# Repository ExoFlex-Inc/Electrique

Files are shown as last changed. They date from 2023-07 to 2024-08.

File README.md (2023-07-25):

# ExoFlex Électrique

ExoFlex Électrique est la référence à toutes les questions en lien avec les composantes et les schémas électriques.

## Description des capteurs

### Capteur de pression

Les capteurs de pression seront essentiellement utilisé avec les sangles qui seront conçues par l'équipe mécanique. Ce capteur va permettre de vérifier la pression entre la sangle et la jambe du patient afin de procurer un confort à l'utilisateur.

### IMU

L'IMU utilisé aura un accéléromètre et un gyroscope d'intégré à celui-ci. Ce capteur va nous permettre de spécifier des repères pour déterminer les positions cibles à atteindre lors des étirements. Le capteur qui sera utilisé pour le banc de test sera le MPU6050 fabriqué par DFROBOT.



- La tension opérationnelle sera de 3 à 5V (Vin)
- Mise à la terre (GND)
- Communication i2c (sda et scl)
- interrupt(INT)

### Capteur de fin de course

Ces capteurs seront utilisés pour arrêter les mouvements du robot si jamais il vient à dépasser la limite physique imposé. Ici on utilise des limit switch avec le numéro de modèle: SPDT 1NO 1NC fabriqué par InduSKY.



### Potentiomètre

Les potentiomètres rotatifs vont nous servir à déterminer l'angle des joints, afin de faire un suivit du mouvement du robot. Ici on utilise les potentiomètres fabriqué par OSEPP ELECTRONICS.



## Descriptions des actuateurs

à remplir

## Overview schéma électrique et conception PCB

à remplir

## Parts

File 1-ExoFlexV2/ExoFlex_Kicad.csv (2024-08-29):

Comment | Designator | Footprint | LCSC
10uF 10V X7R | C1,C29,C30,C31,C32,C33,C34,C35,C36,C37,C38,C39,C40,C41,C47,C48,C49,C85 | Capacitor_SMD:C_0805_2012Metric
47nF 50V X7R | C10 | Capacitor_SMD:C_1206_3216Metric
1uF 10% 20V | C11,C213,C214 | FootPrintLib:CAPMP3216X180N
47uF 10V X5R | C13,C14 | Capacitor_SMD:C_0805_2012Metric
330uF 10% 10V | C15,C16 | FootPrintLib:CAPMP7.6X4.3_3.1N_KEM
10nF 50V | C17,C18,C19,C20,C21,C22,C23,C24,C25,C26,C27,C28,C42,C43,C44,C45,C46,C50,C51,C52,C53,C54,C61,C62,C69,C70,C77,C78 | Capacitor_SMD:C_0805_2012Metric
220uF 20% 50V | C2 | FootPrint:CAP_EEHZS1H221P
100uF 20% 35V | C3,C5,C12 | FootPrintLib:CAP_K1V101P_PAN
33uF 50V X7R | C4 | FootPrintLib:CAPC6153X500N
0,1uF | C55,C56,C57,C58,C59,C60,C71,C72,C73,C74,C75,C76,C87,C88,C89,C90,C91,C92,C103,C104,C105,C106,C107,C119,C120,C121,C122,C123,C133,C134,C135,C136,C137,C147,C148,C149,C150,C151,C161,C162,C163,C164,C165,C166,C167,C168,C169,C170,C171,C172,C173,C174,C175,C176,C177,C178,C179,C180,C181,C182,C183,C184,C185,C186,C187,C188,C189,C190,C191,C192,C193,C194,C195,C196,C197,C198,C199,C200,C201,C202,C203,C204,C205,C206,C207,C208,C209,C210,C211,C212,C215,C216 | Capacitor_SMD:C_0402_1005Metric
2.2uF 50V X5R | C6 | Capacitor_SMD:C_0805_2012Metric
1uF | C63,C64,C65,C66,C67,C68,C79,C80,C81,C82,C83,C84,C95,C96,C97,C98,C99,C100,C111,C112,C113,C114,C115,C126,C127,C128,C129,C130,C140,C141,C142,C143,C144,C154,C155,C156,C157,C158 | Capacitor_SMD:C_0402_1005Metric
4,7uF 35V X7R | C7,C8 | Capacitor_SMD:C_0805_2012Metric
0.47UF 16V X7R | C9 | Capacitor_SMD:C_0805_2012Metric
SHOTT 30V 12A | D1,D2 | FootPrint:DIO_SS12P2L-M3_86A
LED | D115,D116,D117,D118 | FootPrintLib:WL-SMCW_0603
TVS | D3,D4,D5,D6,D7,D8,D9,D10,D11,D12,D13,D14,D15,D16,D17,D18,D19,D20,D21,D22,D23,D24,D25,D26,D27,D28,D29,D30,D31,D32,D33,D34,D35,D36,D37,D38,D39,D40,D41,D42,D43,D44,D45,D46,D47,D48,D49,D50,D51,D52,D53,D54,D55,D56,D57,D58,D59,D60,D61,D62,D63,D64,D65,D66,D67,D68,D69,D70,D71,D72,D73,D74,D75,D76,D77,D78,D79,D80,D81,D82,D83,D84,D85,D86,D87,D88,D89,D90,D91,D92,D93,D94,D95,D96,D97,D98,D99,D100,D101,D102,D103,D104,D105,D106,D107,D108,D109,D110,D111,D112,D113,D114,D119,D120,D121,D122,D123,D124,D125,D126,D127,D128,D129,D130,D131,D132,D133,D134,D135,D136,D137,D138,D139,D140,D141,D142,D143,D144,D145,D146,D147,D148,D149,D150,D151,D152,D153,D154,D155,D156,D157,D158,D159,D160,D161,D162,D163,D164,D165,D166,D167,D168,D169,D170,D171,D172,D173,D174,D178,D179,D180,D181,D182,D183,D184,D185 | FootPrint:DPY2_TEX
Fuse | F1 | FootPrint:696108003002
Fiducial | FID1,FID2,FID3 | Fiducial:Fiducial_0.5mm_Mask1.5mm
MH | H2,H3,H4,H5,H6,H7,H8,H9,H10,H11,H12,H13,H14 | MountingHole:MountingHole_4.3mm_M4
14 AWG | J1,J3,J81 | FootPrintLib:PHOENIX_1755736
30POS | J10 | FootPrintLib:SAMTEC_SSW-115-01-G-D
10POS | J11 | FootPrintLib:SAMTEC_SSW-110-01-G-D
34POS | J12 | FootPrintLib:SAMTEC_SSW-117-01-G-D
3POS | J13,J14,J15,J19,J20,J21,J22,J23,J24,J53,J54 | FootPrint:CON_39301039
39281083 | J16,J17,J18 | FootPrint:MOLEX_0039281083
Jumper | J2,J5,J6,J55,J56,J58,J59,J66,J67,J68,J69,J70,J72,J73,J74,J82,J84,J85,J86,J87,J88,J89,J90,J91,J92,J93,J94,J95,J96,J97,J98,J99,J100,J101,J102,J103,J104,J105,J106,J107,J108,J109,J110,J111,J115,J116,J117,J118,J119,J120,J121,J122,J123,J124,J125,J126,J127,J131,J132 | Connector_PinHeader_2.54mm:PinHeader_1x03_P2.54mm_Vertical
2POS | J4,J25,J26,J27,J28,J29,J30,J31,J32,J33,J34,J35,J36,J37,J38,J46,J47,J48,J52 | FootPrintLib:CON_39281023
4POS | J39,J40,J41,J42,J49,J50,J51 | FootPrint:CON_39301049
5POS | J43,J44,J45 | FootPrint:CON_39302050
6POS | J57 | Connector_PinSocket_2.54mm:PinSocket_1x06_P2.54mm_Vertical
Tulip Conn | J60,J61,J62,J63,J64,J65,J75,J76,J77,J78,J79,J80 | Connector_PinSocket_2.54mm:PinSocket_1x02_P2.54mm_Vertical
Jumper 5,2A | J7,J71 | Connector_PinHeader_2.54mm:PinHeader_1x03_P2.54mm_Vertical
USB-C | J8 | FootPrintLib:MOLEX_1054500101
16POS | J9 | FootPrintLib:SAMTEC_SSW-108-01-G-D
Relay | K1 | FootPrint:UD2_NU_KEM-L
1uH 20% 2,3A | L1,L2 | Inductor_SMD:L_1210_3225Metric
10uH 10% 150mA | L3 | FootPrintLib:INDC2012X145N
MOSFET 20V 200mA | Q1 | FootPrint:DIO_RB558WMF_ROM
10K 1% 1/10W | R1,R4,R49,R50,R51,R82,R83,R84,R85,R86,R87,R92,R93,R94,R98,R99,R100,R101,R102,R103,R110,R115,R116,R121,R122,R123,R124,R146,R147,R148,R188,R189,R190,R191,R192,R193,R206,R207,R208,R215,R216,R217,R218,R219,R220,R221,R233,R234,R235,R236,R237,R238,R239,R240,R241,R242,R243,R245,R246,R247,R248,R249,R259,R260,R261,R262,R265,R266,R273,R274,R275,R276,R284 | Resistor_SMD:R_0603_1608Metric
1K 1% 1/10W | R11,R12,R13,R14,R15,R16,R17,R18,R19,R20,R21,R22,R23,R24,R29,R30,R31,R283 | Resistor_SMD:R_0603_1608Metric
165 1% 1/8W | R114,R120 | Resistor_SMD:R_0805_2012Metric
464 1% 1/8W | R119,R168 | Resistor_SMD:R_0805_2012Metric
2,2k 1% 1/2W | R184 | Resistor_SMD:R_0805_2012Metric
210 1% 1/8W | R197,R198,R199,R200,R201,R202 | Resistor_SMD:R_0805_2012Metric
5.1K 1% 1/10W | R2,R76,R104,R105,R106,R107,R108,R109,R111,R112,R117,R118,R125,R126,R127,R128,R149,R150,R151,R169,R176,R177,R285 | Resistor_SMD:R_0603_1608Metric
200k 1% 1/8W | R223,R226,R229 | Resistor_SMD:R_0805_2012Metric
100K 1% 1/10W | R25,R26,R27,R28,R32,R33,R34,R53,R54,R56,R71,R72,R75,R88,R90,R91,R113,R131,R132,R133,R134,R135,R136,R140,R141,R142,R143,R144,R145,R152,R153,R154,R158,R159,R160,R161,R162,R163,R166,R167,R170,R171,R172,R173,R174,R175,R182,R183,R194,R195,R196,R244,R252,R253,R254,R263,R264,R277,R278,R282 | Resistor_SMD:R_0603_1608Metric
200k 5% 1/8W | R35,R36,R37 | Resistor_SMD:R_0805_2012Metric
910k 0,1% 1/8W | R38,R39,R45,R59,R60,R66 | Resistor_SMD:R_0805_2012Metric
0Ω | R3,R8,R9,R10,R40,R41,R42,R43,R44,R48,R61,R62,R63,R64,R65,R67,R79,R80,R81,R129,R130,R137,R138,R139,R155,R156,R157,R164,R165,R181,R186,R187,R203,R204,R205,R212,R213,R214,R224,R227,R230,R232,R257,R258,R271,R272,R279,R280 | Resistor_SMD:R_0805_2012Metric
270 0,1% 1/4W | R46 | Resistor_SMD:R_0805_2012Metric
270 1% 1/4W | R47,R185 | Resistor_SMD:R_0805_2012Metric
5.49k 1% 1/8W | R5 | Resistor_SMD:R_0805_2012Metric
3.3k 1% 1/8W | R52,R68,R69,R70,R77,R78,R95,R96,R97,R178,R179,R180,R209,R210,R211,R222,R231,R250,R251,R255,R256,R267,R268,R269,R270 | Resistor_SMD:R_0805_2012Metric
530 0.5% 1/8W | R55 | Resistor_SMD:R_0805_2012Metric
270 1% 1/8W | R57 | Resistor_SMD:R_0805_2012Metric
820 1% 1/8W | R58 | Resistor_SMD:R_0805_2012Metric
100 1% 1/8W | R6 | Resistor_SMD:R_0805_2012Metric
8.66k 1% 1/8W | R7 | Resistor_SMD:R_0805_2012Metric
240 1% 1/8W | R73 | Resistor_SMD:R_0805_2012Metric
360 1% 1/8W | R74,R281 | Resistor_SMD:R_0805_2012Metric
100k 1% 1/8W | R89,R225,R228 | Resistor_SMD:R_0805_2012Metric
Trim 10k | RV1,RV2,RV3,RV4,RV5,RV6,RV7,RV27 | FootPrint:TRIM_3362P-1-103LF
TestPoint | TP1,TP2,TP3,TP4,TP5,TP6,TP7,TP8,TP9,TP10,TP11,TP12,TP13,TP14,TP15,TP16,TP17,TP18,TP19,TP20,TP21,TP22,TP23,TP24,TP25,TP26,TP27,TP28,TP29,TP30,TP31,TP32,TP37,TP38,TP39,TP40,TP41,TP42,TP46,TP59,TP60,TP61,TP62,TP63,TP64,TP68,TP81,TP84,TP85,TP92,TP93,TP94,TP95,TP96,TP97,TP98,TP99,TP103,TP107,TP108,TP109,TP110,TP111,TP112,TP113,TP117,TP118,TP119,TP120,TP121,TP124,TP125,TP126,TP127,TP128 | FootPrint:KEYSTONE_5005
TVS 24V | U1,U14 | FootPrint:SOT-23-3_DBZ_TEX
XNOR Gate | U10 | FootPrintLib:SC-74A_SOT753_NEX
MUX 8:1 | U12,U13,U121,U122 | FootPrint:SOT403-1_NXP
LDO -5VA | U123 | FootPrintLib:T03B_TEX
LDO 5VA | U124 | FootPrintLib:T03B_TEX
OR GATE 3IN | U15,U16,U32,U49,U50,U53 | FootPrintLib:SOT95P280X145-6N
OP_AMP2 | U17,U18,U19,U23,U24,U31,U33,U34,U35,U36,U37,U38,U39,U40,U41,U56,U57 | FootPrintLib:SOIC127P599X175-8N
Shott 100V | U2 | FootPrint:D2PAK_STM
COMP | U20,U21,U22,U28,U29,U30,U67,U68,U69,U79,U80,U81,U85,U86 | FootPrint:DGK8
INST OP-AMP | U25,U26,U27 | FootPrint:D0008A_SOIC_TEX
Inverter | U3,U11,U42,U43,U44,U45,U46,U47,U48,U51,U52,U58,U59 | FootPrint:SN74LVC3G14DCUT
SR-Latch | U4 | FootPrintLib:SOP65P640X120-16N
DCDC24V/8V | U5 | FootPrintLib:PTN78060WAD
DCDC24V/5V NUM | U6 | FootPrint:NDY0011A_L
AND Gate | U60,U62,U63,U64,U65,U70,U71,U76,U77,U82,U83 | FootPrint:SOT95P270X145-5N
DCDC 24V/-7,8V ANA | U7 | FootPrintLib:PTN78000
OR Gate 8 | U8,U9,U54,U55 | FootPrint:D14

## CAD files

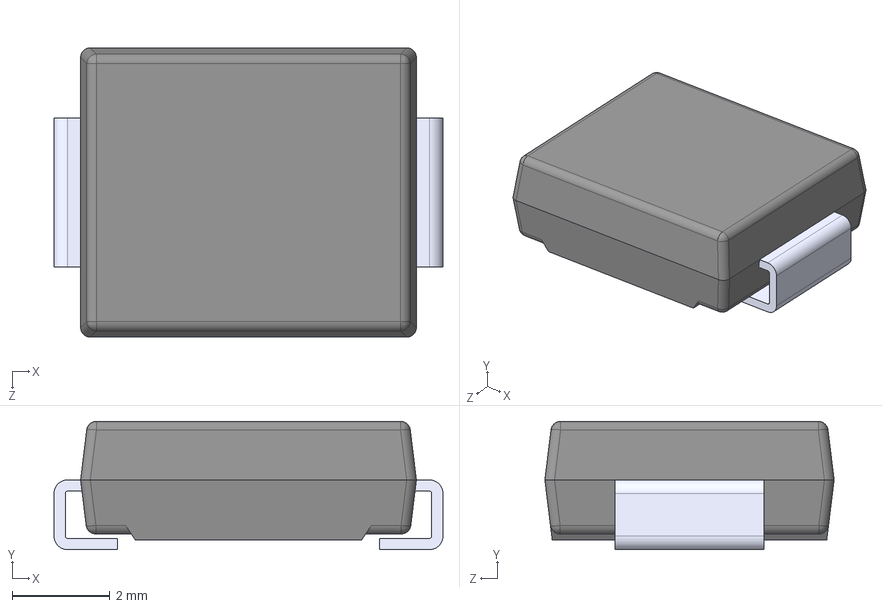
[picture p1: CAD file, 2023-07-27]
1-ExoFlexV2/DIOM6859X262N/DIOM6859X262N.step
7.94 x 2.62 x 5.90 mm

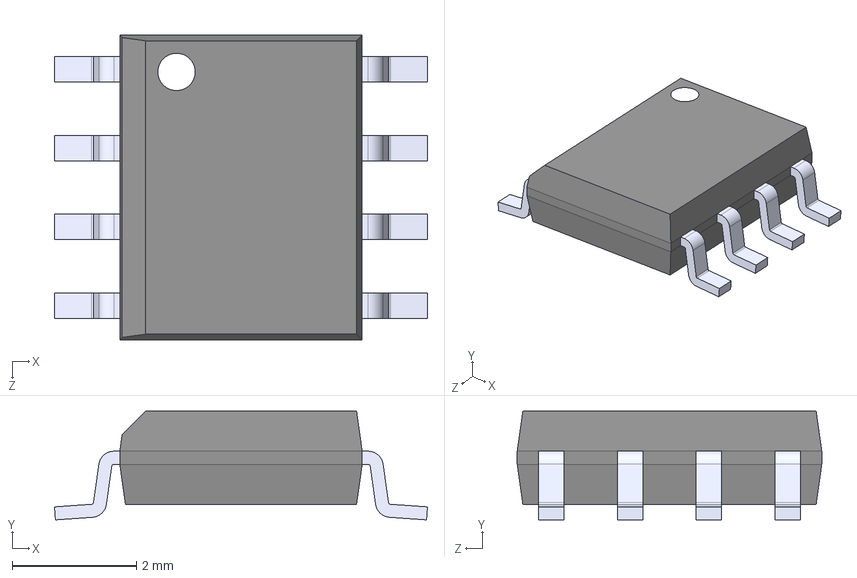
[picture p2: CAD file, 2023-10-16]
ACS712/ACS712.step
6.00 x 1.75 x 4.90 mm

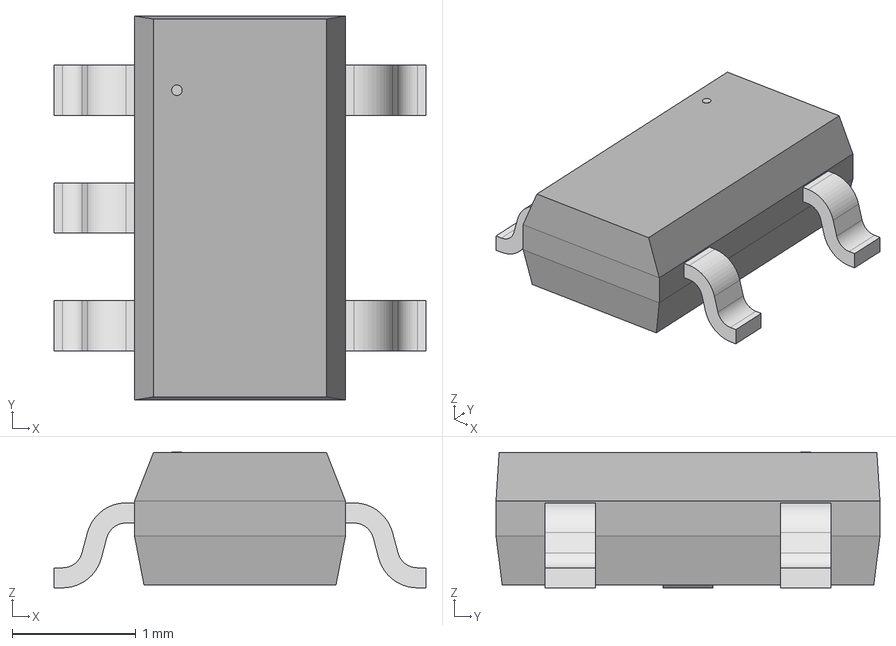
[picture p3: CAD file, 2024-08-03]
1-ExoFlexV2/1-STEP/SC-74A_SOT753_NEX.step
3.00 x 3.10 x 1.09 mm

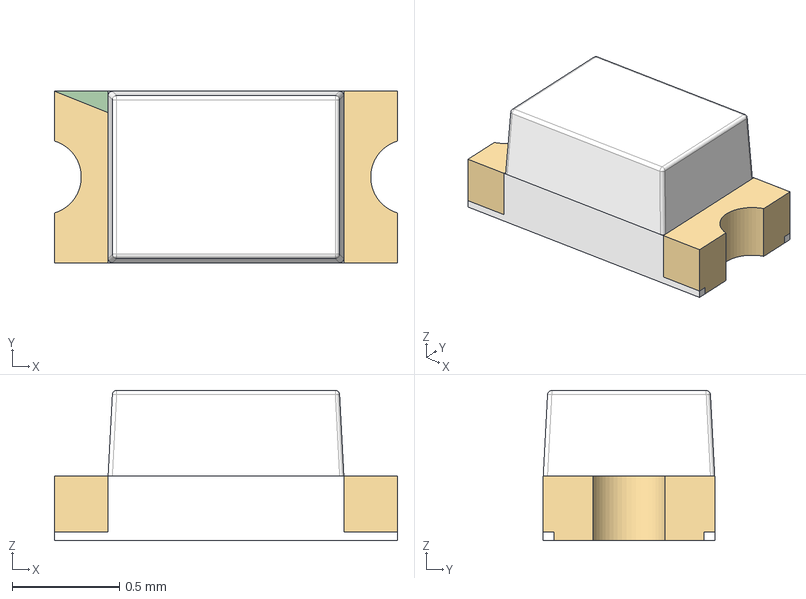
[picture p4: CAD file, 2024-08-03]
1-ExoFlexV2/1-STEP/WL-SMCW_0603.step
1.60 x 0.8 x 0.7 mm

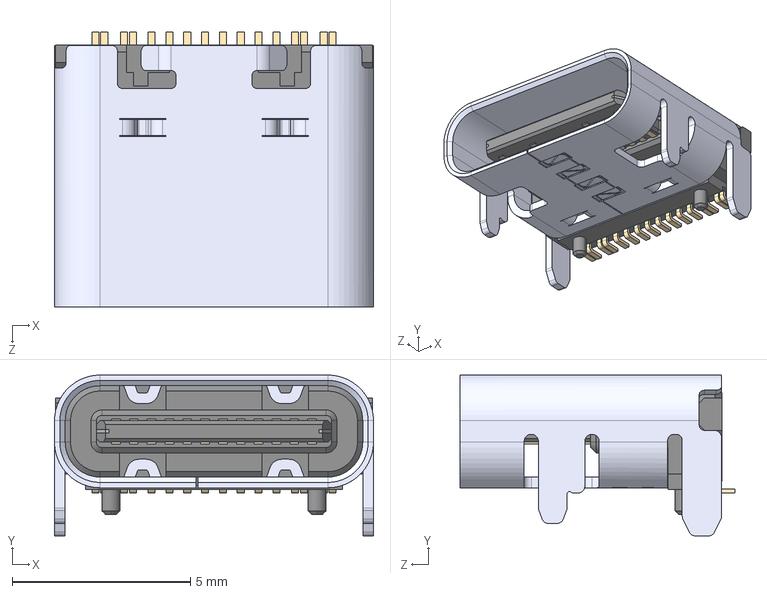
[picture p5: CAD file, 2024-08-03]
1-ExoFlexV2/1-STEP/USB4105GFA120.step
8.94 x 4.51 x 7.71 mm

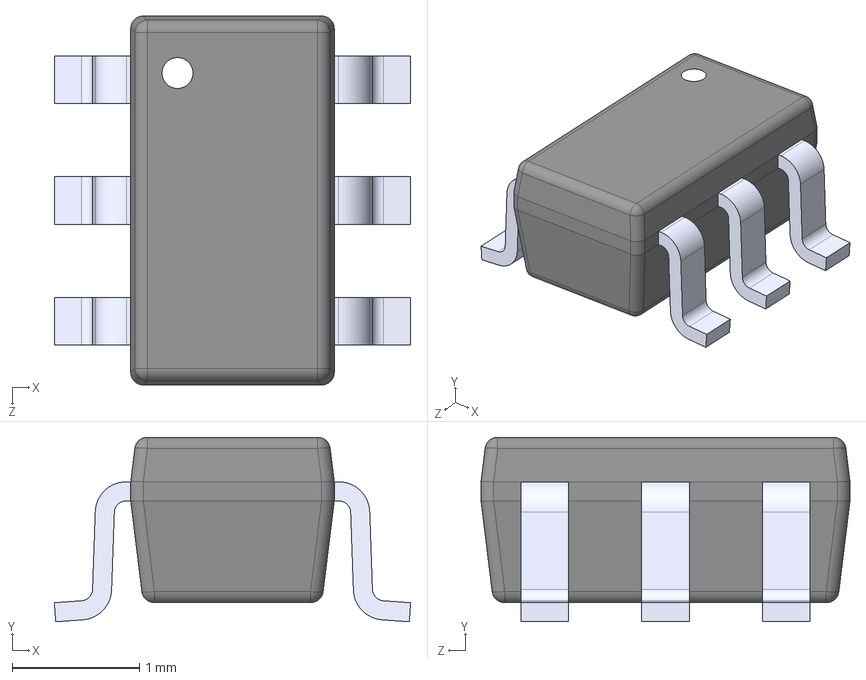
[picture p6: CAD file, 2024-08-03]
1-ExoFlexV2/1-STEP/SN74LVC1G332DBVR.step
2.80 x 1.45 x 2.90 mm

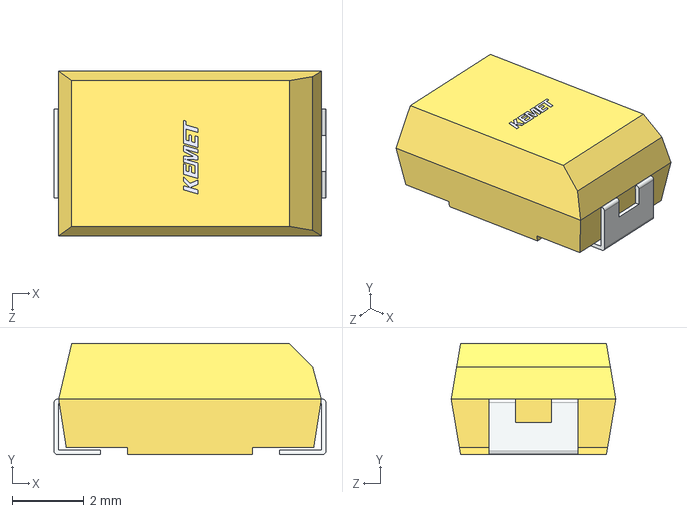
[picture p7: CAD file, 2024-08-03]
1-ExoFlexV2/1-STEP/CTSM_TCM2NK_7343_L7.6W4.6H3.1T0.13S1.3F2.5A3.6B0.65E3.5G3.5P0.9R1X0.2.step
7.60 x 3.11 x 4.60 mm

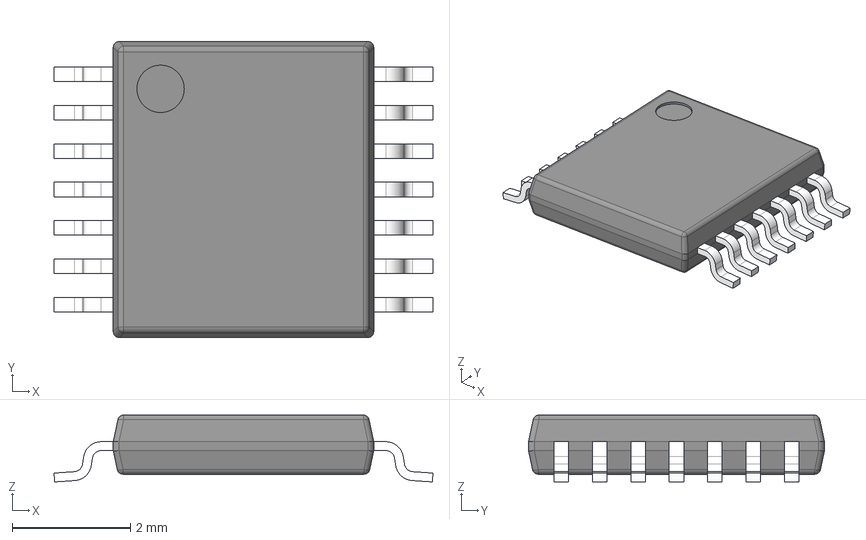
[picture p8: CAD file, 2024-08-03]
1-ExoFlexV2/1-STEP/PW0014A.stp
6.40 x 5.00 x 1.13 mm
BODY-TSSOP
LEAD-TSSOP x 14
PIN1

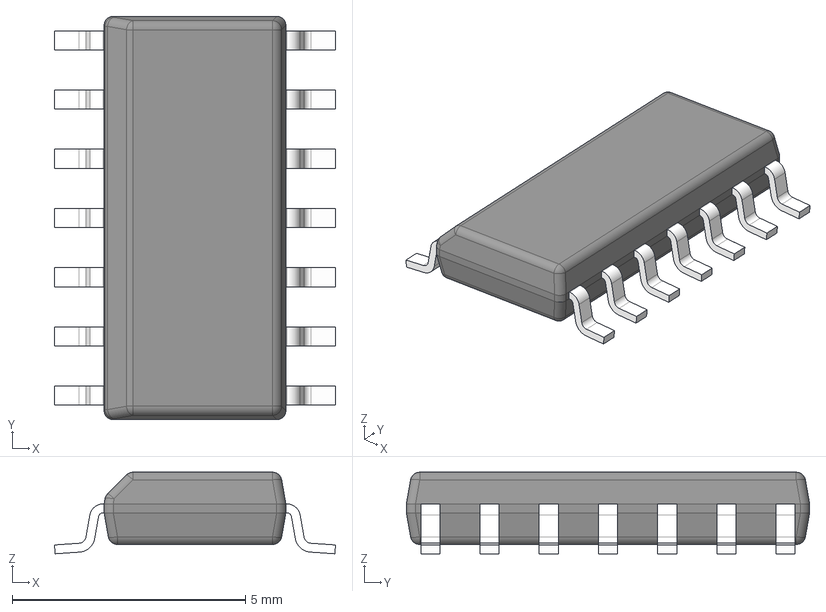
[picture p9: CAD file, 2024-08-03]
1-ExoFlexV2/1-STEP/D0014A.stp
6.03 x 8.65 x 1.75 mm
BODY-SO
LEAD-SO x 14
PIN1-ID

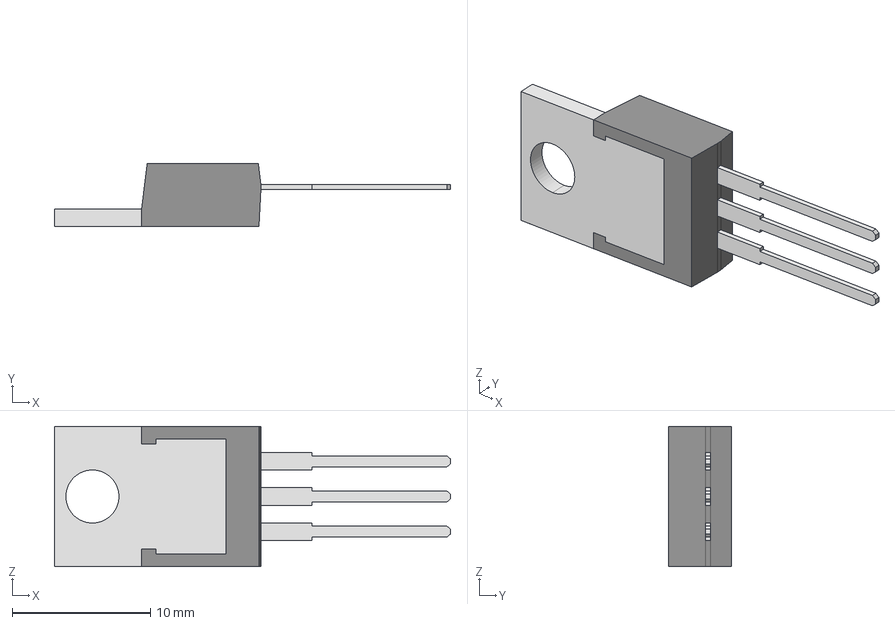
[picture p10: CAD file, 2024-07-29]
1-ExoFlexV2/1-STEP/NDE0003B.stp
28.7 x 4.57 x 10.2 mm
T03B_BODY
T03B_LEAD x 3
T03B_HS

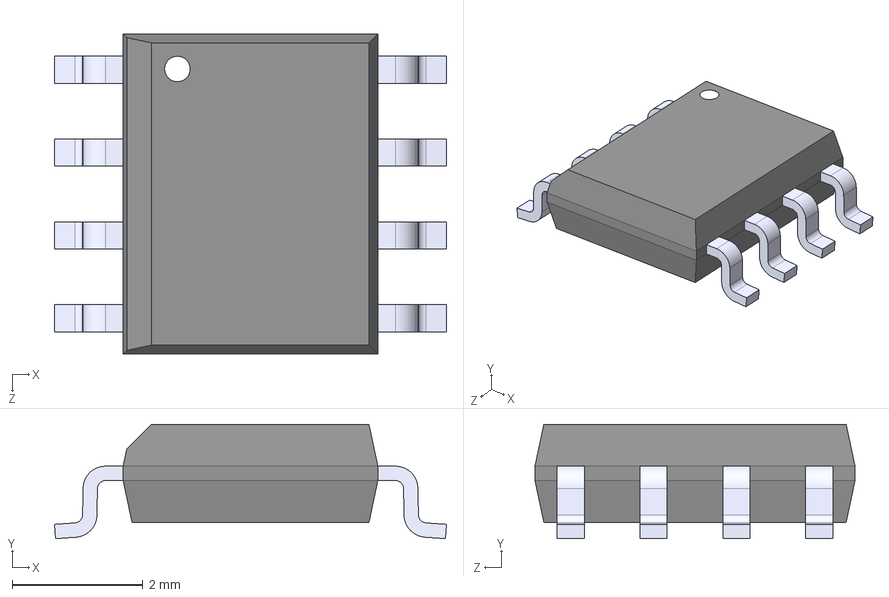
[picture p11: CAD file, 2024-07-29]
1-ExoFlexV2/1-STEP/TL072IDR.step
6.00 x 1.75 x 4.90 mm

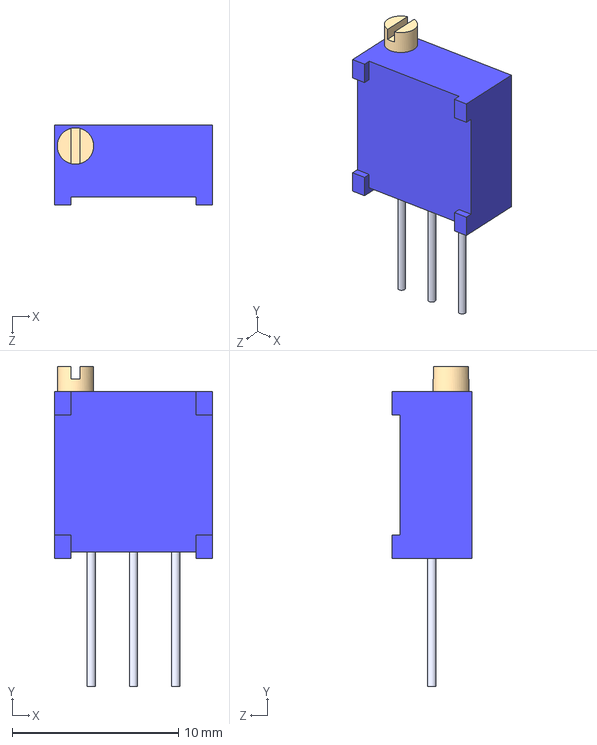
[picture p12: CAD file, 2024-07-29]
1-ExoFlexV2/1-STEP/3296W-1-501LF.step
9.53 x 19.3 x 4.83 mm

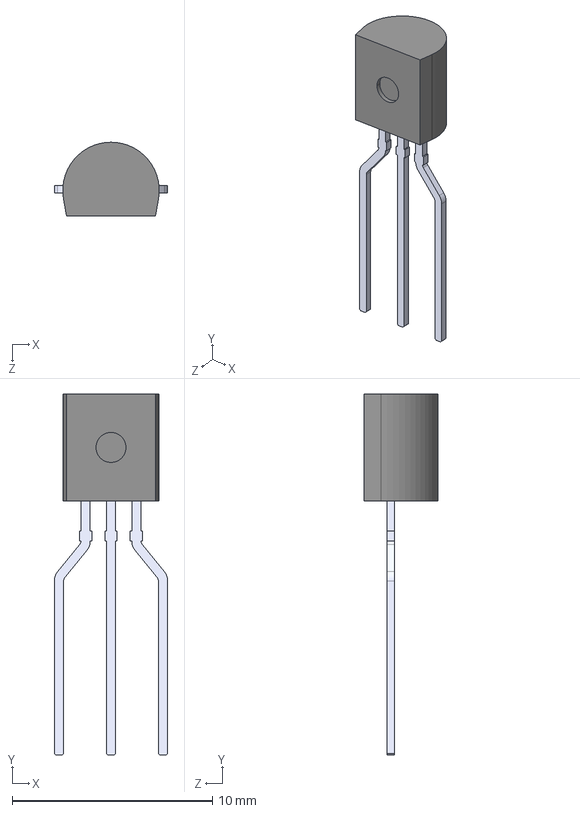
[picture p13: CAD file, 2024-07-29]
1-ExoFlexV2/1-STEP/LM337LZ_LFT3.step
5.67 x 18.0 x 3.68 mm

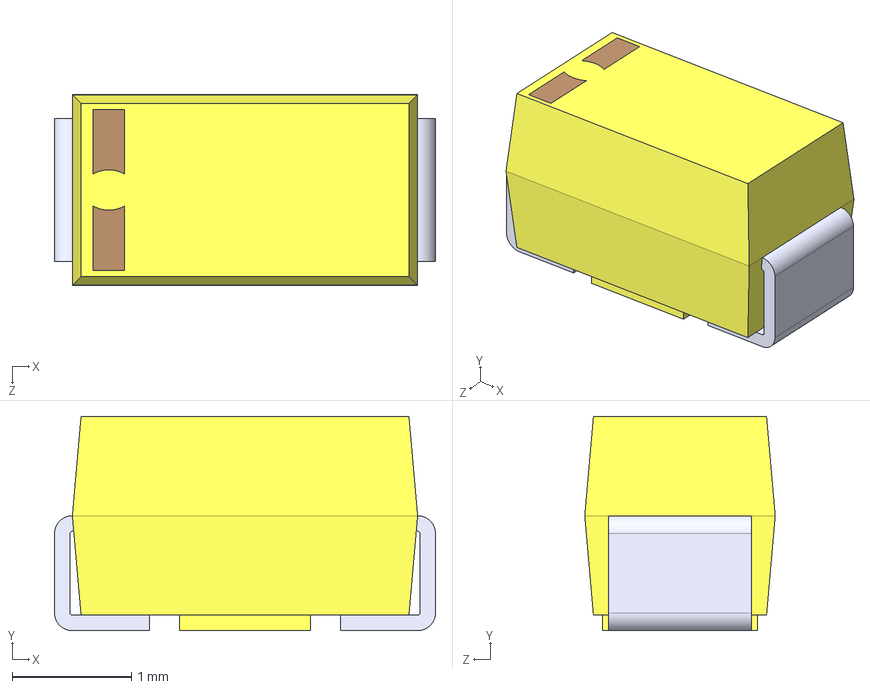
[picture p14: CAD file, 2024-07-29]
1-ExoFlexV2/1-STEP/T491A105K020AT.step
3.20 x 1.80 x 1.60 mm

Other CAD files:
1-ExoFlexV2/1-STEP/SSW-117-01-G-D.step
1-ExoFlexV2/1-STEP/LQH2HPN4R7MDRL.step
1-ExoFlexV2/1-STEP/SSW-108-01-G-D.step
1-ExoFlexV2/1-STEP/SSW-110-01-G-D.step
1-ExoFlexV2/1-STEP/0039281083.step
1-ExoFlexV2/1-STEP/039281023.stp
1-ExoFlexV2/1-STEP/039301039.stp
1-ExoFlexV2/1-STEP/039301049.stp
1-ExoFlexV2/1-STEP/039302050.stp
1-ExoFlexV2/1-STEP/1054500101.step
1-ExoFlexV2/1-STEP/1751099.step
1-ExoFlexV2/1-STEP/1751109.step
1-ExoFlexV2/1-STEP/1751112.step
1-ExoFlexV2/1-STEP/1751125.step
1-ExoFlexV2/1-STEP/1755532.step
1-ExoFlexV2/1-STEP/1755736.step
1-ExoFlexV2/1-STEP/1755749.step
1-ExoFlexV2/1-STEP/1755752.step
1-ExoFlexV2/1-STEP/1755765.step
1-ExoFlexV2/1-STEP/282837-2.step
1-ExoFlexV2/1-STEP/282837-3.step
1-ExoFlexV2/1-STEP/3362P-1-102LF.step
1-ExoFlexV2/1-STEP/5005.step
1-ExoFlexV2/1-STEP/696108003002.stp
1-ExoFlexV2/1-STEP/801-87-002-10-001101.STEP
1-ExoFlexV2/1-STEP/86A.STEP
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

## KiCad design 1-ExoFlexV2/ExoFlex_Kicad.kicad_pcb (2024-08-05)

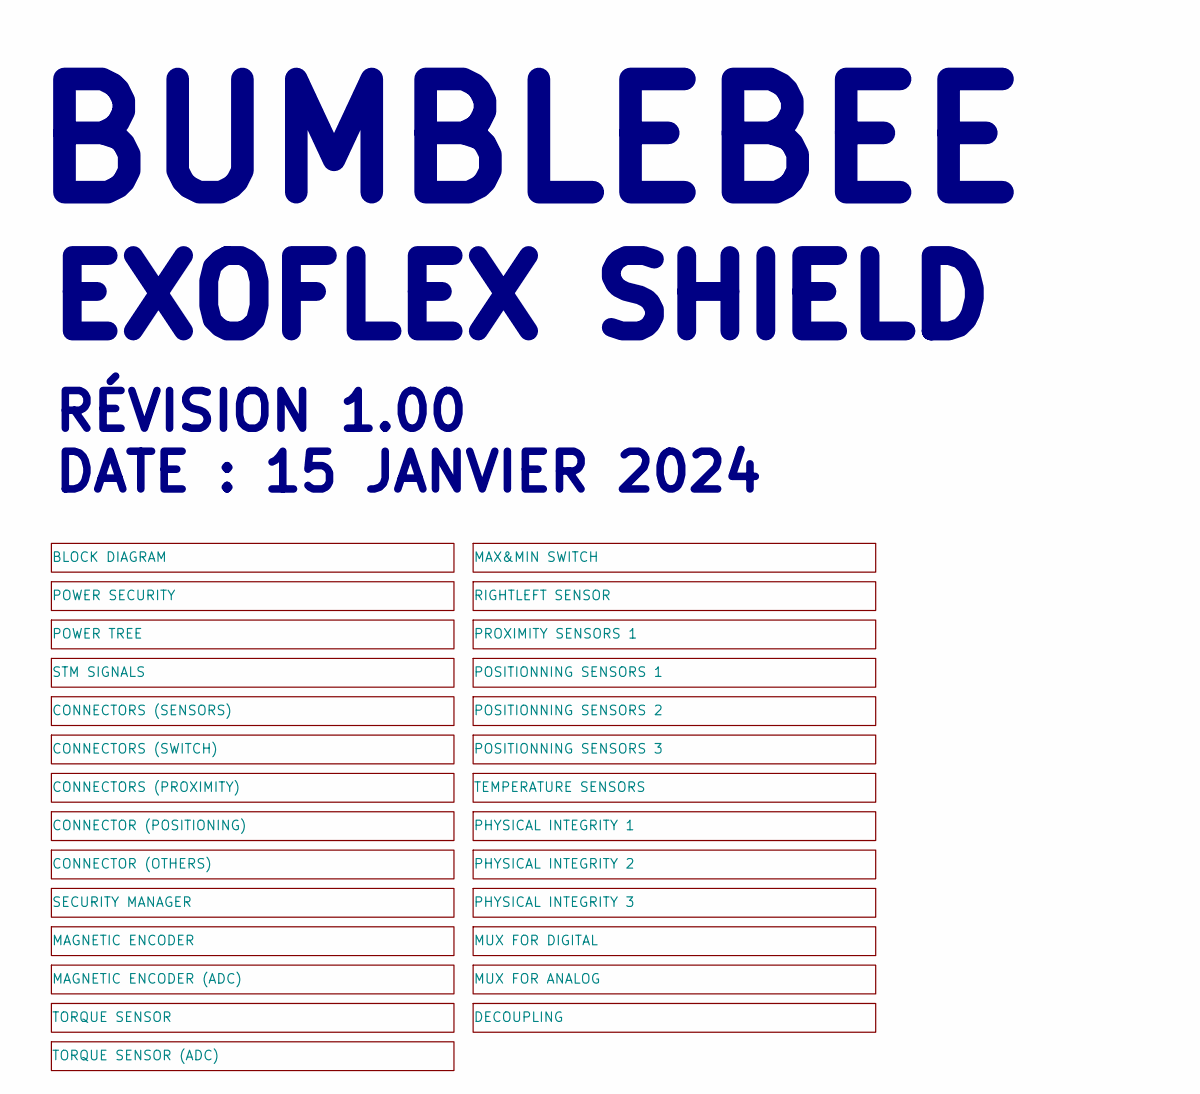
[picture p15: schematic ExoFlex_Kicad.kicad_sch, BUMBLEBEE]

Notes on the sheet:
BUMBLEBEE
EXOFLEX SHIELD
RÉVISION 1.00 DATE : 15 JANVIER 2024

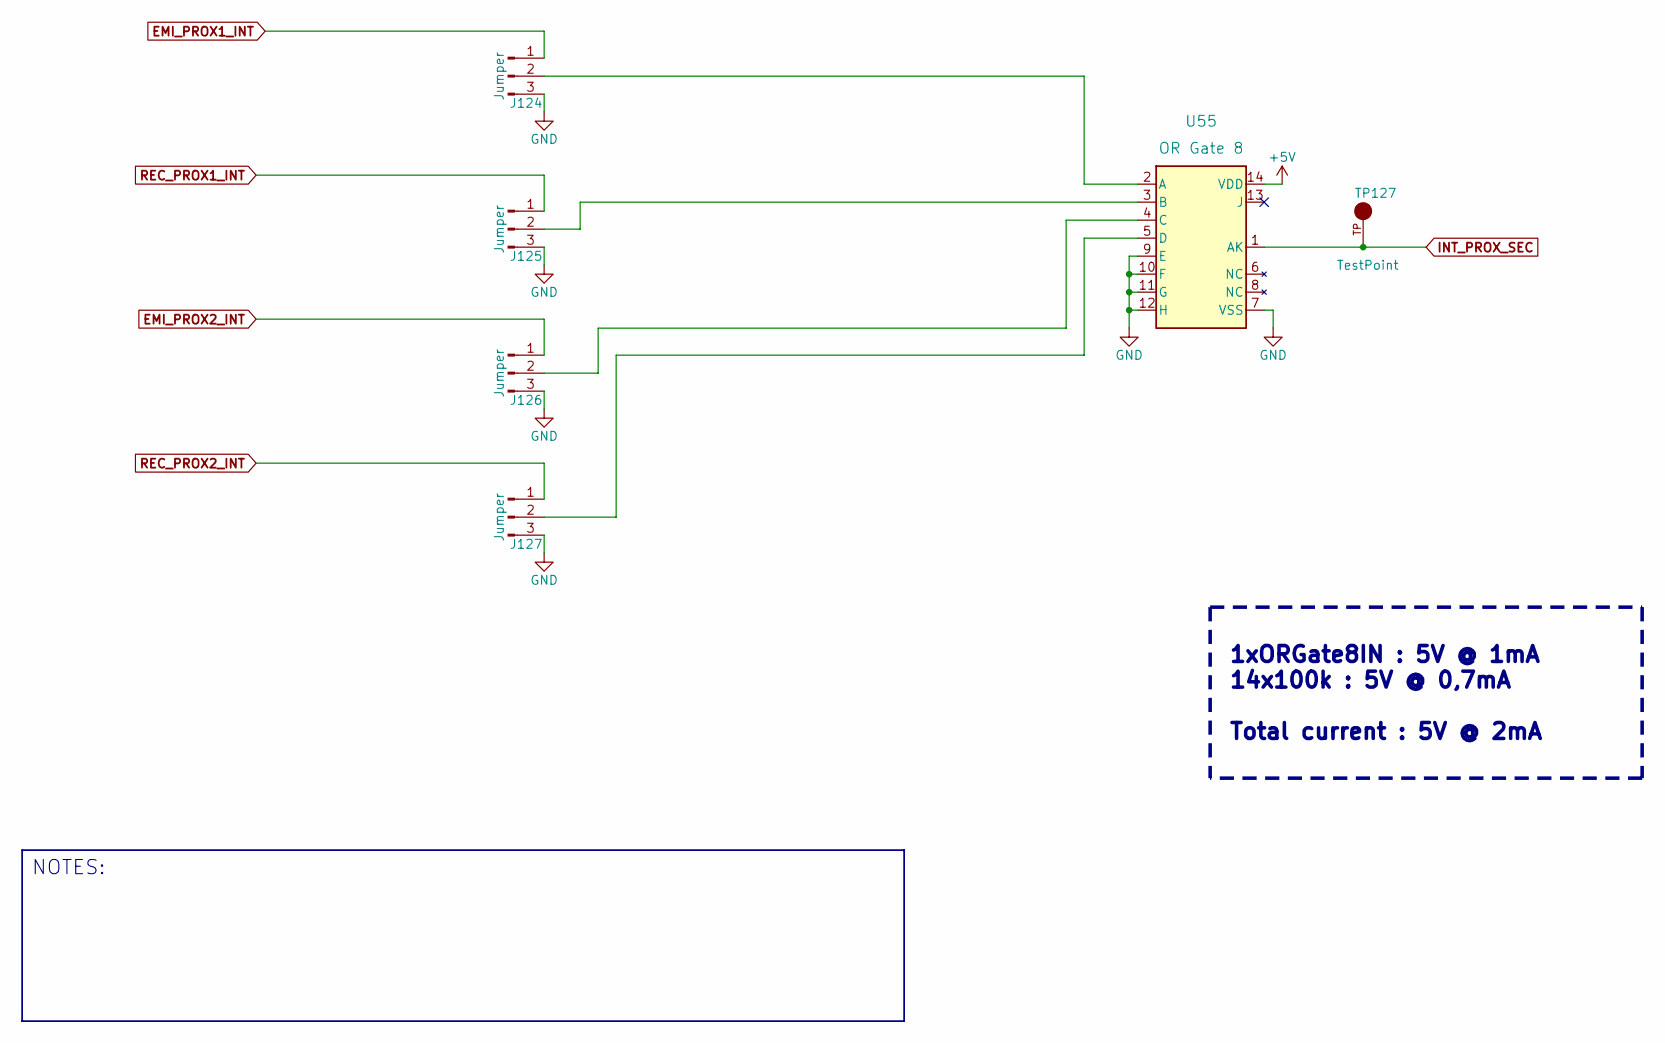
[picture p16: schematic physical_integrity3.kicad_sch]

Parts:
J124, J125, J126, J127: Jumper; PinHeader_1x03_P2.54mm_Vertical; PART NUMBER 61300311121
TP127: TestPoint; KEYSTONE_5005; PART NUMBER 5005
U55: OR Gate 8; D14; PART NUMBER CD4078BM96

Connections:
+5V: U55.14 (VDD); also elsewhere on the board
EMI_PROX1_INT: J124.1; also elsewhere on the board
EMI_PROX2_INT: J126.1; also elsewhere on the board
GND: J124.3, J125.3, J126.3, J127.3, U55.7 (VSS), U55.9 (E), U55.10 (F), U55.11 (G), U55.12 (H); also elsewhere on the board
INT_PROX_SEC: TP127.TP, U55.1 (AK); also elsewhere on the board
unnamed: J124.2, U55.2 (A)
unnamed: J125.2, U55.3 (B)
unnamed: J126.2, U55.4 (C)
unnamed: J127.2, U55.5 (D)
REC_PROX1_INT: J125.1; also elsewhere on the board
REC_PROX2_INT: J127.1; also elsewhere on the board

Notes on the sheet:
1xORGate8IN : 5V @ 1mA 14x100k : 5V @ 0,7mA Total current : 5V @ 2mA
NOTES:

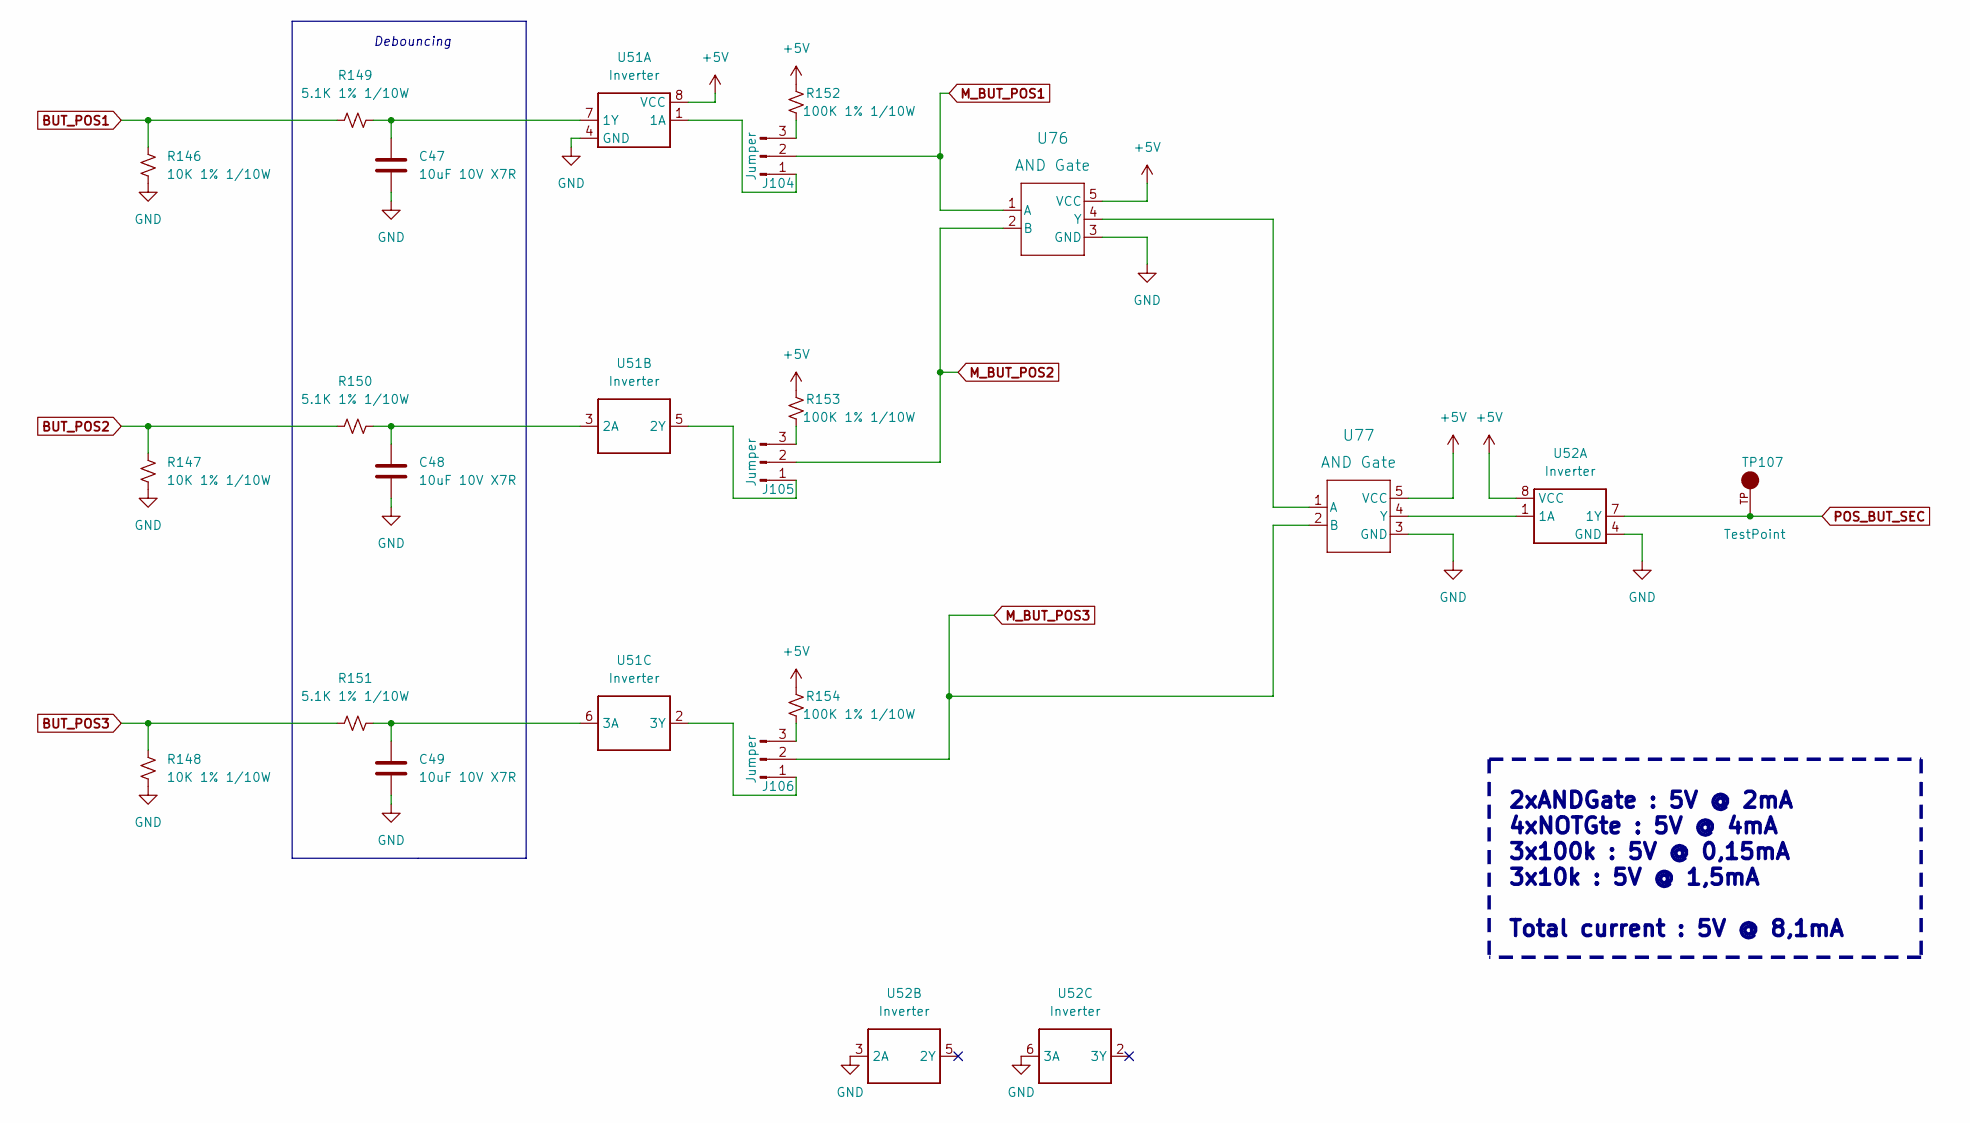
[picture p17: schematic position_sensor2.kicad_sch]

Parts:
C47, C48, C49: 10uF 10V X7R; C_0805_2012Metric; PART NUMBER GRM21BR71A106KA73L
J104, J105, J106: Jumper; PinHeader_1x03_P2.54mm_Vertical; PART NUMBER 61300311121
R146, R147, R148: 10K 1% 1/10W; R_0603_1608Metric; PART NUMBER ERJ-3EKF1002V
R149, R150, R151: 5.1K 1% 1/10W; R_0603_1608Metric; PART NUMBER ERJ-3EKF5101V
R152, R153, R154: 100K 1% 1/10W; R_0603_1608Metric; PART NUMBER ERJ-3EKF1003V
TP107: TestPoint; KEYSTONE_5005; PART NUMBER 5005
U51, U52: Inverter; SN74LVC3G14DCUT; PART NUMBER SN74LVC3G14DCUT
U76, U77: AND Gate; SOT95P270X145-5N; PART NUMBER SN74LVC1G08DBVR

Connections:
+5V: R152.2, R153.2, R154.2, U51.8 (VCC), U52.8 (VCC), U76.5 (VCC), U77.5 (VCC); also elsewhere on the board
BUT_POS1: R146.1, R149.1; also elsewhere on the board
BUT_POS2: R147.1, R150.1; also elsewhere on the board
BUT_POS3: R148.1, R151.1; also elsewhere on the board
GND: C47.2, C48.2, C49.2, R146.2, R147.2, R148.2, U51.4 (GND), U52.3 (2A), U52.4 (GND), U52.6 (3A), U76.3 (GND), U77.3 (GND); also elsewhere on the board
M_BUT_POS1: J104.2, U76.1 (A); also elsewhere on the board
M_BUT_POS2: J105.2, U76.2 (B); also elsewhere on the board
M_BUT_POS3: J106.2, U77.2 (B); also elsewhere on the board
unnamed: C47.1, R149.2, U51.7 (1Y)
unnamed: C48.1, R150.2, U51.3 (2A)
unnamed: C49.1, R151.2, U51.6 (3A)
unnamed: J104.1, U51.1 (1A)
unnamed: J104.3, R152.1
unnamed: J105.1, U51.5 (2Y)
unnamed: J105.3, R153.1
unnamed: J106.1, U51.2 (3Y)
unnamed: J106.3, R154.1
unnamed: U52.1 (1A), U77.4 (Y)
unnamed: U76.4 (Y), U77.1 (A)
POS_BUT_SEC: TP107.TP, U52.7 (1Y); also elsewhere on the board

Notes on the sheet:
2xANDGate : 5V @ 2mA 4xNOTGte : 5V @ 4mA 3x100k : 5V @ 0,15mA 3x10k : 5V @ 1,5mA Total current : 5V @ 8,1mA
Debouncing

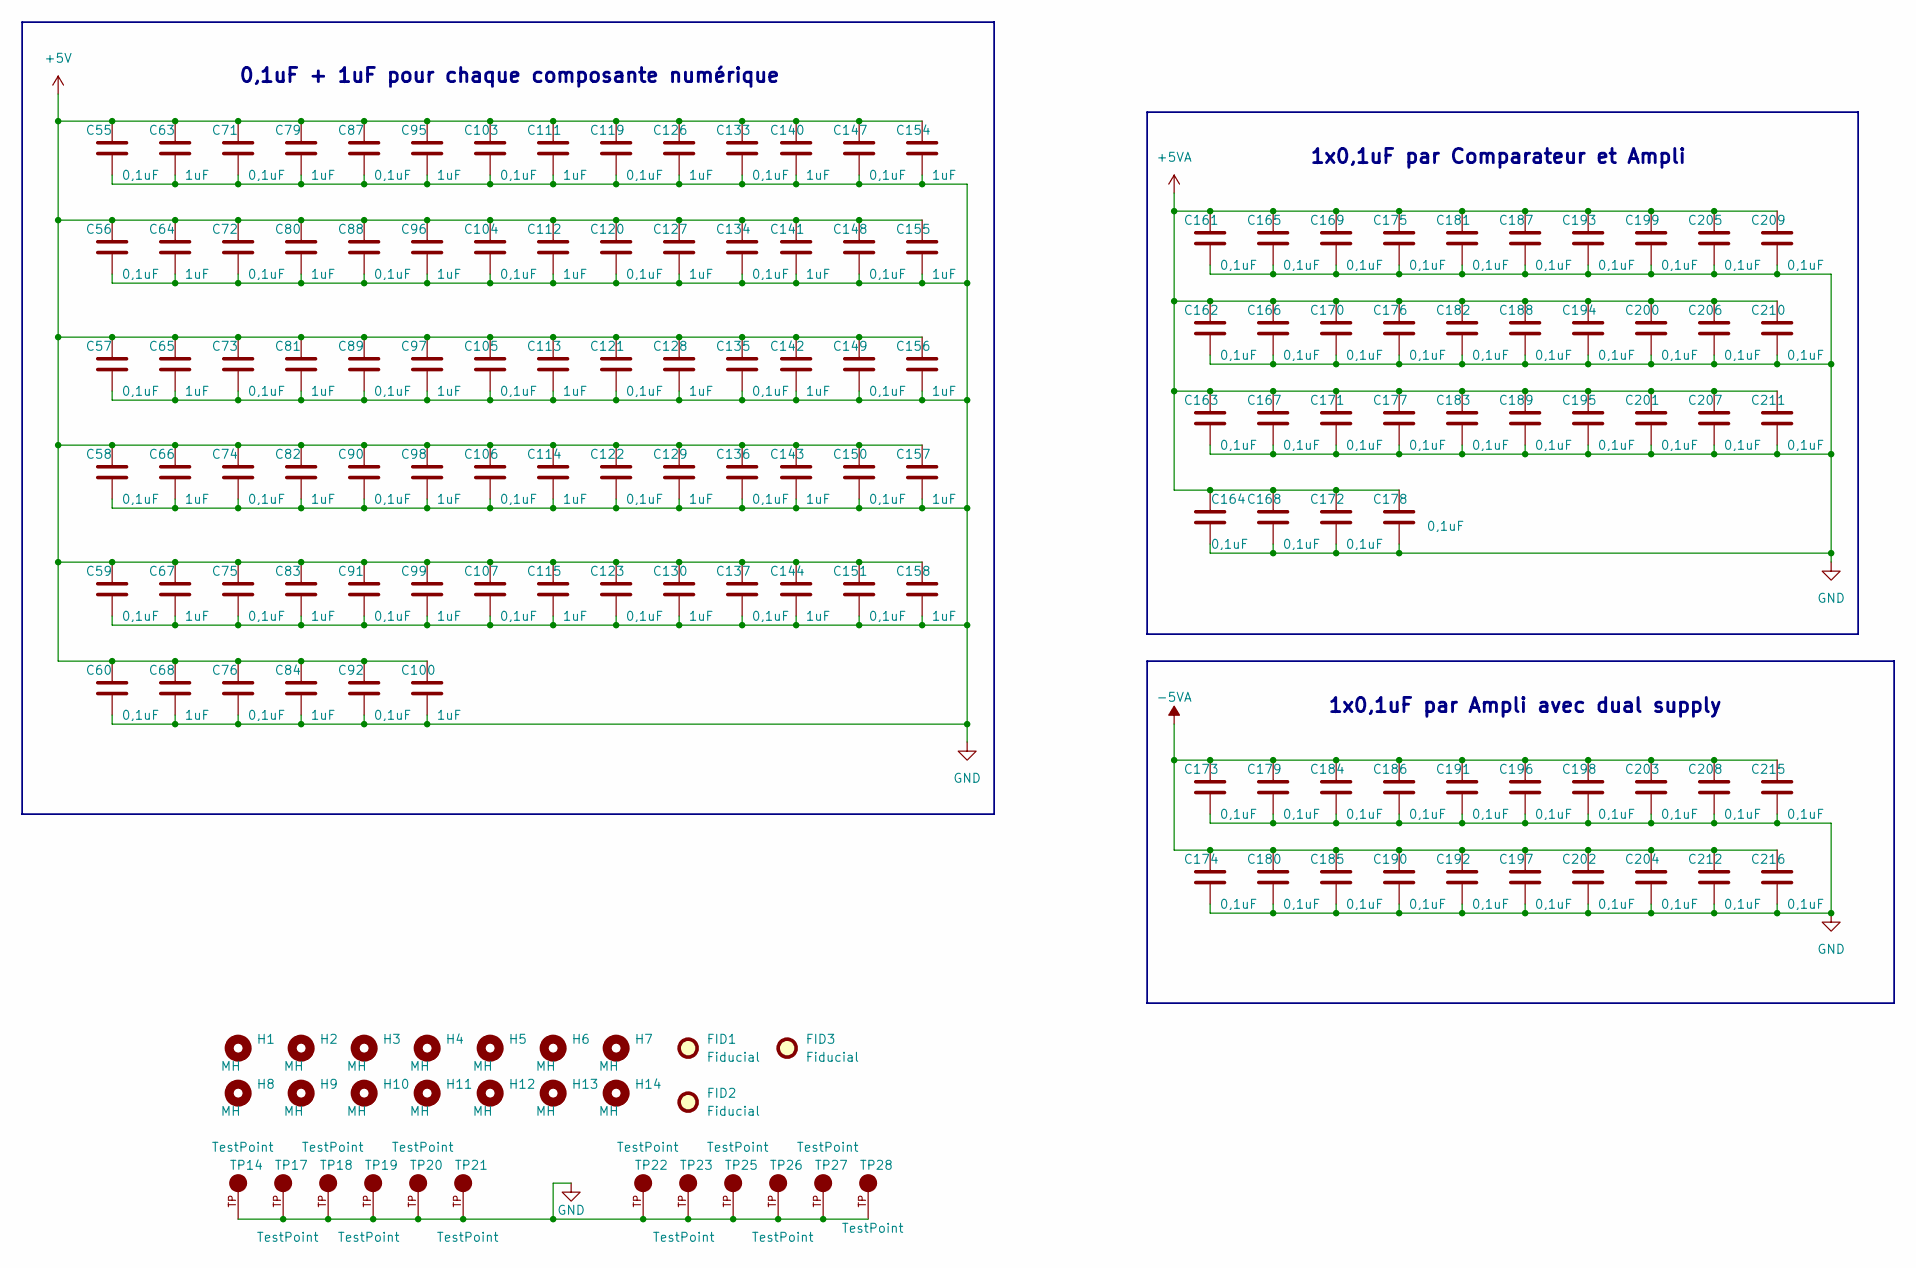
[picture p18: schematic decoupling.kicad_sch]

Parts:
C55, C56, C57, C58, C59, C60, C71, C72, C73, C74, C75, C76, C87, C88, C89, C90, C91, C92, C103, C104, C105, C106, C107, C119, C120, C121, C122, C123, C133, C134, C135, C136, C137, C147, C148, C149, C150, C151, C161, C162, C163, C164, C165, C166, C167, C168, C169, C170, C171, C172, C173, C174, C175, C176, C177, C178, C179, C180, C181, C182, C183, C184, C185, C186, C187, C188, C189, C190, C191, C192, C193, C194, C195, C196, C197, C198, C199, C200, C201, C202, C203, C204, C205, C206, C207, C208, C209, C210, C211, C212, C215, C216: 0,1uF; C_0402_1005Metric; PART NUMBER GRM155R61A104KA01D
C63, C64, C65, C66, C67, C68, C79, C80, C81, C82, C83, C84, C95, C96, C97, C98, C99, C100, C111, C112, C113, C114, C115, C126, C127, C128, C129, C130, C140, C141, C142, C143, C144, C154, C155, C156, C157, C158: 1uF; C_0402_1005Metric; PART NUMBER GRM155C81A105KA12D
FID1, FID2, FID3: Fiducial; Fiducial_0.5mm_Mask1.5mm
H1, H2, H3, H4, H5, H6, H7, H8, H9, H10, H11, H12, H13, H14: MH; MountingHole_2.2mm_M2
TP14, TP17, TP18, TP19, TP20, TP21, TP22, TP23, TP25, TP26, TP27, TP28: TestPoint; KEYSTONE_5005; PART NUMBER 5005

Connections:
+5V: C55.1, C56.1, C57.1, C58.1, C59.1, C60.1, C63.1, C64.1, C65.1, C66.1, C67.1, C68.1, C71.1, C72.1, C73.1, C74.1, C75.1, C76.1, C79.1, C80.1, C81.1, C82.1, C83.1, C84.1, C87.1, C88.1, C89.1, C90.1, C91.1, C92.1, C95.1, C96.1, C97.1, C98.1, C99.1, C100.1, C103.1, C104.1, C105.1, C106.1, C107.1, C111.1, C112.1, C113.1, C114.1, C115.1, C119.1, C120.1, C121.1, C122.1, C123.1, C126.1, C127.1, C128.1, C129.1, C130.1, C133.1, C134.1, C135.1, C136.1, C137.1, C140.1, C141.1, C142.1, C143.1, C144.1, C147.1, C148.1, C149.1, C150.1, C151.1, C154.1, C155.1, C156.1, C157.1, C158.1; also elsewhere on the board
+5VA: C161.1, C162.1, C163.1, C164.1, C165.1, C166.1, C167.1, C168.1, C169.1, C170.1, C171.1, C172.1, C175.1, C176.1, C177.1, C178.1, C181.1, C182.1, C183.1, C187.1, C188.1, C189.1, C193.1, C194.1, C195.1, C199.1, C200.1, C201.1, C205.1, C206.1, C207.1, C209.1, C210.1, C211.1; also elsewhere on the board
-5VA: C173.1, C174.1, C179.1, C180.1, C184.1, C185.1, C186.1, C190.1, C191.1, C192.1, C196.1, C197.1, C198.1, C202.1, C203.1, C204.1, C208.1, C212.1, C215.1, C216.1; also elsewhere on the board
GND: C55.2, C56.2, C57.2, C58.2, C59.2, C60.2, C63.2, C64.2, C65.2, C66.2, C67.2, C68.2, C71.2, C72.2, C73.2, C74.2, C75.2, C76.2, C79.2, C80.2, C81.2, C82.2, C83.2, C84.2, C87.2, C88.2, C89.2, C90.2, C91.2, C92.2, C95.2, C96.2, C97.2, C98.2, C99.2, C100.2, C103.2, C104.2, C105.2, C106.2, C107.2, C111.2, C112.2, C113.2, C114.2, C115.2, C119.2, C120.2, C121.2, C122.2, C123.2, C126.2, C127.2, C128.2, C129.2, C130.2, C133.2, C134.2, C135.2, C136.2, C137.2, C140.2, C141.2, C142.2, C143.2, C144.2, C147.2, C148.2, C149.2, C150.2, C151.2, C154.2, C155.2, C156.2, C157.2, C158.2, C161.2, C162.2, C163.2, C164.2, C165.2, C166.2, C167.2, C168.2, C169.2, C170.2, C171.2, C172.2, C173.2, C174.2, C175.2, C176.2, C177.2, C178.2, C179.2, C180.2, C181.2, C182.2, C183.2, C184.2, C185.2, C186.2, C187.2, C188.2, C189.2, C190.2, C191.2, C192.2, C193.2, C194.2, C195.2, C196.2, C197.2, C198.2, C199.2, C200.2, C201.2, C202.2, C203.2, C204.2, C205.2, C206.2, C207.2, C208.2, C209.2, C210.2, C211.2, C212.2, C215.2, C216.2, TP14.TP, TP17.TP, TP18.TP, TP19.TP, TP20.TP, TP21.TP, TP22.TP, TP23.TP, TP25.TP, TP26.TP, TP27.TP, TP28.TP; also elsewhere on the board

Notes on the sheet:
1x0,1uF par Comparateur et Ampli
0,1uF + 1uF pour chaque composante numérique
1x0,1uF par Ampli avec dual supply

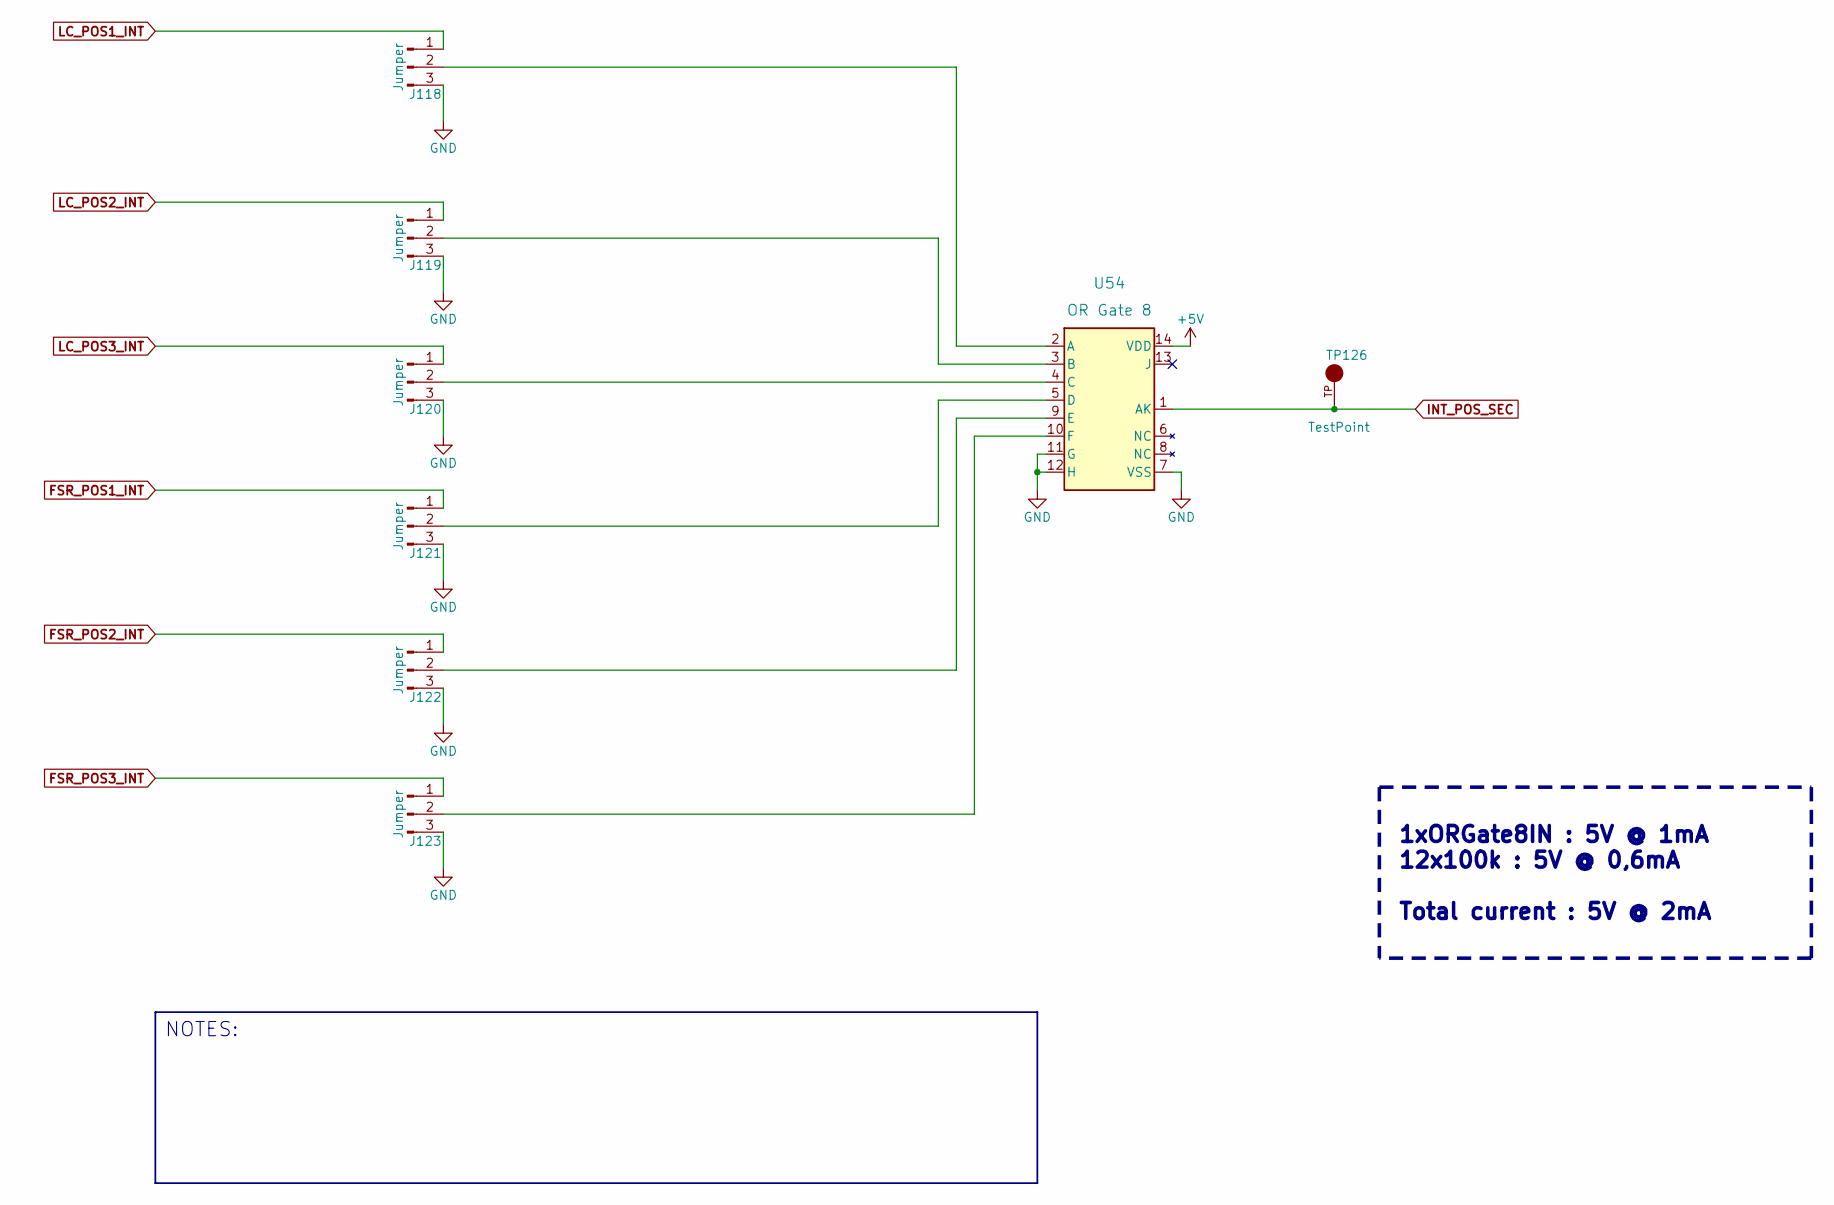
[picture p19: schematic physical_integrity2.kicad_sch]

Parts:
J118, J119, J120, J121, J122, J123: Jumper; PinHeader_1x03_P2.54mm_Vertical; PART NUMBER 61300311121
TP126: TestPoint; KEYSTONE_5005; PART NUMBER 5005
U54: OR Gate 8; D14; PART NUMBER CD4078BM96

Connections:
+5V: U54.14 (VDD); also elsewhere on the board
FSR_POS1_INT: J121.1; also elsewhere on the board
FSR_POS2_INT: J122.1; also elsewhere on the board
FSR_POS3_INT: J123.1; also elsewhere on the board
GND: J118.3, J119.3, J120.3, J121.3, J122.3, J123.3, U54.7 (VSS), U54.11 (G), U54.12 (H); also elsewhere on the board
INT_POS_SEC: TP126.TP, U54.1 (AK); also elsewhere on the board
LC_POS1_INT: J118.1; also elsewhere on the board
LC_POS2_INT: J119.1; also elsewhere on the board
LC_POS3_INT: J120.1; also elsewhere on the board
unnamed: J118.2, U54.2 (A)
unnamed: J119.2, U54.3 (B)
unnamed: J120.2, U54.4 (C)
unnamed: J121.2, U54.5 (D)
unnamed: J122.2, U54.9 (E)
unnamed: J123.2, U54.10 (F)

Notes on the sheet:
1xORGate8IN : 5V @ 1mA 12x100k : 5V @ 0,6mA Total current : 5V @ 2mA
NOTES:

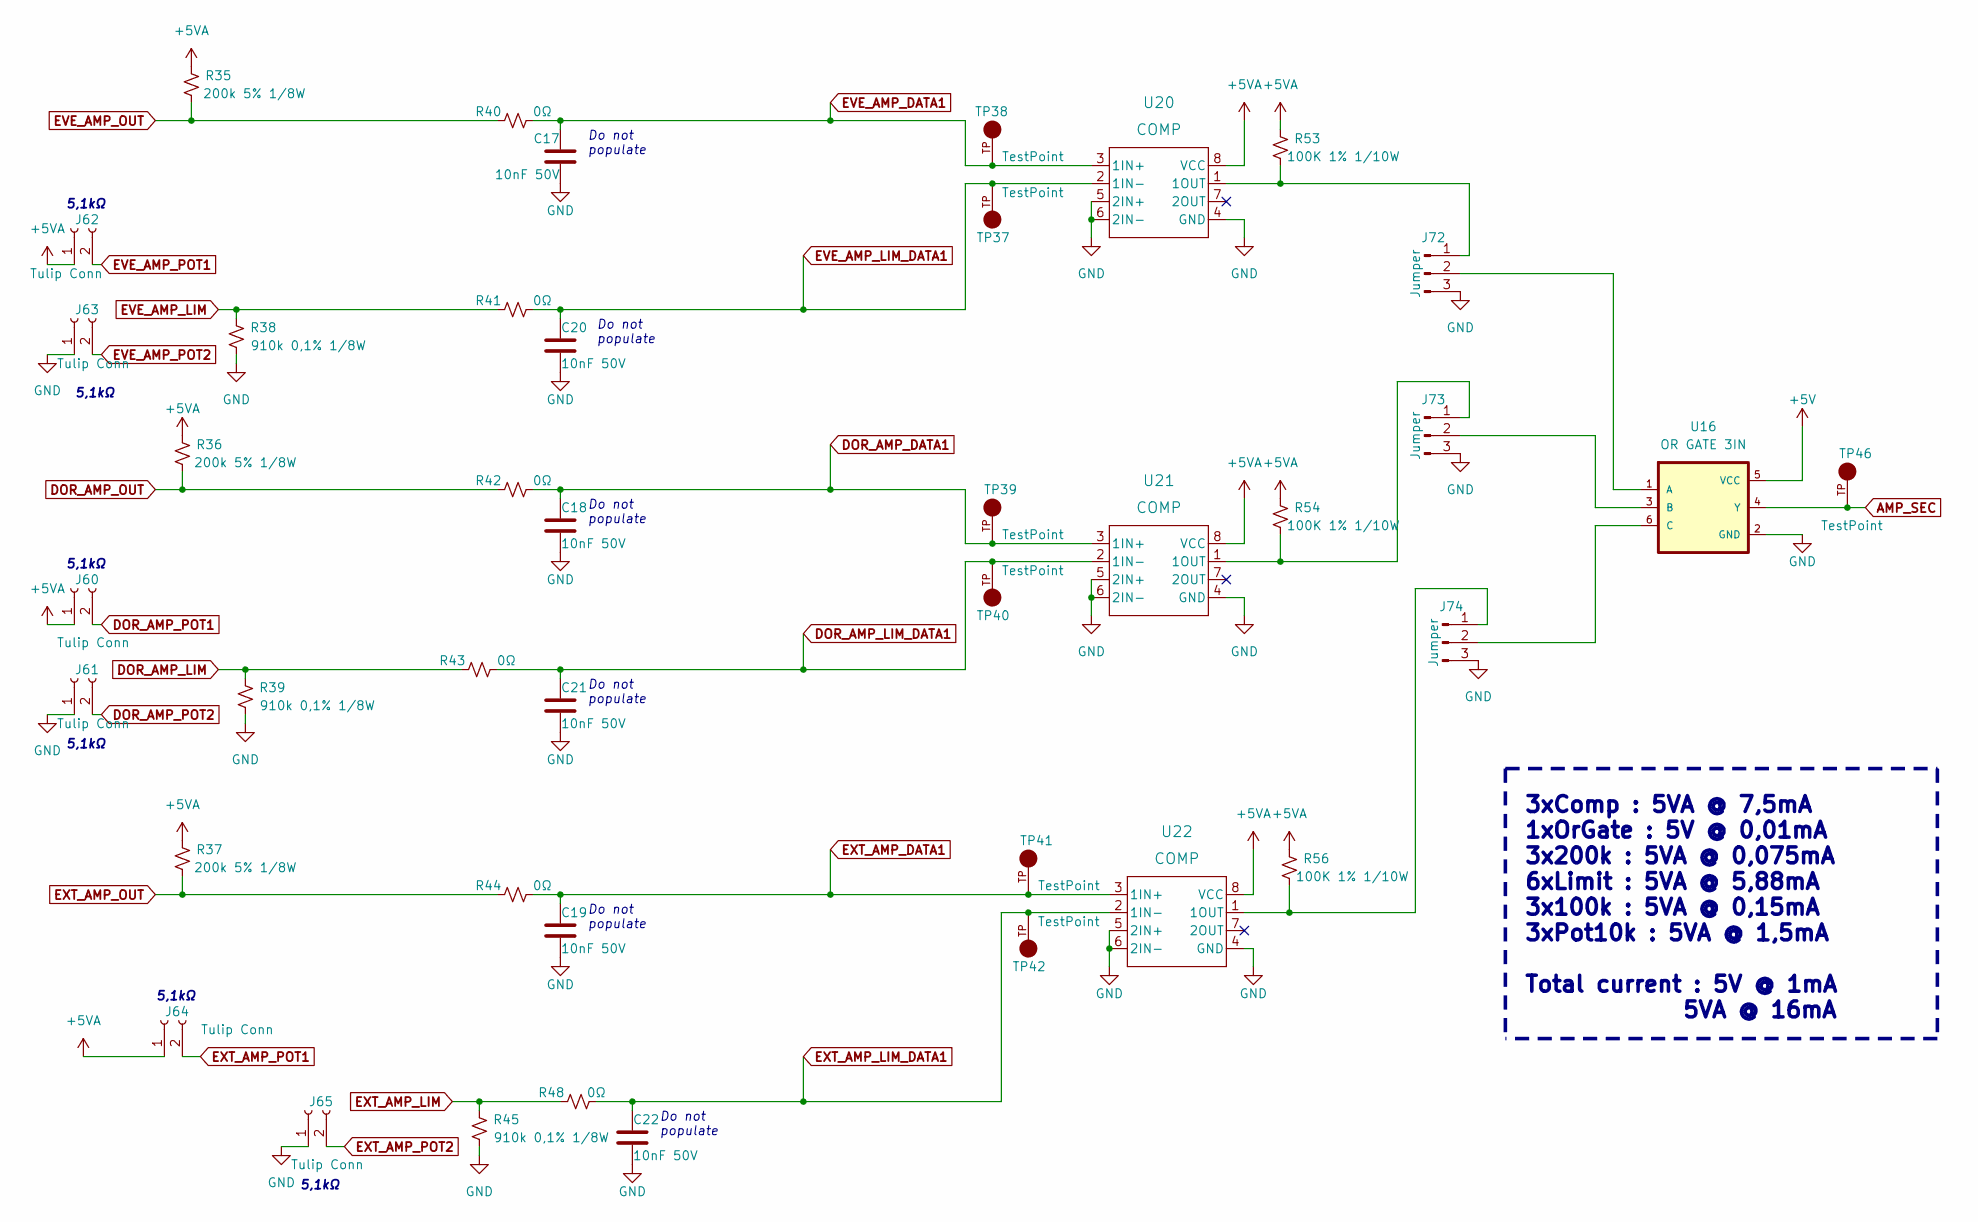
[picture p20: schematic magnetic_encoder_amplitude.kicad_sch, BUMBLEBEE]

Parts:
C17, C18, C19, C20, C21, C22: 10nF 50V; C_0805_2012Metric; PART NUMBER GRM2195C1H103JA01D
J60, J61, J62, J63, J64, J65: Tulip Conn; PinSocket_1x02_P2.54mm_Vertical; PART NUMBER 801-87-002-10-001101
J72, J73, J74: Jumper; PinHeader_1x03_P2.54mm_Vertical; PART NUMBER 61300311121
R35, R36, R37: 200k 5% 1/8W; R_0805_2012Metric; PART NUMBER ERJ-6GEYJ204V
R38, R39, R45: 910k 0,1% 1/8W; R_0805_2012Metric; PART NUMBER ERA-6AEB914V
R40, R41, R42, R43, R44, R48: 0Ω; R_0805_2012Metric; PART NUMBER ERJ-6GEY0R00V
R53, R54, R56: 100K 1% 1/10W; R_0603_1608Metric; PART NUMBER ERJ-3EKF1003V
TP37, TP38, TP39, TP40, TP41, TP42, TP46: TestPoint; KEYSTONE_5005; PART NUMBER 5005
U16: OR GATE 3IN; SOT95P280X145-6N; PART NUMBER SN74LVC1G332DBVR
U20, U21, U22: COMP; DGK8; PART NUMBER LM393DGKR

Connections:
+5V: U16.5 (VCC); also elsewhere on the board
+5VA: J60.1, J62.1, J64.1, R35.1, R36.1, R37.1, R53.1, R54.1, R56.1, U20.8 (VCC), U21.8 (VCC), U22.8 (VCC); also elsewhere on the board
AMP_SEC: TP46.TP, U16.4 (Y); also elsewhere on the board
DOR_AMP_DATA1: C18.1, R42.2, TP39.TP, U21.3 (1IN+); also elsewhere on the board
DOR_AMP_LIM: R39.1, R43.1; also elsewhere on the board
DOR_AMP_LIM_DATA1: C21.1, R43.2, TP40.TP, U21.2 (1IN-); also elsewhere on the board
DOR_AMP_OUT: R36.2, R42.1; also elsewhere on the board
DOR_AMP_POT1: J60.2; also elsewhere on the board
DOR_AMP_POT2: J61.2; also elsewhere on the board
EVE_AMP_DATA1: C17.1, R40.2, TP38.TP, U20.3 (1IN+); also elsewhere on the board
EVE_AMP_LIM: R38.1, R41.1; also elsewhere on the board
EVE_AMP_LIM_DATA1: C20.1, R41.2, TP37.TP, U20.2 (1IN-); also elsewhere on the board
EVE_AMP_OUT: R35.2, R40.1; also elsewhere on the board
EVE_AMP_POT1: J62.2; also elsewhere on the board
EVE_AMP_POT2: J63.2; also elsewhere on the board
EXT_AMP_DATA1: C19.1, R44.2, TP41.TP, U22.3 (1IN+); also elsewhere on the board
EXT_AMP_LIM: R45.1, R48.1; also elsewhere on the board
EXT_AMP_LIM_DATA1: C22.1, R48.2, TP42.TP, U22.2 (1IN-); also elsewhere on the board
EXT_AMP_OUT: R37.2, R44.1; also elsewhere on the board
EXT_AMP_POT1: J64.2; also elsewhere on the board
EXT_AMP_POT2: J65.2; also elsewhere on the board
GND: C17.2, C18.2, C19.2, C20.2, C21.2, C22.2, J61.1, J63.1, J65.1, J72.3, J73.3, J74.3, R38.2, R39.2, R45.2, U16.2 (GND), U20.4 (GND), U20.5 (2IN+), U20.6 (2IN-), U21.4 (GND), U21.5 (2IN+), U21.6 (2IN-), U22.4 (GND), U22.5 (2IN+), U22.6 (2IN-); also elsewhere on the board
unnamed: J72.1, R53.2, U20.1 (1OUT)
unnamed: J72.2, U16.1 (A)
unnamed: J73.1, R54.2, U21.1 (1OUT)
unnamed: J73.2, U16.3 (B)
unnamed: J74.1, R56.2, U22.1 (1OUT)
unnamed: J74.2, U16.6 (C)

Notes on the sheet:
Do not populate
5,1kΩ
3xComp : 5VA @ 7,5mA 1xOrGate : 5V @ 0,01mA 3x200k : 5VA @ 0,075mA 6xLimit : 5VA @ 5,88mA 3x100k : 5VA @ 0,15mA 3xPot10k : 5VA @ 1,5mA Total current : 5V @ 1mA 5VA @ 16mA

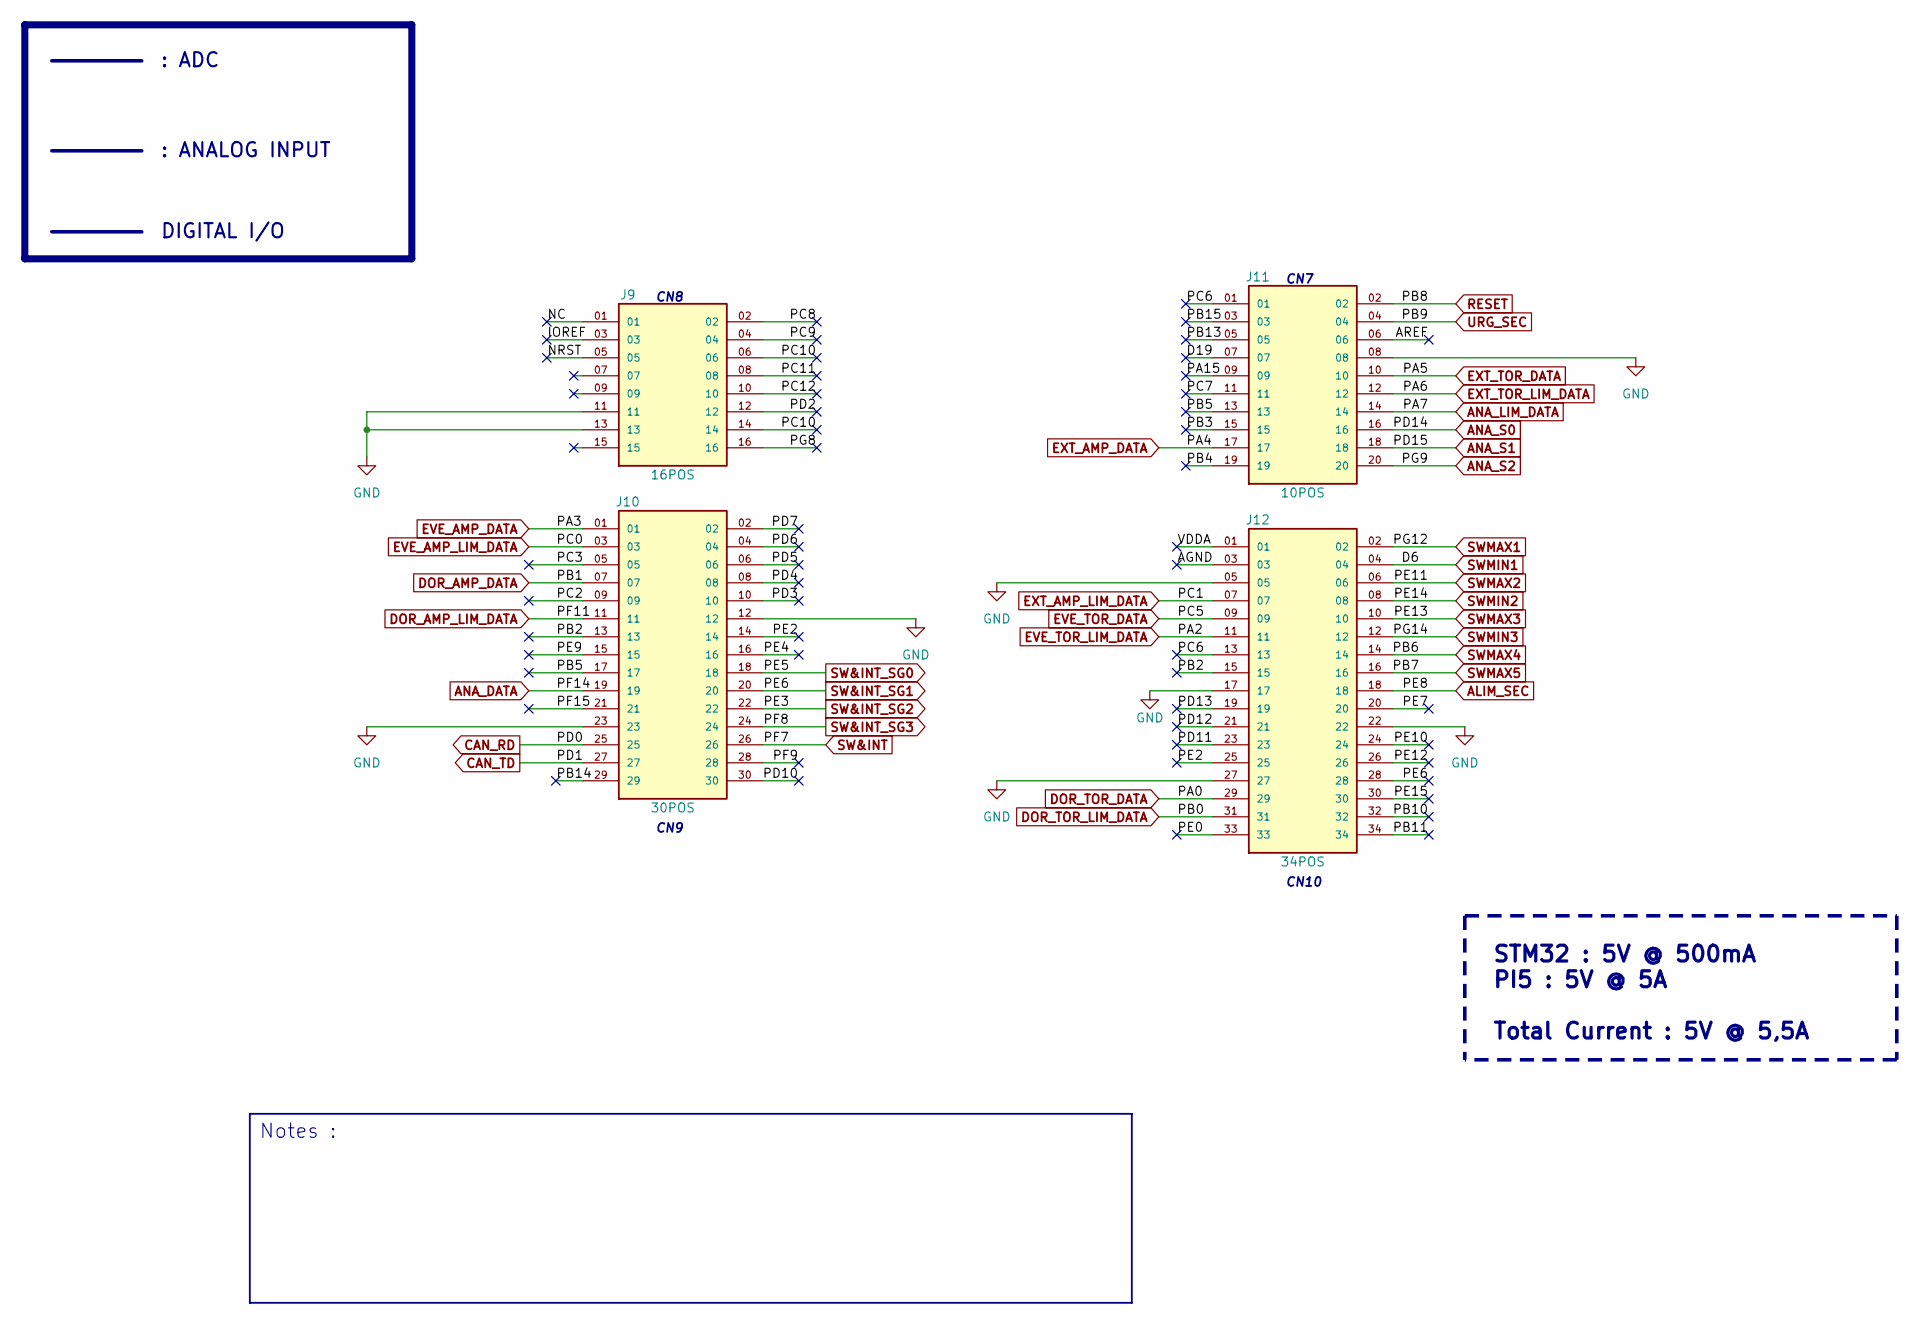
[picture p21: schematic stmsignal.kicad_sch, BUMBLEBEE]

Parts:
J9: 16POS; SAMTEC_SSW-108-01-G-D; PARTREV R
J10: 30POS; SAMTEC_SSW-115-01-G-D; PARTREV R
J11: 10POS; SAMTEC_SSW-110-01-G-D; PARTREV R
J12: 34POS; SAMTEC_SSW-117-01-G-D; PARTREV R

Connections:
/STM SIGNALS/AGND: J12.03
/STM SIGNALS/AREF: J11.06
/STM SIGNALS/D19: J11.07
/STM SIGNALS/IOREF: J9.03
/STM SIGNALS/NC: J9.01
/STM SIGNALS/NRST: J9.05
/STM SIGNALS/PA15: J11.09
/STM SIGNALS/PB2: J10.13, J12.15
/STM SIGNALS/PB3: J11.15
/STM SIGNALS/PB4: J11.19
/STM SIGNALS/PB5: J10.17, J11.13
/STM SIGNALS/PB10: J12.32
/STM SIGNALS/PB11: J12.34
/STM SIGNALS/PB13: J11.05
/STM SIGNALS/PB14: J10.29
/STM SIGNALS/PB15: J11.03
/STM SIGNALS/PC2: J10.09
/STM SIGNALS/PC3: J10.05
/STM SIGNALS/PC6: J11.01, J12.13
/STM SIGNALS/PC7: J11.11
/STM SIGNALS/PC8: J9.02
/STM SIGNALS/PC9: J9.04
/STM SIGNALS/PC10: J9.06, J9.14
/STM SIGNALS/PC11: J9.08
/STM SIGNALS/PC12: J9.10
/STM SIGNALS/PD2: J9.12
/STM SIGNALS/PD3: J10.10
/STM SIGNALS/PD4: J10.08
/STM SIGNALS/PD5: J10.06
/STM SIGNALS/PD6: J10.04
/STM SIGNALS/PD7: J10.02
/STM SIGNALS/PD10: J10.30
/STM SIGNALS/PD11: J12.23
/STM SIGNALS/PD12: J12.21
/STM SIGNALS/PD13: J12.19
/STM SIGNALS/PE0: J12.33
/STM SIGNALS/PE2: J10.14, J12.25
/STM SIGNALS/PE4: J10.16
/STM SIGNALS/PE7: J12.20
/STM SIGNALS/PE9: J10.15
/STM SIGNALS/PE10: J12.24
/STM SIGNALS/PE12: J12.26
/STM SIGNALS/PE15: J12.30
/STM SIGNALS/PF9: J10.28
/STM SIGNALS/PF15: J10.21
/STM SIGNALS/PG8: J9.16
/STM SIGNALS/VDDA: J12.01
ALIM_SEC: J12.18; also elsewhere on the board
ANA_DATA: J10.19; also elsewhere on the board
ANA_LIM_DATA: J11.14; also elsewhere on the board
ANA_S0: J11.16; also elsewhere on the board
ANA_S1: J11.18; also elsewhere on the board
ANA_S2: J11.20; also elsewhere on the board
CAN_RD: J10.25; also elsewhere on the board
CAN_TD: J10.27; also elsewhere on the board
DOR_AMP_DATA: J10.07; also elsewhere on the board
DOR_AMP_LIM_DATA: J10.11; also elsewhere on the board
DOR_TOR_DATA: J12.29; also elsewhere on the board
DOR_TOR_LIM_DATA: J12.31; also elsewhere on the board
EVE_AMP_DATA: J10.01; also elsewhere on the board
EVE_AMP_LIM_DATA: J10.03; also elsewhere on the board
EVE_TOR_DATA: J12.09; also elsewhere on the board
EVE_TOR_LIM_DATA: J12.11; also elsewhere on the board
EXT_AMP_DATA: J11.17; also elsewhere on the board
EXT_AMP_LIM_DATA: J12.07; also elsewhere on the board
EXT_TOR_DATA: J11.10; also elsewhere on the board
EXT_TOR_LIM_DATA: J11.12; also elsewhere on the board
GND: J9.11, J9.13, J10.12, J10.23, J11.08, J12.05, J12.17, J12.22, J12.27; also elsewhere on the board
RESET: J11.02; also elsewhere on the board
SW&INT: J10.26; also elsewhere on the board
SW&INT_SG0: J10.18; also elsewhere on the board
SW&INT_SG1: J10.20, J12.28; also elsewhere on the board
SW&INT_SG2: J10.22; also elsewhere on the board
SW&INT_SG3: J10.24; also elsewhere on the board
SWMAX1: J12.02; also elsewhere on the board
SWMAX2: J12.06; also elsewhere on the board
SWMAX3: J12.10; also elsewhere on the board
SWMAX4: J12.14; also elsewhere on the board
SWMAX5: J12.16; also elsewhere on the board
SWMIN1: J12.04; also elsewhere on the board
SWMIN2: J12.08; also elsewhere on the board
SWMIN3: J12.12; also elsewhere on the board
URG_SEC: J11.04; also elsewhere on the board

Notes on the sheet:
CN10
CN8
Notes :
STM32 : 5V @ 500mA PI5 : 5V @ 5A Total Current : 5V @ 5,5A
: ANALOG INPUT
CN9
DIGITAL I/O
CN7
: ADC

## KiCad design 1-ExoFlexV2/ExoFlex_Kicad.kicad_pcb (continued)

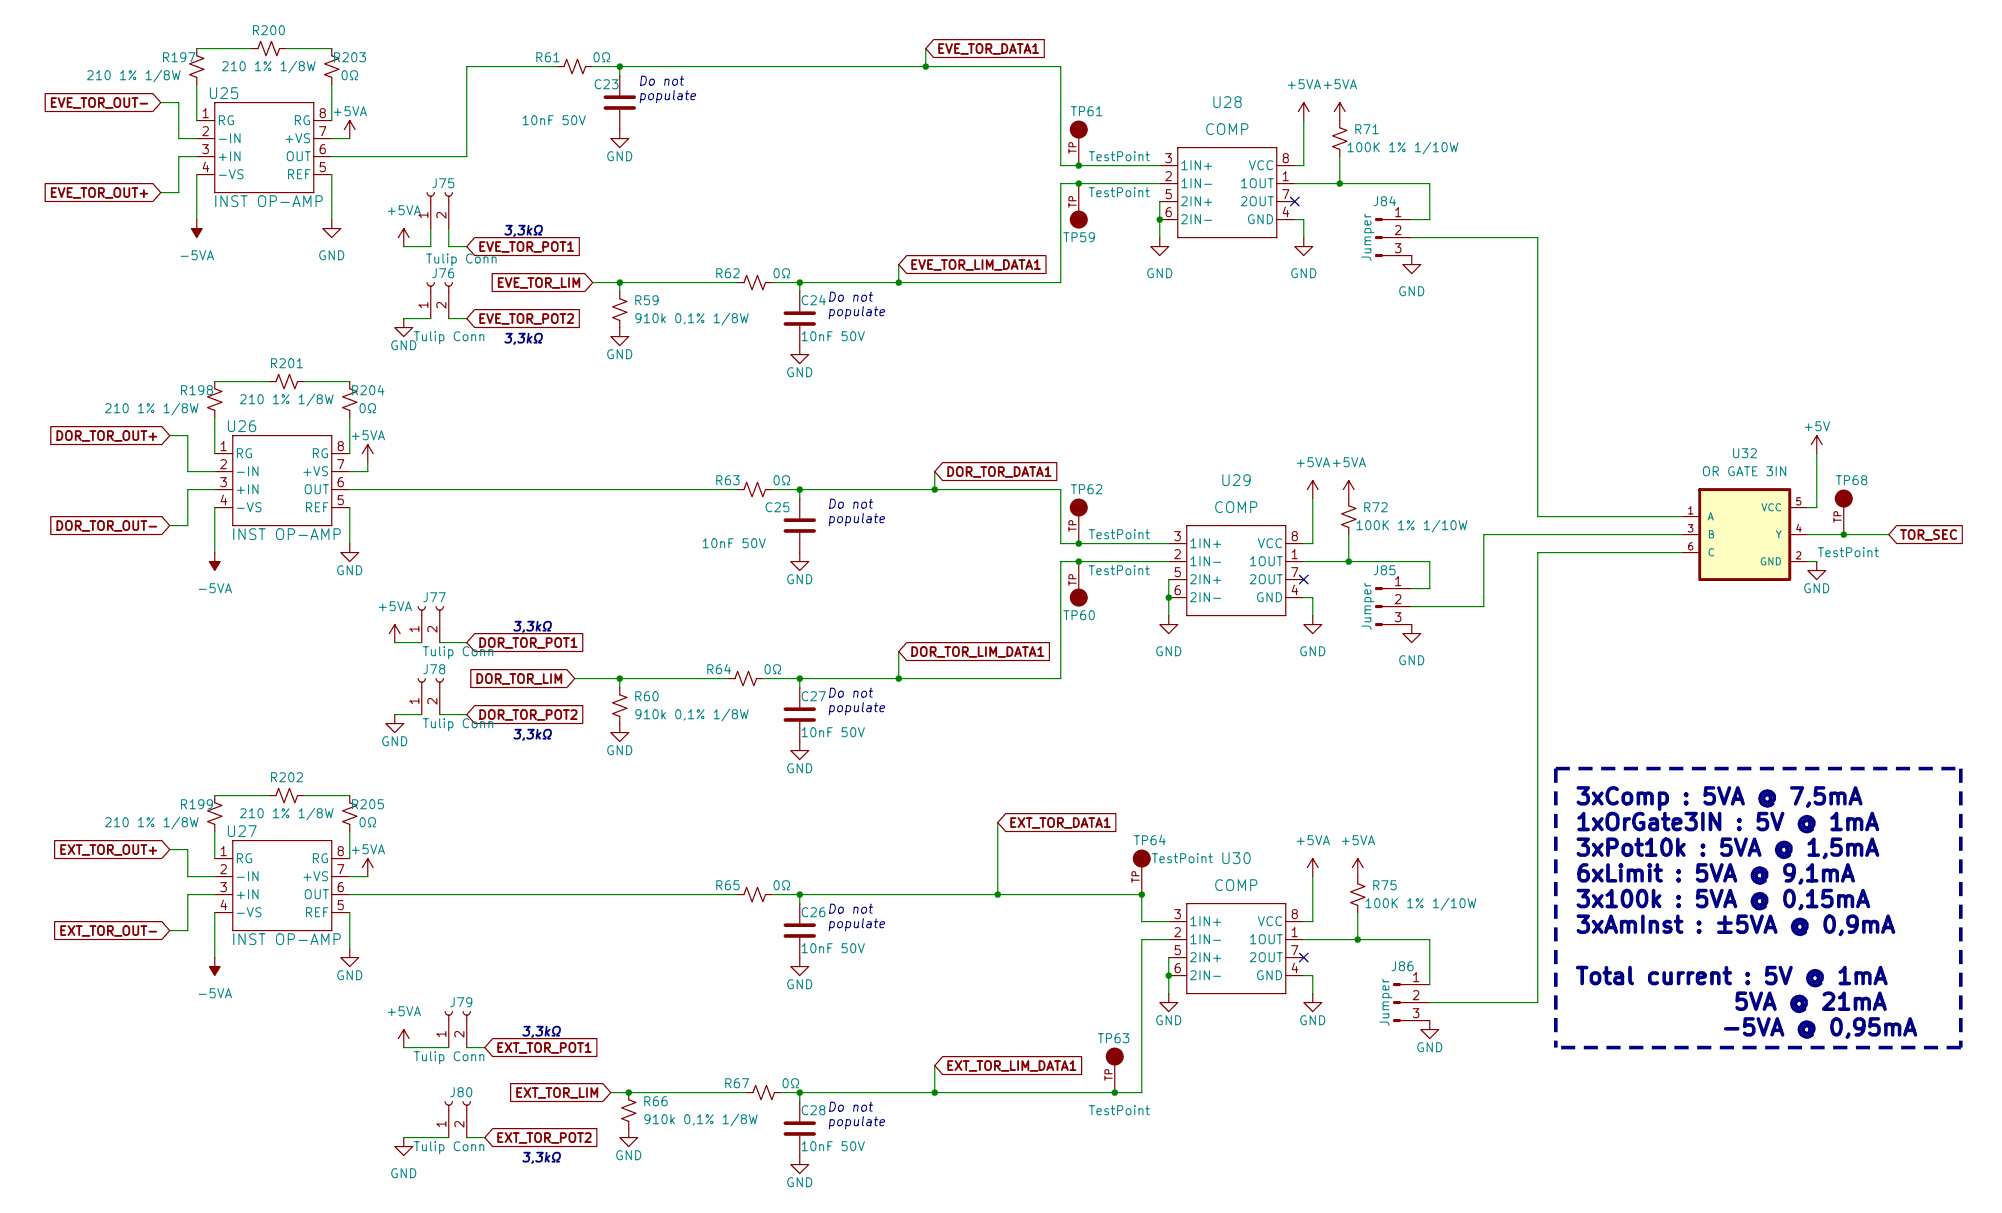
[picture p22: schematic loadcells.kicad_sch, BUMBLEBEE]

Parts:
C23, C24, C25, C26, C27, C28: 10nF 50V; C_0805_2012Metric; PART NUMBER GRM2195C1H103JA01D
J75, J76, J77, J78, J79, J80: Tulip Conn; PinSocket_1x02_P2.54mm_Vertical; PART NUMBER 801-87-002-10-001101
J84, J85, J86: Jumper; PinHeader_1x03_P2.54mm_Vertical; PART NUMBER 61300311121
R59, R60, R66: 910k 0,1% 1/8W; R_0805_2012Metric; PART NUMBER ERA-6AEB914V
R61, R62, R63, R64, R65, R67, R203, R204, R205: 0Ω; R_0805_2012Metric; PART NUMBER ERJ-6GEY0R00V
R71, R72, R75: 100K 1% 1/10W; R_0603_1608Metric; PART NUMBER ERJ-3EKF1003V
R197, R198, R199, R200, R201, R202: 210 1% 1/8W; R_0805_2012Metric; PART NUMBER ERJ-6ENF2100V
TP59, TP60, TP61, TP62, TP63, TP64, TP68: TestPoint; KEYSTONE_5005; PART NUMBER 5005
U25, U26, U27: INST OP-AMP; D0008A_SOIC_TEX; PART NUMBER INA823DR
U28, U29, U30: COMP; DGK8; PART NUMBER LM393DGKR
U32: OR GATE 3IN; SOT95P280X145-6N; PART NUMBER SN74LVC1G332DBVR

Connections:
+5V: U32.5 (VCC); also elsewhere on the board
+5VA: J75.1, J77.1, J79.1, R71.1, R72.1, R75.1, U25.7 (+VS), U26.7 (+VS), U27.7 (+VS), U28.8 (VCC), U29.8 (VCC), U30.8 (VCC); also elsewhere on the board
-5VA: U25.4 (-VS), U26.4 (-VS), U27.4 (-VS); also elsewhere on the board
DOR_TOR_DATA1: C25.1, R63.2, TP62.TP, U29.3 (1IN+); also elsewhere on the board
DOR_TOR_LIM: R60.1, R64.1; also elsewhere on the board
DOR_TOR_LIM_DATA1: C27.1, R64.2, TP60.TP, U29.2 (1IN-); also elsewhere on the board
DOR_TOR_OUT+: U26.2 (-IN); also elsewhere on the board
DOR_TOR_OUT-: U26.3 (+IN); also elsewhere on the board
DOR_TOR_POT1: J77.2; also elsewhere on the board
DOR_TOR_POT2: J78.2; also elsewhere on the board
EVE_TOR_DATA1: C23.1, R61.2, TP61.TP, U28.3 (1IN+); also elsewhere on the board
EVE_TOR_LIM: R59.1, R62.1; also elsewhere on the board
EVE_TOR_LIM_DATA1: C24.1, R62.2, TP59.TP, U28.2 (1IN-); also elsewhere on the board
EVE_TOR_OUT+: U25.3 (+IN); also elsewhere on the board
EVE_TOR_OUT-: U25.2 (-IN); also elsewhere on the board
EVE_TOR_POT1: J75.2; also elsewhere on the board
EVE_TOR_POT2: J76.2; also elsewhere on the board
EXT_TOR_DATA1: C26.1, R65.2, TP64.TP, U30.3 (1IN+); also elsewhere on the board
EXT_TOR_LIM: R66.1, R67.1; also elsewhere on the board
EXT_TOR_LIM_DATA1: C28.1, R67.2, TP63.TP, U30.2 (1IN-); also elsewhere on the board
EXT_TOR_OUT+: U27.2 (-IN); also elsewhere on the board
EXT_TOR_OUT-: U27.3 (+IN); also elsewhere on the board
EXT_TOR_POT1: J79.2; also elsewhere on the board
EXT_TOR_POT2: J80.2; also elsewhere on the board
GND: C23.2, C24.2, C25.2, C26.2, C27.2, C28.2, J76.1, J78.1, J80.1, J84.3, J85.3, J86.3, R59.2, R60.2, R66.2, U25.5 (REF), U26.5 (REF), U27.5 (REF), U28.4 (GND), U28.5 (2IN+), U28.6 (2IN-), U29.4 (GND), U29.5 (2IN+), U29.6 (2IN-), U30.4 (GND), U30.5 (2IN+), U30.6 (2IN-), U32.2 (GND); also elsewhere on the board
unnamed: J84.1, R71.2, U28.1 (1OUT)
unnamed: J84.2, U32.1 (A)
unnamed: J85.1, R72.2, U29.1 (1OUT)
unnamed: J85.2, U32.3 (B)
unnamed: J86.1, R75.2, U30.1 (1OUT)
unnamed: J86.2, U32.6 (C)
unnamed: R61.1, U25.6 (OUT)
unnamed: R63.1, U26.6 (OUT)
unnamed: R65.1, U27.6 (OUT)
unnamed: R197.1, U25.1 (RG)
unnamed: R197.2, R200.1
unnamed: R198.1, U26.1 (RG)
unnamed: R198.2, R201.1
unnamed: R199.1, U27.1 (RG)
unnamed: R199.2, R202.1
unnamed: R200.2, R203.1
unnamed: R201.2, R204.1
unnamed: R202.2, R205.1
unnamed: R203.2, U25.8 (RG)
unnamed: R204.2, U26.8 (RG)
unnamed: R205.2, U27.8 (RG)
TOR_SEC: TP68.TP, U32.4 (Y); also elsewhere on the board

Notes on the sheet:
3,3kΩ
Do not populate
3xComp : 5VA @ 7,5mA 1xOrGate3IN : 5V @ 1mA 3xPot10k : 5VA @ 1,5mA 6xLimit : 5VA @ 9,1mA 3x100k : 5VA @ 0,15mA 3xAmInst : ±5VA @ 0,9mA Total current : 5V @ 1mA 5VA @ 21mA -5VA @ 0,95mA

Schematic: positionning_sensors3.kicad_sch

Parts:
C50, C51, C52: 10nF 50V; C_0805_2012Metric; PART NUMBER GRM2195C1H103JA01D
J107, J108, J109: Jumper; PinHeader_1x03_P2.54mm_Vertical; PART NUMBER 61300311121
R155, R156, R157: 0Ω; R_0805_2012Metric; PART NUMBER ERJ-6GEY0R00V
R158, R159, R160, R161, R162, R163: 100K 1% 1/10W; R_0603_1608Metric; PART NUMBER ERJ-3EKF1003V
RV3, RV4, RV5: Trim 10k; TRIM_3362P-1-103LF; PART NUMBER 3362P-1-103LF
TP108, TP109, TP110, TP111, TP112, TP113, TP117: TestPoint; KEYSTONE_5005; PART NUMBER 5005
U58: Inverter; SN74LVC3G14DCUT; PART NUMBER SN74LVC3G14DCUT
U79, U80, U81: COMP; DGK8; PART NUMBER LM393DGKR
U82, U83: AND Gate; SOT95P270X145-5N; PART NUMBER SN74LVC1G08DBVR

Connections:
+5V: U58.8 (VCC), U82.5 (VCC), U83.5 (VCC); also elsewhere on the board
+5VA: R158.1, R159.1, R160.1, R161.2, R162.2, R163.2, RV3.2, RV4.3, RV5.3, U79.8 (VCC), U80.8 (VCC), U81.8 (VCC); also elsewhere on the board
FSR_POS1: R155.1; also elsewhere on the board
FSR_POS2: R156.1; also elsewhere on the board
FSR_POS3: R157.1; also elsewhere on the board
GND: C50.2, C51.2, C52.2, RV4.1, RV5.1, U58.3 (2A), U58.4 (GND), U58.6 (3A), U79.4 (GND), U79.5 (2IN+), U79.6 (2IN-), U80.4 (GND), U80.5 (2IN+), U80.6 (2IN-), U81.4 (GND), U81.5 (2IN+), U81.6 (2IN-), U82.3 (GND), U83.3 (GND); also elsewhere on the board
M_FSR_POS1: C50.1, R155.2, TP108.TP, U79.3 (1IN+); also elsewhere on the board
M_FSR_POS2: C51.1, R156.2, TP110.TP, U80.3 (1IN+); also elsewhere on the board
M_FSR_POS3: C52.1, R157.2, TP112.TP, U81.3 (1IN+); also elsewhere on the board
M_FSR_POS_LIM1: RV3.1, TP109.TP, U79.2 (1IN-); also elsewhere on the board
M_FSR_POS_LIM2: RV4.2, TP111.TP, U80.2 (1IN-); also elsewhere on the board
M_FSR_POS_LIM3: RV5.2, TP113.TP, U81.2 (1IN-); also elsewhere on the board
unnamed: J107.1, R158.2, U80.1 (1OUT)
unnamed: J107.2, U82.2 (B)
unnamed: J107.3, R161.1
unnamed: J108.1, R159.2, U79.1 (1OUT)
unnamed: J108.2, U82.1 (A)
unnamed: J108.3, R162.1
unnamed: J109.1, R160.2, U81.1 (1OUT)
unnamed: J109.2, U83.2 (B)
unnamed: J109.3, R163.1
unnamed: U58.1 (1A), U83.4 (Y)
unnamed: U82.4 (Y), U83.1 (A)
POS_FSR_SEC: TP117.TP, U58.7 (1Y); also elsewhere on the board

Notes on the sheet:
3xComp : 5VA @ 7,5mA 2xANDGate : 5V @ 2mA 1xNOTGte : 5V @ 1mA 3xPot10k : 5VA @ 1,5mA 6x100k : 5VA @ 0,3mA Total current : 5V @ 3,15mA 5VA @ 10mA
Do not populate

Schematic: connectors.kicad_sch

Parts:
D3, D4, D7, D8, D11, D13, D14, D17, D19, D21, D22, D23, D24, D25, D26, D27, D28, D29, D30, D31, D32, D33, D34, D35, D36, D37, D38, D109, D110, D111: TVS; DPY2_TEX; PART NUMBER TPD1E05U06DPYR
J13, J14, J15, J19, J20, J21, J22, J23, J24: 3POS; CON_39301039; PARTREV 03.03.2021
J16, J17, J18: 39281083; MOLEX_0039281083; PART NUMBER 0039281083
R113, R170, R171: 100K 1% 1/10W; R_0603_1608Metric; PART NUMBER ERJ-3EKF1003V

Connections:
+5VA: J13.3, J14.3, J15.3, J16.2, J17.2, J18.2, R113.2, R170.2, R171.2; also elsewhere on the board
-5VA: J16.4, J17.4, J18.4; also elsewhere on the board
DOR_AMP_LIM: D25.1 (K), J20.2; also elsewhere on the board
DOR_AMP_OUT: D8.1 (K), J14.2; also elsewhere on the board
DOR_AMP_POT1: D26.1 (K), J20.3; also elsewhere on the board
DOR_AMP_POT2: D24.1 (K), J20.1; also elsewhere on the board
DOR_TOR_INT: D110.1 (K), J17.1, R170.1; also elsewhere on the board
DOR_TOR_LIM: D34.1 (K), J23.2; also elsewhere on the board
DOR_TOR_OUT+: D14.1 (K), J17.3; also elsewhere on the board
DOR_TOR_OUT-: D11.1 (K), J17.5; also elsewhere on the board
DOR_TOR_POT1: D35.1 (K), J23.3; also elsewhere on the board
DOR_TOR_POT2: D33.1 (K), J23.1; also elsewhere on the board
EVE_AMP_LIM: D28.1 (K), J19.2; also elsewhere on the board
EVE_AMP_OUT: D13.1 (K), J13.2; also elsewhere on the board
EVE_AMP_POT1: D29.1 (K), J19.3; also elsewhere on the board
EVE_AMP_POT2: D27.1 (K), J19.1; also elsewhere on the board
EVE_TOR_INT: D111.1 (K), J16.1, R171.1; also elsewhere on the board
EVE_TOR_LIM: D37.1 (K), J22.2; also elsewhere on the board
EVE_TOR_OUT+: D19.1 (K), J16.3; also elsewhere on the board
EVE_TOR_OUT-: D17.1 (K), J16.5; also elsewhere on the board
EVE_TOR_POT1: D38.1 (K), J22.3; also elsewhere on the board
EVE_TOR_POT2: D36.1 (K), J22.1; also elsewhere on the board
EXT_AMP_LIM: D22.1 (K), J21.2; also elsewhere on the board
EXT_AMP_OUT: D3.1 (K), J15.2; also elsewhere on the board
EXT_AMP_POT1: D23.1 (K), J21.3; also elsewhere on the board
EXT_AMP_POT2: D21.1 (K), J21.1; also elsewhere on the board
EXT_TOR_INT: D109.1 (K), J18.1, R113.1; also elsewhere on the board
EXT_TOR_LIM: D31.1 (K), J24.2; also elsewhere on the board
EXT_TOR_OUT+: D7.1 (K), J18.3; also elsewhere on the board
EXT_TOR_OUT-: D4.1 (K), J18.5; also elsewhere on the board
EXT_TOR_POT1: D32.1 (K), J24.3; also elsewhere on the board
EXT_TOR_POT2: D30.1 (K), J24.1; also elsewhere on the board
GND: D3.2 (A), D4.2 (A), D7.2 (A), D8.2 (A), D11.2 (A), D13.2 (A), D14.2 (A), D17.2 (A), D19.2 (A), D21.2 (A), D22.2 (A), D23.2 (A), D24.2 (A), D25.2 (A), D26.2 (A), D27.2 (A), D28.2 (A), D29.2 (A), D30.2 (A), D31.2 (A), D32.2 (A), D33.2 (A), D34.2 (A), D35.2 (A), D36.2 (A), D37.2 (A), D38.2 (A), D109.2 (A), D110.2 (A), D111.2 (A), J13.1, J14.1, J15.1, J16.6, J16.7, J17.6, J17.7, J18.6, J18.7; also elsewhere on the board

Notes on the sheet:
3xMagEncoder : 5VA @ 19,5mA 3xTorSensor : ±5VA @ 42,85mA Total current : 5VA @ 65,47mA -5VA @ 45mA
Limite Torque Éversion
TORQUE
AMPLITUDE
- | | | | | | | | | | | | |Provient du ATO-STS-NJY65 | | | | | | | | | | | | -
Éversion
Extension
- | | | | | | |Provient du AS5600 | | | | | | -
Limite Amplitude Dorsiflexion
Limite Torque Dorsiflexion
Limite Amplitude Éversion
Dorsiflexion
Limite Amplitude Extension
Limite Torque Extension

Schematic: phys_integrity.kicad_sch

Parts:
J115, J116, J117: Jumper; PinHeader_1x03_P2.54mm_Vertical; PART NUMBER 61300311121
R173, R174, R175: 100K 1% 1/10W; R_0603_1608Metric; PART NUMBER ERJ-3EKF1003V
TP125: TestPoint; KEYSTONE_5005; PART NUMBER 5005
U53: OR GATE 3IN; SOT95P280X145-6N; PART NUMBER SN74LVC1G332DBVR

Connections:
+5V: R173.1, R174.1, R175.1, U53.5 (VCC); also elsewhere on the board
DOR_TOR_INT: J116.1, R174.2; also elsewhere on the board
EVE_TOR_INT: J117.1, R175.2; also elsewhere on the board
EXT_TOR_INT: J115.1, R173.2; also elsewhere on the board
GND: J115.3, J116.3, J117.3, U53.2 (GND); also elsewhere on the board
INT_SENSOR_SEC: TP125.TP, U53.4 (Y); also elsewhere on the board
unnamed: J115.2, U53.1 (A)
unnamed: J116.2, U53.3 (B)
unnamed: J117.2, U53.6 (C)

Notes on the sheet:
1xORGate3IN : 5V @ 0,01mA 12x100k : 5V @ 0,6mA Total current : 5V @ 1mA
NOTES:

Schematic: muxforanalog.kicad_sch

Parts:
J131, J132: Jumper; PinHeader_1x03_P2.54mm_Vertical; PART NUMBER 61300311121
R265, R266, R273, R274, R275, R276: 10K 1% 1/10W; R_0603_1608Metric; PART NUMBER ERJ-3EKF1002V
R267, R268, R269, R270: 3.3k 1% 1/8W; R_0805_2012Metric; PART NUMBER ERJ-6ENF3301V
R271, R272: 0Ω; R_0805_2012Metric; PART NUMBER ERJ-6GEY0R00V
R277, R278: 100k 1% 1/20W; R_0201_0603Metric; PART NUMBER ERJ-1GNF1003C
U56, U57: OP_AMP2; SOIC127P599X175-8N; PART NUMBER TL072IDR
U121, U122: MUX 8:1; SOT403-1_NXP; PART NUMBER 74HC4051PW,118

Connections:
+5V: U121.16 (VCC), U122.16 (VCC); also elsewhere on the board
+5VA: U56.8 (VCC+), U57.8 (VCC+); also elsewhere on the board
-5VA: U56.4 (VCC-), U57.4 (VCC-); also elsewhere on the board
ANA_DATA: J131.2; also elsewhere on the board
ANA_LIM_DATA: J132.2; also elsewhere on the board
ANA_S0: U121.11 (S0), U122.11 (S0); also elsewhere on the board
ANA_S1: U121.10 (S1), U122.10 (S1); also elsewhere on the board
ANA_S2: U121.9 (S2), U122.9 (S2); also elsewhere on the board
GND: R277.2, R278.2, U56.3 (1IN+), U56.5 (2IN+), U57.3 (1IN+), U57.5 (2IN+), U121.6 (E*), U121.7 (VEE), U121.8 (GND), U122.6 (E*), U122.7 (VEE), U122.8 (GND); also elsewhere on the board
M_FSR_POS1: U121.12 (Y3); also elsewhere on the board
M_FSR_POS2: U121.1 (Y4); also elsewhere on the board
M_FSR_POS3: U121.5 (Y5); also elsewhere on the board
M_FSR_POS_LIM1: U122.12 (Y3); also elsewhere on the board
M_FSR_POS_LIM2: U122.1 (Y4); also elsewhere on the board
M_FSR_POS_LIM3: U122.5 (Y5); also elsewhere on the board
M_LC_POS1: U121.13 (Y0); also elsewhere on the board
M_LC_POS2: U121.14 (Y1); also elsewhere on the board
M_LC_POS3: U121.15 (Y2); also elsewhere on the board
M_LC_POS_LIM1: U122.13 (Y0); also elsewhere on the board
M_LC_POS_LIM2: U122.14 (Y1); also elsewhere on the board
M_LC_POS_LIM3: U122.15 (Y2); also elsewhere on the board
M_TEMP_1: U121.2 (Y6); also elsewhere on the board
M_TEMP_2: U121.4 (Y7); also elsewhere on the board
M_TEMP_LIM1: U122.2 (Y6); also elsewhere on the board
M_TEMP_LIM2: U122.4 (Y7); also elsewhere on the board
unnamed: J131.1, R274.1, U56.7 (2OUT)
unnamed: J131.3, R277.1
unnamed: J132.1, R276.1, U57.7 (2OUT)
unnamed: J132.3, R278.1
unnamed: R265.1, U121.3 (Z)
unnamed: R265.2, R267.1, U56.2 (1IN-)
unnamed: R266.1, U122.3 (Z)
unnamed: R266.2, R268.1, U57.2 (1IN-)
unnamed: R267.2, R269.1
unnamed: R268.2, R270.1
unnamed: R269.2, R271.1
unnamed: R270.2, R272.1
unnamed: R271.2, R273.2, U56.1 (1OUT)
unnamed: R272.2, R275.2, U57.1 (1OUT)
unnamed: R273.1, R274.2, U56.6 (2IN-)
unnamed: R275.1, R276.2, U57.6 (2IN-)

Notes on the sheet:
2xMUX8_1 : 5V @ 100mA 2xOP : 5VA @ 5mA Total current : 5V @ 110mA

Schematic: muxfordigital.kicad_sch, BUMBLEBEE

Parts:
TP128: TestPoint; KEYSTONE_5005; PART NUMBER 5005
U12, U13: MUX 8:1; SOT403-1_NXP; PART NUMBER 74HC4051PW,118
U59: Inverter; SN74LVC3G14DCUT; PART NUMBER SN74LVC3G14DCUT

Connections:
+5V: U12.16 (VCC), U13.16 (VCC), U59.8 (VCC); also elsewhere on the board
GND: U12.7 (VEE), U12.8 (GND), U13.1 (Y4), U13.2 (Y6), U13.4 (Y7), U13.5 (Y5), U13.7 (VEE), U13.8 (GND), U59.3 (2A), U59.4 (GND), U59.6 (3A); also elsewhere on the board
INT_POS_SEC: U13.15 (Y2); also elsewhere on the board
INT_PROX_SEC: U13.12 (Y3); also elsewhere on the board
INT_SENSOR_SEC: U13.14 (Y1); also elsewhere on the board
M_BUT_POS1: U12.2 (Y6); also elsewhere on the board
M_BUT_POS2: U12.4 (Y7); also elsewhere on the board
M_BUT_POS3: U13.13 (Y0); also elsewhere on the board
M_BUT_PROX_L1: U12.13 (Y0); also elsewhere on the board
M_BUT_PROX_L2: U12.14 (Y1); also elsewhere on the board
M_BUT_PROX_R1: U12.15 (Y2); also elsewhere on the board
M_BUT_PROX_R2: U12.12 (Y3); also elsewhere on the board
M_REC_PROX1: U12.1 (Y4); also elsewhere on the board
M_REC_PROX2: U12.5 (Y5); also elsewhere on the board
unnamed: U13.6 (E*), U59.7 (1Y)
SW&INT: TP128.TP, U12.3 (Z), U13.3 (Z); also elsewhere on the board
SW&INT_SG0: U12.11 (S0), U13.11 (S0); also elsewhere on the board
SW&INT_SG1: U12.10 (S1), U13.10 (S1); also elsewhere on the board
SW&INT_SG2: U12.9 (S2), U13.9 (S2); also elsewhere on the board
SW&INT_SG3: U12.6 (E*), U59.1 (1A); also elsewhere on the board

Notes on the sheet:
2xMUX8_1 : 5V @ 100mA Total current : 5V @ 106mA

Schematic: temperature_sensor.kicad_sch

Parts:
C53, C54: 10nF 50V; C_0805_2012Metric; PART NUMBER GRM2195C1H103JA01D
J110, J111: Jumper; PinHeader_1x03_P2.54mm_Vertical; PART NUMBER 61300311121
R164, R165: 0Ω; R_0805_2012Metric; PART NUMBER ERJ-6GEY0R00V
R166, R167: 100K 1% 1/10W; R_0603_1608Metric; PART NUMBER ERJ-3EKF1003V
RV6, RV7: Trim 10k; TRIM_3362P-1-103LF; PART NUMBER 3362P-1-103LF
TP118, TP119, TP120, TP121, TP124: TestPoint; KEYSTONE_5005; PART NUMBER 5005
U50: OR GATE 3IN; SOT95P280X145-6N; PART NUMBER SN74LVC1G332DBVR
U85, U86: COMP; DGK8; PART NUMBER LM393DGKR

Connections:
+5V: U50.5 (VCC); also elsewhere on the board
+5VA: R166.1, R167.1, RV6.3, RV7.3, U85.8 (VCC), U86.8 (VCC); also elsewhere on the board
GND: C53.2, C54.2, J110.3, J111.3, RV6.1, RV7.1, U50.2 (GND), U50.6 (C), U85.4 (GND), U85.5 (2IN+), U85.6 (2IN-), U86.4 (GND), U86.5 (2IN+), U86.6 (2IN-); also elsewhere on the board
M_TEMP_1: C53.1, R164.2, TP118.TP, U86.3 (1IN+); also elsewhere on the board
M_TEMP_2: C54.1, R165.2, TP120.TP, U85.3 (1IN+); also elsewhere on the board
M_TEMP_LIM1: RV6.2, TP119.TP, U86.2 (1IN-); also elsewhere on the board
M_TEMP_LIM2: RV7.2, TP121.TP, U85.2 (1IN-); also elsewhere on the board
unnamed: J110.1, R167.2, U86.1 (1OUT)
unnamed: J110.2, U50.1 (A)
unnamed: J111.1, R166.2, U85.1 (1OUT)
unnamed: J111.2, U50.3 (B)
TEMP_OUT_1: R164.1; also elsewhere on the board
TEMP_OUT_2: R165.1; also elsewhere on the board
TEMP_SEC: TP124.TP, U50.4 (Y); also elsewhere on the board

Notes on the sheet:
Do not populate
2xComp : 5VA @ 5mA 2xORGate : 5V @ 2mA 2xPot10k : 5VA @ 1mA 2x100k : 5VA @ 0,1mA Total current : 5V @ 2,1mA 5VA @ 6,5mA

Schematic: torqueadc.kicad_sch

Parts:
J68, J69, J70, J87, J88, J89: Jumper; PinHeader_1x03_P2.54mm_Vertical; PART NUMBER 61300311121
R89, R225, R228: 100k 1% 1/8W; R_0805_2012Metric; PART NUMBER ERJ-6ENF1003V
R206, R207, R208, R215, R216, R217, R218, R219, R220, R221, R233, R234, R235, R236, R237, R238, R239, R240, R241, R242, R243, R245, R246, R247, R248, R249, R259, R260, R261, R262: 10K 1% 1/10W; R_0603_1608Metric; PART NUMBER ERJ-3EKF1002V
R209, R210, R211, R222, R231, R250, R251, R255, R256: 3.3k 1% 1/8W; R_0805_2012Metric; PART NUMBER ERJ-6ENF3301V
R212, R213, R214, R224, R227, R230, R232, R257, R258: 0Ω; R_0805_2012Metric; PART NUMBER ERJ-6GEY0R00V
R223, R226, R229: 200k 1% 1/8W; R_0805_2012Metric; PART NUMBER ERJ-6ENF2003V
R244, R252, R253, R254, R263, R264: 100k 1% 1/20W; R_0201_0603Metric; PART NUMBER ERJ-1GNF1003C
TP11, TP12, TP13, TP15, TP16, TP81: TestPoint; KEYSTONE_5005; PART NUMBER 5005
U33, U34, U35, U36, U37, U38, U39, U40, U41: OP_AMP2; SOIC127P599X175-8N; PART NUMBER TL072IDR

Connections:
+5VA: R223.2, R226.2, R229.2, U33.8 (VCC+), U34.8 (VCC+), U35.8 (VCC+), U36.8 (VCC+), U37.8 (VCC+), U38.8 (VCC+), U39.8 (VCC+), U40.8 (VCC+), U41.8 (VCC+); also elsewhere on the board
-5VA: U33.4 (VCC-), U34.4 (VCC-), U35.4 (VCC-), U36.4 (VCC-), U37.4 (VCC-), U38.4 (VCC-), U39.4 (VCC-), U40.4 (VCC-), U41.4 (VCC-); also elsewhere on the board
DOR_TOR_DATA: J88.2; also elsewhere on the board
DOR_TOR_DATA1: R206.1; also elsewhere on the board
DOR_TOR_LIM_DATA: J70.2; also elsewhere on the board
DOR_TOR_LIM_DATA1: R249.1; also elsewhere on the board
EVE_TOR_DATA: J89.2; also elsewhere on the board
EVE_TOR_DATA1: R208.1; also elsewhere on the board
EVE_TOR_LIM_DATA: J69.2; also elsewhere on the board
EVE_TOR_LIM_DATA1: R248.1; also elsewhere on the board
EXT_TOR_DATA: J87.2; also elsewhere on the board
EXT_TOR_DATA1: R207.1; also elsewhere on the board
EXT_TOR_LIM_DATA: J68.2; also elsewhere on the board
EXT_TOR_LIM_DATA1: R215.1; also elsewhere on the board
GND: R89.1, R225.1, R228.1, R244.2, R252.2, R253.2, R254.2, R263.2, R264.2, U33.3 (1IN+), U33.5 (2IN+), U34.3 (1IN+), U34.5 (2IN+), U35.3 (1IN+), U35.5 (2IN+), U36.3 (1IN+), U36.5 (2IN+), U37.3 (1IN+), U38.3 (1IN+), U39.3 (1IN+), U40.3 (1IN+), U40.5 (2IN+), U41.3 (1IN+), U41.5 (2IN+); also elsewhere on the board
unnamed: J68.1, R240.1, U36.7 (2OUT)
unnamed: J68.3, R244.1
unnamed: J69.1, R260.1, U40.7 (2OUT)
unnamed: J69.3, R263.1
unnamed: J70.1, R262.1, U41.7 (2OUT)
unnamed: J70.3, R264.1
unnamed: J87.1, R247.2, U39.1 (1OUT)
unnamed: J87.3, R254.1
unnamed: J88.1, R246.2, U38.1 (1OUT)
unnamed: J88.3, R253.1
unnamed: J89.1, R245.2, U37.1 (1OUT)
unnamed: J89.3, R252.1
unnamed: R206.2, R211.1, U33.2 (1IN-)
unnamed: R207.2, R209.1, U34.2 (1IN-)
unnamed: R208.2, R210.1, U35.2 (1IN-)
unnamed: R209.2, R214.1
unnamed: R210.2, R212.1
unnamed: R211.2, R213.1
unnamed: R212.2, R220.2, TP12.TP, U35.1 (1OUT)
unnamed: R213.2, R216.2, TP13.TP, U33.1 (1OUT)
unnamed: R214.2, R218.2, TP11.TP, U34.1 (1OUT)
unnamed: R215.2, R222.1, U36.2 (1IN-)
unnamed: R216.1, R217.2, U33.6 (2IN-)
unnamed: R217.1, R235.1, TP16.TP, U33.7 (2OUT)
unnamed: R218.1, R219.2, U34.6 (2IN-)
unnamed: R219.1, R233.1, TP81.TP, U34.7 (2OUT)
unnamed: R220.1, R221.2, U35.6 (2IN-)
unnamed: R221.1, R234.1, TP15.TP, U35.7 (2OUT)
unnamed: R222.2, R231.1
unnamed: R223.1, R224.2
unnamed: R224.1, R225.2, R237.1
unnamed: R226.1, R227.2
unnamed: R227.1, R228.2, R238.1
unnamed: R229.1, R230.2
unnamed: R89.2, R230.1, R236.1
unnamed: R231.2, R232.1
unnamed: R232.2, R239.2, U36.1 (1OUT)
unnamed: R233.2, R238.2, R243.1
unnamed: R234.2, R236.2, R241.1
unnamed: R235.2, R237.2, R242.1
unnamed: R239.1, R240.2, U36.6 (2IN-)
unnamed: R241.2, R245.1, U37.2 (1IN-)
unnamed: R242.2, R246.1, U38.2 (1IN-)
unnamed: R243.2, R247.1, U39.2 (1IN-)
unnamed: R248.2, R250.1, U40.2 (1IN-)
unnamed: R249.2, R251.1, U41.2 (1IN-)
unnamed: R250.2, R255.1
unnamed: R251.2, R256.1
unnamed: R255.2, R257.1
unnamed: R256.2, R258.1
unnamed: R257.2, R259.2, U40.1 (1OUT)
unnamed: R258.2, R261.2, U41.1 (1OUT)
unnamed: R259.1, R260.2, U40.6 (2IN-)
unnamed: R261.1, R262.2, U41.6 (2IN-)

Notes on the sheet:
0-3,3V
-3,3-0V
±1,65V(+)
±1,65V(-)
0-5V
NOTES:
±5V
12xOP : 5VA @ 37,5mA 3x300k : 5VA @ 0,06mA Total current : 5VA @ 40mA
Topologie (gauche) : - Atténuateur pour passer de ±5V à ±1,65V - Gain négatif pour inverser le signal de l'atténuateur (Ampli-OP inverseur) - Sommateur pour faire un offset de 1,65V et avoir 0-3,3V Topologie (gauche) : - Atténuateur pour passer de 0-5V à -3,3-0V - Gain négatif pour inverser le sign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

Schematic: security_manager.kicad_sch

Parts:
NT13: NetTie_2; NetTie-2_THT_Pad0.3mm
TP24: TestPoint; KEYSTONE_5005; PART NUMBER 5005
U8, U9: OR Gate 8; D14; PART NUMBER CD4078BM96
U15: OR GATE 3IN; SOT95P280X145-6N; PART NUMBER SN74LVC1G332DBVR

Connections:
+5V: U8.14 (VDD), U9.14 (VDD), U15.5 (VCC); also elsewhere on the board
ALIM_SEC: NT13.2, TP24.TP, U15.4 (Y); also elsewhere on the board
AMP_SEC: U8.5 (D); also elsewhere on the board
GND: U8.7 (VSS), U9.7 (VSS), U9.10 (F), U9.11 (G), U9.12 (H), U15.2 (GND), U15.6 (C); also elsewhere on the board
INT_POS_SEC: U8.10 (F); also elsewhere on the board
INT_PROX_SEC: U8.11 (G); also elsewhere on the board
INT_SENSOR_SEC: U8.12 (H); also elsewhere on the board
LEFTRIGHT_SEC: U9.2 (A); also elsewhere on the board
MAX_SW_SEC: U9.3 (B); also elsewhere on the board
unnamed: U8.1 (AK), U15.1 (A)
unnamed: U9.1 (AK), U15.3 (B)
POS_BUT_SEC: U9.4 (C); also elsewhere on the board
POS_FSR_SEC: U8.3 (B); also elsewhere on the board
POS_LC_SEC: U8.4 (C); also elsewhere on the board
PROX_BUT_SEC: U9.5 (D); also elsewhere on the board
PROX_OPTO_SEC: U9.9 (E); also elsewhere on the board
TEMP_SEC: U8.2 (A); also elsewhere on the board
TOR_SEC: U8.9 (E); also elsewhere on the board
URG_SEC: NT13.1; also elsewhere on the board

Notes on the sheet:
1xOrGate3IN : 5V @ 0,01mA 2xORGate8CH : 5V @ 2mA Total current : 5V @ 3mA
Notes :

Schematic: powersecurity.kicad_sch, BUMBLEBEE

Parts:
C1: 10uF 10V X7R; C_0805_2012Metric; PART NUMBER GRM21BR71A106KA73L
C2: 220uF 20% 50V; CAP_EEHZS1H221P; PART NUMBER EEH-ZS1H221P
D1, D2: SHOTT 30V 12A; DIO_SS12P2L-M3_86A; PART NUMBER SS12P3L-M3/86A
D115: LED; WL-SMCW_0603; PART NUMBER 150060RS75000
F1: Fuse; 696108003002; PART NUMBER 696108003002
J1, J3, J4: 14 AWG; PHOENIX_1755736; PART NUMBER 1755736
J2: Jumper; PinHeader_1x03_P2.54mm_Vertical; PART NUMBER 61300311121
K1: Relay; UD2_NU_KEM-L; PART NUMBER UD2-5NU
Q1: MOSFET 20V 200mA; DIO_RB558WMF_ROM; PART NUMBER RE1C002UNTCL
R1, R4: 10K 1% 1/10W; R_0603_1608Metric; PART NUMBER ERJ-3EKF1002V
R2: 5.1K 1% 1/10W; R_0603_1608Metric; PART NUMBER ERJ-3EKF5101V
R184: 2,2k 1% 1/2W; R_0805_2012Metric; PART NUMBER ERJ-P06F2201V
TP1, TP2, TP3, TP4, TP5: TestPoint; KEYSTONE_5005; PART NUMBER 5005
U1: TVS 24V; SOT-23-3_DBZ_TEX; PART NUMBER TSM36ADBZR
U2: Shott 100V; D2PAK_STM; PART NUMBER STPS20M100SG-TR
U3: Inverter; SN74LVC3G14DCUT; PART NUMBER SN74LVC3G14DCUT
U4: SR-Latch; CD4044BPWR; PART NUMBER CD4044BPWR

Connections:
+5V: D1.3, K1.8, U3.8 (VCC), U4.5 (ENABLE), U4.16 (VDD); also elsewhere on the board
+24V: J2.1, K1.3; also elsewhere on the board
ALIM_SEC: U4.3 (S1); also elsewhere on the board
GND: C1.2, C2.2, D2.1, D2.2, D115.1 (K), J1.2, J3.2, J4.2, Q1.2 (S), R1.2, R4.2, U1.1 (GND), U1.2 (GND), U2.1, U2.2, U3.3 (2A), U3.4 (GND), U3.6 (3A), U4.8 (VSS); also elsewhere on the board
unnamed: C1.1, R2.2, U3.1 (1A)
unnamed: C2.1, F1.2, J2.2, R184.2, TP2.TP, U1.3 (IO), U2.3
unnamed: D1.1, D1.2, J4.1, K1.1, Q1.3 (D), TP4.TP
unnamed: D2.3, J3.1, K1.2, TP3.TP
unnamed: D115.2 (A), R184.1
unnamed: F1.1, J1.1
unnamed: Q1.1 (G), R4.1, TP5.TP, U4.13 (Q1)
unnamed: TP1.TP, U3.7 (1Y), U4.4 (R1)
RESET: R1.1, R2.1; also elsewhere on the board

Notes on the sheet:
Contacteur ouvert = moteur activé Sortie 5V et 24V pour PCB 48V externe futur
Notes :
24V
Vers contacteur 24V
OutPut 5V sécurité
Contacteur : 24V @ 100mA CoilRelais : 5V @ 20mA FreeWheel5V : 5V @ 2mA FreeWheel24V : 24V @ 4,16mA Latch : 5V @ 1mA Total Current : 5V @ 25,2 mA 24V @ 109,37mA

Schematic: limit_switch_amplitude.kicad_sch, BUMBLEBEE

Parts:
C29, C30, C31, C32, C33, C34, C35: 10uF 10V X7R; C_0805_2012Metric; PART NUMBER GRM21BR71A106KA73L
J90, J91, J92: Jumper; PinHeader_1x03_P2.54mm_Vertical; PART NUMBER 61300311121
R98, R99, R100, R101, R102, R103, R110: 10K 1% 1/10W; R_0603_1608Metric; PART NUMBER ERJ-3EKF1002V
R104, R105, R106, R107, R108, R109, R111: 5.1K 1% 1/10W; R_0603_1608Metric; PART NUMBER ERJ-3EKF5101V
TP84: TestPoint; KEYSTONE_5005; PART NUMBER 5005
U11, U42, U43: Inverter; SN74LVC3G14DCUT; PART NUMBER SN74LVC3G14DCUT
U49: OR GATE 3IN; SOT95P280X145-6N; PART NUMBER SN74LVC1G332DBVR

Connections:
+5V: U11.8 (VCC), U42.8 (VCC), U43.8 (VCC), U49.5 (VCC); also elsewhere on the board
GND: C29.2, C30.2, C31.2, C32.2, C33.2, C34.2, C35.2, J90.3, J91.3, J92.3, R98.2, R99.2, R100.2, R101.2, R102.2, R103.2, R110.2, U11.4 (GND), U42.4 (GND), U43.3 (2A), U43.4 (GND), U43.6 (3A), U49.2 (GND); also elsewhere on the board
MAX_SW_1: R99.1, R104.1; also elsewhere on the board
MAX_SW_2: R98.1, R105.1; also elsewhere on the board
MAX_SW_3: R100.1, R106.1; also elsewhere on the board
MAX_SW_SEC: TP84.TP, U49.4 (Y); also elsewhere on the board
MIN_SW_1: R101.1, R107.1; also elsewhere on the board
MIN_SW_2: R102.1, R108.1; also elsewhere on the board
MIN_SW_3: R103.1, R109.1; also elsewhere on the board
unnamed: C29.1, R104.2, U11.1 (1A)
unnamed: C30.1, R105.2, U11.3 (2A)
unnamed: C31.1, R106.2, U11.6 (3A)
unnamed: C32.1, R107.2, U42.1 (1A)
unnamed: C33.1, R108.2, U42.3 (2A)
unnamed: C34.1, R109.2, U42.6 (3A)
unnamed: C35.1, R111.2, U43.1 (1A)
unnamed: J90.1, U11.2 (3Y)
unnamed: J91.1, U11.7 (1Y)
unnamed: J92.1, U11.5 (2Y)
SWMAX1: J91.2, U49.1 (A); also elsewhere on the board
SWMAX2: J92.2, U49.3 (B); also elsewhere on the board
SWMAX3: J90.2, U49.6 (C); also elsewhere on the board
SWMIN1: U42.7 (1Y); also elsewhere on the board
SWMIN2: U42.5 (2Y); also elsewhere on the board
SWMIN3: U42.2 (3Y); also elsewhere on the board
URG_SEC: U43.7 (1Y); also elsewhere on the board
URG_USER: R110.1, R111.1; also elsewhere on the board

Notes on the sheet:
Debouncing
2xOrGate : 5V @ 1mA 3x100k : 5V @ 0,15mA Total current : 5V @ 2mA

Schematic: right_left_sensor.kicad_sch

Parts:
C36, C37: 10uF 10V X7R; C_0805_2012Metric; PART NUMBER GRM21BR71A106KA73L
J93, J94: Jumper; PinHeader_1x03_P2.54mm_Vertical; PART NUMBER 61300311121
R115, R116: 10K 1% 1/10W; R_0603_1608Metric; PART NUMBER ERJ-3EKF1002V
R117, R118: 5.1K 1% 1/10W; R_0603_1608Metric; PART NUMBER ERJ-3EKF5101V
TP85: TestPoint; KEYSTONE_5005; PART NUMBER 5005
U10: XNOR Gate; SC-74A_SOT753_NEX; PART NUMBER 74LV1T87GVH
U44: Inverter; SN74LVC3G14DCUT; PART NUMBER SN74LVC3G14DCUT

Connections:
+5V: U10.5 (VCC), U44.8 (VCC); also elsewhere on the board
GND: C36.2, C37.2, J93.3, J94.3, R115.2, R116.2, U10.3 (GND), U44.4 (GND), U44.6 (3A); also elsewhere on the board
LEFTRIGHT_SEC: TP85.TP, U10.4 (Y); also elsewhere on the board
MAX_SW_4: R115.1, R117.1; also elsewhere on the board
MAX_SW_5: R116.1, R118.1; also elsewhere on the board
unnamed: C36.1, R117.2, U44.1 (1A)
unnamed: C37.1, R118.2, U44.3 (2A)
unnamed: J93.1, U44.7 (1Y)
unnamed: J94.1, U44.5 (2Y)
SWMAX4: J93.2, U10.1 (B); also elsewhere on the board
SWMAX5: J94.2, U10.2 (A); also elsewhere on the board

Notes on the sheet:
Debouncing
1xXNORGate : 5V @ 50mA 2xNOTGate : 5V @ 2mA Total current : 5V @ 55mA

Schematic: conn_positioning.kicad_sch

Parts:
D79, D80, D81, D85, D86, D87, D91, D92, D93, D94, D95, D96, D112, D113, D114: TVS; DPY2_TEX; PART NUMBER TPD1E05U06DPYR
J43, J44, J45: 5POS; CON_39302050; PART NUMBER 39302050
J46, J47, J48: 2POS; CON_39281023; PART NUMBER 0039281023
J49, J50, J51: 4POS; CON_39301049; PARTREV 03.03.2021
R29, R30, R31: 1K 1% 1/10W; R_0603_1608Metric; PART NUMBER ERJ-3EKF1001V
R32, R33, R34, R172, R182, R183: 100K 1% 1/10W; R_0603_1608Metric; PART NUMBER ERJ-3EKF1003V
R169, R176, R177: 5.1K 1% 1/10W; R_0603_1608Metric; PART NUMBER ERJ-3EKF5101V

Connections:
+5V: R29.2, R30.2, R31.2; also elsewhere on the board
+5VA: J43.2, J44.2, J45.2, J49.3, J50.3, J51.3, R32.1, R33.1, R34.1, R172.1, R182.1, R183.1; also elsewhere on the board
BUT_POS1: D85.1 (K), J46.2; also elsewhere on the board
BUT_POS2: D86.1 (K), J47.2; also elsewhere on the board
BUT_POS3: D87.1 (K), J48.2; also elsewhere on the board
FSR_POS1: D94.1 (K), J49.2, R176.2; also elsewhere on the board
FSR_POS1_INT: D93.1 (K), J49.4, R32.2; also elsewhere on the board
FSR_POS2: D95.1 (K), J50.2, R177.2; also elsewhere on the board
FSR_POS2_INT: D91.1 (K), J50.4, R33.2; also elsewhere on the board
FSR_POS3: D96.1 (K), J51.2, R169.2; also elsewhere on the board
FSR_POS3_INT: D92.1 (K), J51.4, R34.2; also elsewhere on the board
GND: D79.2 (A), D80.2 (A), D81.2 (A), D85.2 (A), D86.2 (A), D87.2 (A), D91.2 (A), D92.2 (A), D93.2 (A), D94.2 (A), D95.2 (A), D96.2 (A), D112.2 (A), D113.2 (A), D114.2 (A), J43.4, J43.5, J44.4, J44.5, J45.4, J45.5, J49.1, J50.1, J51.1, R169.1, R176.1, R177.1; also elsewhere on the board
LC_POS1: D79.1 (K), J43.3; also elsewhere on the board
LC_POS1_INT: D112.1 (K), J43.1, R172.2; also elsewhere on the board
LC_POS2: D80.1 (K), J44.3; also elsewhere on the board
LC_POS2_INT: D113.1 (K), J44.1, R182.2; also elsewhere on the board
LC_POS3: D81.1 (K), J45.3; also elsewhere on the board
LC_POS3_INT: D114.1 (K), J45.1, R183.2; also elsewhere on the board
unnamed: J46.1, R29.1
unnamed: J47.1, R30.1
unnamed: J48.1, R31.1

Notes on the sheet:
But Pos 2
LC Pos 3
But Pos 3
FSR 1
3xRes1k : 5V @ 15mA 3xRes100k : 5VA @ 0,3mA 3xLC : 5VA @ 15,6mA Total current : 5V @ 15,75mA 5VA @ 17mA
FSR 3
FSR 2
LC Pos 2
But Pos 1
LC Pos 1

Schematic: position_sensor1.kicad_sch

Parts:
C44, C45, C46: 10nF 50V; C_0805_2012Metric; PART NUMBER GRM2195C1H103JA01D
J101, J102, J103: Jumper; PinHeader_1x03_P2.54mm_Vertical; PART NUMBER 61300311121
R137, R138, R139: 0Ω; R_0805_2012Metric; PART NUMBER ERJ-6GEY0R00V
R140, R141, R142, R143, R144, R145: 100K 1% 1/10W; R_0603_1608Metric; PART NUMBER ERJ-3EKF1003V
RV1, RV2, RV27: Trim 10k; TRIM_3362P-1-103LF; PART NUMBER 3362P-1-103LF
TP94, TP95, TP96, TP97, TP98, TP99, TP103: TestPoint; KEYSTONE_5005; PART NUMBER 5005
U48: Inverter; SN74LVC3G14DCUT; PART NUMBER SN74LVC3G14DCUT
U67, U68, U69: COMP; DGK8; PART NUMBER LM393DGKR
U70, U71: AND Gate; SOT95P270X145-5N; PART NUMBER SN74LVC1G08DBVR

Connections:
+5V: U48.8 (VCC), U70.5 (VCC), U71.5 (VCC); also elsewhere on the board
+5VA: R140.1, R141.1, R142.1, R143.2, R144.2, R145.2, RV1.3, RV2.3, RV27.3, U67.8 (VCC), U68.8 (VCC), U69.8 (VCC); also elsewhere on the board
GND: C44.2, C45.2, C46.2, RV1.1, RV2.1, RV27.1, U48.3 (2A), U48.4 (GND), U48.6 (3A), U67.4 (GND), U67.5 (2IN+), U67.6 (2IN-), U68.4 (GND), U68.5 (2IN+), U68.6 (2IN-), U69.4 (GND), U69.5 (2IN+), U69.6 (2IN-), U70.3 (GND), U71.3 (GND); also elsewhere on the board
LC_POS1: R137.1; also elsewhere on the board
LC_POS2: R138.1; also elsewhere on the board
LC_POS3: R139.1; also elsewhere on the board
M_LC_POS1: C44.1, R137.2, TP94.TP, U67.3 (1IN+); also elsewhere on the board
M_LC_POS2: C45.1, R138.2, TP96.TP, U68.3 (1IN+); also elsewhere on the board
M_LC_POS3: C46.1, R139.2, TP98.TP, U69.3 (1IN+); also elsewhere on the board
M_LC_POS_LIM1: RV27.2, TP95.TP, U67.2 (1IN-); also elsewhere on the board
M_LC_POS_LIM2: RV1.2, TP97.TP, U68.2 (1IN-); also elsewhere on the board
M_LC_POS_LIM3: RV2.2, TP99.TP, U69.2 (1IN-); also elsewhere on the board
unnamed: J101.1, R140.2, U68.1 (1OUT)
unnamed: J101.2, U70.2 (B)
unnamed: J101.3, R143.1
unnamed: J102.1, R141.2, U67.1 (1OUT)
unnamed: J102.2, U70.1 (A)
unnamed: J102.3, R144.1
unnamed: J103.1, R142.2, U69.1 (1OUT)
unnamed: J103.2, U71.2 (B)
unnamed: J103.3, R145.1
unnamed: U48.1 (1A), U71.4 (Y)
unnamed: U70.4 (Y), U71.1 (A)
POS_LC_SEC: TP103.TP, U48.7 (1Y); also elsewhere on the board

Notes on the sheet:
Do not populate
3xComp : 5VA @ 7,5mA 2xANDGate : 5V @ 2mA 1xNOTGate : 5V @ 1mA 3xPot10k : 5VA @ 1,5mA 6x100k : 5VA @ 0,3mA Total current : 5V @ 3,15mA 5VA @ 10mA

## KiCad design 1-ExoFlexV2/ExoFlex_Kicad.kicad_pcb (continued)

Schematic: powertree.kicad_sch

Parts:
C3, C5, C12: 100uF 20% 35V; CAP_K1V101P_PAN; PART NUMBER EEE-FK1V101P
C4: 33uF 50V X7R; CAPC6153X500N; PART NUMBER KCM55WR71H336MH01L
C6: 2,2uF 35V X5R; C_0603_1608Metric; PART NUMBER GRM188R6YA225KA12D
C7, C8: 4,7uF 35V X7R; C_0805_2012Metric; PART NUMBER GRM21BZ7YA475KE15K
C9: 0,47uF 6,3V X5R; C_01005_0402Metric; PART NUMBER GRM022R60J474ME15L
C10: 47nF 6,3V X5R; C_01005_0402Metric; PART NUMBER GRM022R60J473ME15L
C11, C213, C214: 1uF 10% 20V; CAPMP3216X180N; PART NUMBER T491A105K020AT
C13, C14: 47uF 10V X5R; C_0805_2012Metric; PART NUMBER GRM21BR61A476ME15L
C15, C16: 330uF 10% 10V; CAPMP7.6X4.3_3.1N_KEM; PART NUMBER T495D337K010ATE150
D6, D9: TVS; DPY2_TEX; PART NUMBER TPD1E05U06DPYR
D116, D117, D118: LED; WL-SMCW_0603; PART NUMBER 150060RS75000
J5, J6: Jumper; PinHeader_1x03_P2.54mm_Vertical; PART NUMBER 61300311121
J7, J71: Jumper 5,2A; PinHeader_1x03_P2.54mm_Vertical; PART NUMBER MTLW-103-07-G-S-230
J8: USB-C; MOLEX_1054500101; PARTREV A7
J81: 14 AWG; PHOENIX_1755736; PART NUMBER 1755736
L1, L2: 1uH 20% 2,3A; L_1210_3225Metric; PART NUMBER BWQC003225161R0MH1
L3: 10uH 10% 150mA; INDC2012X145N; PART NUMBER LBR2012T100K
R5: 5.9k 1% 1/20W; R_0201_0603Metric; PART NUMBER ERJ-1GNF5901C
R6: 100 1% 1/10W; R_0603_1608Metric; PART NUMBER ERJ-3EKF1000V
R7: 8.45k 1% 1/20W; R_0201_0603Metric; PART NUMBER ERJ-1GNF8451C
R46, R47, R185: 270 1% 1/4W; R_0805_2012Metric; PART NUMBER ERJ-PB6B2700V
R55: 530 1% 0,1W; R_0603_1608Metric; PART NUMBER RN73H1JTTD5300F25
R57: 270 1% 1/10W; R_0603_1608Metric; PART NUMBER ERJ-3EKF2700V
R58: 820 1% 1/10W; R_0603_1608Metric; PART NUMBER ERJ-3EKF8200V
R73: 240 1% 1/10W; R_0603_1608Metric; PART NUMBER ERJ-3EKF2400V
R74: 720 1% 1/10W; R_0603_1608Metric; PART NUMBER CRCW0603720RFKTA
R76, R112: 5.1K 1% 1/10W; R_0603_1608Metric; PART NUMBER ERJ-3EKF5101V
TP6, TP7, TP8, TP9, TP10: TestPoint; KEYSTONE_5005; PART NUMBER 5005
U5: DCDC24V/8V; PTN78060WAD; PART NUMBER PTN78060WAD
U6: DCDC24V/5V NUM; NDY0011A_L; PART NUMBER LMZ23610TZ/NOPB
U7: DCDC 24V/-7,8V ANA; PTN78000; PART NUMBER PTN78000AAH
U14: TVS 24V; SOT-23-3_DBZ_TEX; PART NUMBER TSM36ADBZR
U123: LDO -5VA; TO92260P482H934-3N; PART NUMBER LM337LZ/LFT3
U124: LDO 5VA; T03B_TEX; PART NUMBER LM338T/NOPB

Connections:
+5V: J7.1, J8.A4 (VBUS_A4), J8.A9 (VBUS_A9), J8.B4 (VBUS_B4), J8.B9 (VBUS_B9), J71.1, J81.1; also elsewhere on the board
+5VA: J5.1; also elsewhere on the board
+24V: L1.1, L2.1, L3.1; also elsewhere on the board
-5VA: J6.1; also elsewhere on the board
GND: C3.2, C4.2, C5.2, C6.2, C7.2, C8.2, C9.2, C10.2, C11.2, C12.1, C13.2, C14.2, C15.2, C16.2, C213.2, C214.2, D6.2 (A), D9.2 (A), D116.1 (K), D117.1 (K), D118.2 (A), J8.A1 (GND_A1), J8.A12 (GND_A12), J8.B1 (GND_B1), J8.B12 (GND_B12), J8.SH1 (SHIELD3), J8.SH2 (SHIELD4), J8.SH3 (SHIELD1), J8.SH4 (SHIELD2), J81.2, R5.1, R6.1, R58.1, R74.1, R76.1, R112.2, U5.1 (GND), U5.7 (GND), U6.3 (SYNC), U6.5 (AGND), U6.6 (AGND), U6.12 (EP), U7.P5 (GND), U14.1 (GND), U14.2 (GND); also elsewhere on the board
unnamed: C4.1, L1.2, U6.1 (VIN), U6.2 (VIN)
unnamed: C5.1, C7.1, C8.1, L3.2, U7.P2 (VIN)
unnamed: C6.1, L2.2, U5.2 (VI)
unnamed: C9.1, U6.8 (SS)
unnamed: C10.1, C13.1, C14.1, C15.1, C16.1, J7.2, J71.2, R55.2, R185.2, TP9.TP, U6.10 (VOUT), U6.11 (VOUT), U14.3 (IO)
unnamed: C11.1, C12.2, R7.1, TP6.TP, U7.P1 (VOUT), U123.3 (IN)
unnamed: C3.1, C213.1, TP10.TP, U5.5 (SENSE), U5.6 (VO), U124.3 (IN)
unnamed: C214.1, D9.1 (K), J6.2, R47.2, R73.2, TP8.TP, U123.2 (OUT)
unnamed: D6.1 (K), J5.2, R46.2, R57.2, TP7.TP, U124.2 (OUT)
unnamed: D116.2 (A), R185.1
unnamed: D117.2 (A), R46.1
unnamed: D118.1 (K), R47.1
unnamed: J7.3, J71.3
unnamed: J8.A5 (CC1), R76.2
unnamed: J8.B5 (CC2), R112.1
unnamed: R5.2, U5.4 (VOADJUST)
unnamed: R7.2, U7.P4 (SET)
unnamed: R6.2, R55.1, U6.7 (FB)
unnamed: R57.1, R58.2, U124.1 (ADJ)
unnamed: R73.1, R74.2, U123.1 (ADJ)

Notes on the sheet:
REV 1
__HS HERE__
15/07/2024 - Louis-Daniel Gaulin
Vers PI5 5V
Régulateur 5VNUM: 24V @ 1,45A Régulateur 5VA : 24 @ 110mA Régulateur -5VA : 24 @ 25mA Contacteur : 24V @ 110mA Total Current : 24V @ 1,695A

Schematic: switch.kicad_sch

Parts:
D39, D40, D41, D42, D47, D48, D49, D50, D55, D56: TVS; DPY2_TEX; PART NUMBER TPD1E05U06DPYR
J25, J26, J27, J28, J29, J30, J31, J32, J33, J34: 2POS; CON_39281023; PART NUMBER 0039281023
R11, R12, R13, R14, R15, R16, R17, R18, R19, R20: 1K 1% 1/10W; R_0603_1608Metric; PART NUMBER ERJ-3EKF1001V

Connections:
+5V: R11.2, R12.2, R13.2, R14.2, R15.2, R16.2, R17.2, R18.2, R19.2, R20.2; also elsewhere on the board
GND: D39.2 (A), D40.2 (A), D41.2 (A), D42.2 (A), D47.2 (A), D48.2 (A), D49.2 (A), D50.2 (A), D55.2 (A), D56.2 (A); also elsewhere on the board
MAX_SW_1: D39.1 (K), J25.2; also elsewhere on the board
MAX_SW_2: D41.1 (K), J27.2; also elsewhere on the board
MAX_SW_3: D47.1 (K), J29.2; also elsewhere on the board
MAX_SW_4: D49.1 (K), J31.2; also elsewhere on the board
MAX_SW_5: D50.1 (K), J32.2; also elsewhere on the board
MIN_SW_1: D40.1 (K), J26.2; also elsewhere on the board
MIN_SW_2: D42.1 (K), J28.2; also elsewhere on the board
MIN_SW_3: D48.1 (K), J30.2; also elsewhere on the board
unnamed: J25.1, R14.1
unnamed: J26.1, R11.1
unnamed: J27.1, R12.1
unnamed: J28.1, R13.1
unnamed: J29.1, R15.1
unnamed: J30.1, R16.1
unnamed: J31.1, R17.1
unnamed: J32.1, R18.1
unnamed: J33.1, R19.1
unnamed: J34.1, R20.1
RESET: D56.1 (K), J34.2; also elsewhere on the board
URG_USER: D55.1 (K), J33.2; also elsewhere on the board

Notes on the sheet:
RESET
SWMIN2
URG1
SWMAX3
SWMIN1
SWMAX1
SWMIN3
10xRes1k : 5V @ 50mA Total current : 5V @ 52,5mA
SWMAX5
SWMAX4
SWMAX2

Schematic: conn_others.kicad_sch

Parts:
D100, D101, D102, D103, D104, D106, D108: TVS; DPY2_TEX; PART NUMBER TPD1E05U06DPYR
J52: 2POS; CON_39281023; PART NUMBER 0039281023
J53, J54: 3POS; CON_39301039; PARTREV 03.03.2021
J57: 6POS; PinSocket_1x06_P2.54mm_Vertical; PART NUMBER SMC-1-06-1-GT

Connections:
+5V: D104.1 (K), J57.1; also elsewhere on the board
+5VA: J53.3, J54.3; also elsewhere on the board
/CONNECTOR (OTHERS)/CANH: D101.1 (K), J52.1, J57.5
/CONNECTOR (OTHERS)/CANL: D103.1 (K), J52.2, J57.6
CAN_RD: D100.1 (K), J57.4; also elsewhere on the board
CAN_TD: D102.1 (K), J57.3; also elsewhere on the board
GND: D100.2 (A), D101.2 (A), D102.2 (A), D103.2 (A), D104.2 (A), D106.2 (A), D108.2 (A), J53.1, J54.1, J57.2; also elsewhere on the board
TEMP_OUT_1: D106.1 (K), J53.2; also elsewhere on the board
TEMP_OUT_2: D108.1 (K), J54.2; also elsewhere on the board

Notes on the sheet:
Notes :
Bus Adapter : 5V @ 75mA 2xTempSensor : N/A (uA) Total current : 5V @ 78,75mA
Temp 2
CAN Bus
Temp 1

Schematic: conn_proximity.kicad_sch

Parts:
D59, D60, D61, D62, D67, D68, D69, D70, D71, D72, D73, D74: TVS; DPY2_TEX; PART NUMBER TPD1E05U06DPYR
J35, J36, J37, J38: 2POS; CON_39281023; PART NUMBER 0039281023
J39, J40, J41, J42: 4POS; CON_39301049; PARTREV 03.03.2021
R21, R22, R23, R24: 1K 1% 1/10W; R_0603_1608Metric; PART NUMBER ERJ-3EKF1001V
R25, R26, R27, R28: 100K 1% 1/10W; R_0603_1608Metric; PART NUMBER ERJ-3EKF1003V
R114, R120: 165 1% 1/20W; R_0201_0603Metric; PART NUMBER ERJ-1GNF1650C
R119, R168: 464 1% 1/20W; R_0201_0603Metric; PART NUMBER ERJ-1GNF4640C

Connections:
+5V: R21.2, R22.2, R23.2, R24.2, R25.1, R26.1, R27.1, R28.1, R114.1, R119.1, R120.1, R168.1; also elsewhere on the board
BUT_PROX_LEFT1: D59.1 (K), J35.2; also elsewhere on the board
BUT_PROX_LEFT2: D60.1 (K), J36.2; also elsewhere on the board
BUT_PROX_RIGHT1: D61.1 (K), J37.2; also elsewhere on the board
BUT_PROX_RIGHT2: D62.1 (K), J38.2; also elsewhere on the board
EMI_PROX1: D71.1 (K), J39.2
EMI_PROX1_INT: D67.1 (K), J39.4, R25.2; also elsewhere on the board
EMI_PROX2: D73.1 (K), J41.2
EMI_PROX2_INT: D69.1 (K), J41.4, R27.2; also elsewhere on the board
GND: D59.2 (A), D60.2 (A), D61.2 (A), D62.2 (A), D67.2 (A), D68.2 (A), D69.2 (A), D70.2 (A), D71.2 (A), D72.2 (A), D73.2 (A), D74.2 (A), J39.1, J40.1, J41.1, J42.1; also elsewhere on the board
unnamed: J35.1, R21.1
unnamed: J36.1, R22.1
unnamed: J37.1, R23.1
unnamed: J38.1, R24.1
unnamed: J39.3, R114.2
unnamed: J40.3, R119.2
unnamed: J41.3, R120.2
unnamed: J42.3, R168.2
REC_PROX1: D72.1 (K), J40.2; also elsewhere on the board
REC_PROX1_INT: D68.1 (K), J40.4, R26.2; also elsewhere on the board
REC_PROX2: D74.1 (K), J42.2; also elsewhere on the board
REC_PROX2_INT: D70.1 (K), J42.4, R28.2; also elsewhere on the board

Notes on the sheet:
Emi Prox 2
But Prox L2
Rec Prox 1
Emi Prox 1
But Prox R1
Rec Prox 2
But Prox R2
But Prox L1
4xRes1k : 5V @ 20mA 4xRes100k : 5V @ 0,2mA 2x165 : 5V @ 30mA 2x464 : 5V @ 10,7mA Total current : 5V @ 64mA

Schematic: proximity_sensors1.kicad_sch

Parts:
C38, C39, C40, C41: 10uF 10V X7R; C_0805_2012Metric; PART NUMBER GRM21BR71A106KA73L
C42, C43: 10nF 50V; C_0805_2012Metric; PART NUMBER GRM2195C1H103JA01D
J95, J96, J97, J98, J99, J100: Jumper; PinHeader_1x03_P2.54mm_Vertical; PART NUMBER 61300311121
R121, R122, R123, R124: 10K 1% 1/10W; R_0603_1608Metric; PART NUMBER ERJ-3EKF1002V
R125, R126, R127, R128: 5.1K 1% 1/10W; R_0603_1608Metric; PART NUMBER ERJ-3EKF5101V
R129, R130: 0Ω; R_0805_2012Metric; PART NUMBER ERJ-6GEY0R00V
R131, R132, R133, R134, R135, R136: 100K 1% 1/10W; R_0603_1608Metric; PART NUMBER ERJ-3EKF1003V
TP92, TP93: TestPoint; KEYSTONE_5005; PART NUMBER 5005
U45, U46, U47: Inverter; SN74LVC3G14DCUT; PART NUMBER SN74LVC3G14DCUT
U62, U63, U64, U65: AND Gate; SOT95P270X145-5N; PART NUMBER SN74LVC1G08DBVR

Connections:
+5V: R131.2, R132.2, R133.2, R134.2, R135.2, R136.2, U45.8 (VCC), U46.8 (VCC), U47.8 (VCC), U62.5 (VCC), U63.5 (VCC), U64.5 (VCC), U65.5 (VCC); also elsewhere on the board
BUT_PROX_LEFT1: R121.1, R125.1; also elsewhere on the board
BUT_PROX_LEFT2: R122.1, R126.1; also elsewhere on the board
BUT_PROX_RIGHT1: R123.1, R127.1; also elsewhere on the board
BUT_PROX_RIGHT2: R124.1, R128.1; also elsewhere on the board
GND: C38.2, C39.2, C40.2, C41.2, C42.2, C43.2, R121.2, R122.2, R123.2, R124.2, U45.4 (GND), U46.4 (GND), U46.5 (2Y), U46.6 (3A), U47.3 (2A), U47.4 (GND), U47.6 (3A), U62.3 (GND), U63.3 (GND), U64.3 (GND), U65.3 (GND); also elsewhere on the board
M_BUT_PROX_L1: J98.2, U64.1 (A); also elsewhere on the board
M_BUT_PROX_L2: J97.2, U64.2 (B); also elsewhere on the board
M_BUT_PROX_R1: J95.2, U62.1 (A); also elsewhere on the board
M_BUT_PROX_R2: J99.2, U62.2 (B); also elsewhere on the board
M_REC_PROX1: J100.2, U63.1 (A); also elsewhere on the board
M_REC_PROX2: J96.2, U63.2 (B); also elsewhere on the board
unnamed: C38.1, R125.2, U45.1 (1A)
unnamed: C39.1, R126.2, U45.3 (2A)
unnamed: C40.1, R127.2, U45.6 (3A)
unnamed: C41.1, R128.2, U46.1 (1A)
unnamed: C42.1, J100.1, R129.2
unnamed: C43.1, J96.1, R130.2
unnamed: J95.1, U45.2 (3Y)
unnamed: J95.3, R131.1
unnamed: J96.3, R132.1
unnamed: J97.1, U45.5 (2Y)
unnamed: J97.3, R133.1
unnamed: J98.1, U45.7 (1Y)
unnamed: J98.3, R134.1
unnamed: J99.1, U46.7 (1Y)
unnamed: J99.3, R135.1
unnamed: J100.3, R136.1
unnamed: U47.1 (1A), U65.4 (Y)
unnamed: U62.4 (Y), U65.2 (B)
unnamed: U64.4 (Y), U65.1 (A)
PROX_BUT_SEC: TP92.TP, U47.7 (1Y); also elsewhere on the board
PROX_OPTO_SEC: TP93.TP, U63.4 (Y); also elsewhere on the board
REC_PROX1: R129.1; also elsewhere on the board
REC_PROX2: R130.1; also elsewhere on the board

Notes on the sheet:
Do not populate
4xANDGate : 5V @ 4mA 5xNOTGate : 5V @ 5mA Total current : 5V @ 9,55mA
Debouncing

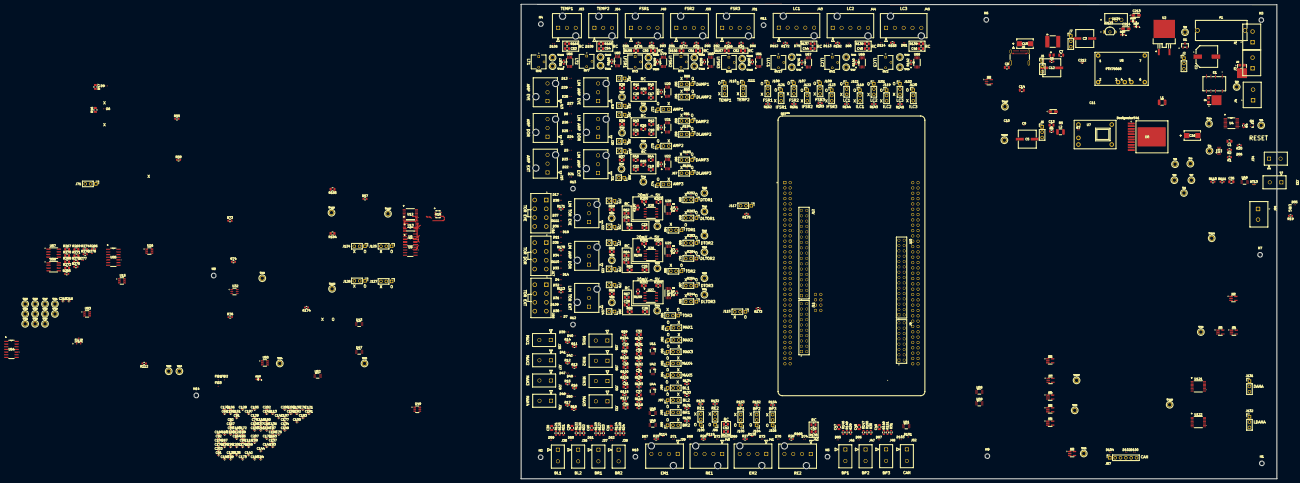
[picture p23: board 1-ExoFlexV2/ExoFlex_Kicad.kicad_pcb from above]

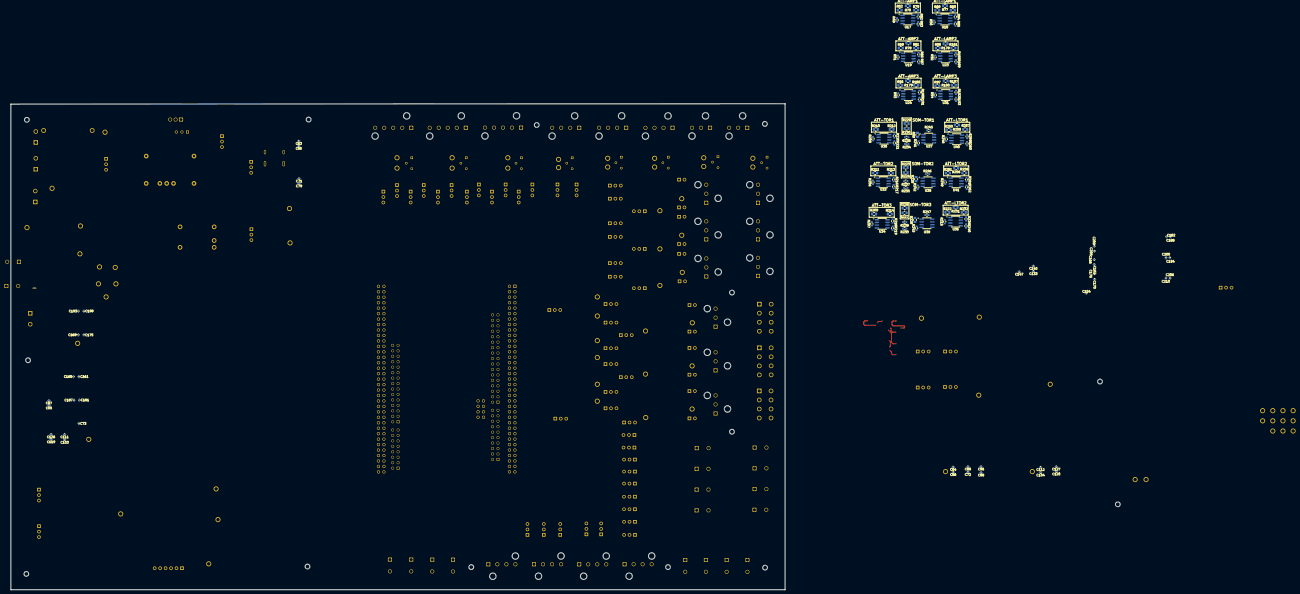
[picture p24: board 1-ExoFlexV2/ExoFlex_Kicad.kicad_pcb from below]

Board: 4 copper layers, 360.3 x 226.2 mm, 849 parts (150 on the bottom side), 438 nets.

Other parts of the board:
J55, J56, J58, J59, J66, J67: Jumper; PinHeader_1x03_P2.54mm_Vertical
R49, R50, R51, R82, R83, R84, R85, R86, R87, R92, R93, R94, R188, R189, R190, R191, R192, R193: 10K 1% 1/10W; R_0603_1608Metric
R52, R68, R69, R70, R77, R78, R95, R96, R97, R178, R179, R180: 3.3k 1% 1/8W; R_0805_2012Metric
R79, R80, R81, R181, R186, R187: 0Ω; R_0805_2012Metric
R88, R90, R91, R194, R195, R196: 100k 1% 1/20W; R_0201_0603Metric
U17, U18, U19, U23, U24, U31: OP_AMP2; SOIC127P599X175-8N

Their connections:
+5VA: U17.8 (VCC+), U18.8 (VCC+), U19.8 (VCC+), U23.8 (VCC+), U24.8 (VCC+), U31.8 (VCC+); also elsewhere on the board
-5VA: U17.4 (VCC-), U18.4 (VCC-), U19.4 (VCC-), U23.4 (VCC-), U24.4 (VCC-), U31.4 (VCC-); also elsewhere on the board
DOR_AMP_DATA: J58.2; also elsewhere on the board
DOR_AMP_DATA1: R51.1; also elsewhere on the board
DOR_AMP_LIM_DATA: J59.2; also elsewhere on the board
DOR_AMP_LIM_DATA1: R92.1; also elsewhere on the board
EVE_AMP_DATA: J55.2; also elsewhere on the board
EVE_AMP_DATA1: R49.1; also elsewhere on the board
EVE_AMP_LIM_DATA: J56.2; also elsewhere on the board
EVE_AMP_LIM_DATA1: R50.1; also elsewhere on the board
EXT_AMP_DATA: J66.2; also elsewhere on the board
EXT_AMP_DATA1: R93.1; also elsewhere on the board
EXT_AMP_LIM_DATA: J67.2; also elsewhere on the board
EXT_AMP_LIM_DATA1: R94.1; also elsewhere on the board
GND: R88.2, R90.2, R91.2, R194.2, R195.2, R196.2, U17.3 (1IN+), U17.5 (2IN+), U18.3 (1IN+), U18.5 (2IN+), U19.3 (1IN+), U19.5 (2IN+), U23.3 (1IN+), U23.5 (2IN+), U24.3 (1IN+), U24.5 (2IN+), U31.3 (1IN+), U31.5 (2IN+); also elsewhere on the board
unnamed: J55.1, R83.1, U17.7 (2OUT)
unnamed: J55.3, R88.1
unnamed: J56.1, R85.1, U18.7 (2OUT)
unnamed: J56.3, R90.1
unnamed: J58.1, R87.1, U19.7 (2OUT)
unnamed: J58.3, R91.1
unnamed: J59.1, R189.1, U23.7 (2OUT)
unnamed: J59.3, R194.1
unnamed: J66.1, R191.1, U24.7 (2OUT)
unnamed: J66.3, R195.1
unnamed: J67.1, R193.1, U31.7 (2OUT)
unnamed: J67.3, R196.1
unnamed: R49.2, R52.1, U17.2 (1IN-)
unnamed: R50.2, R68.1, U18.2 (1IN-)
unnamed: R51.2, R69.1, U19.2 (1IN-)
unnamed: R52.2, R70.1
unnamed: R68.2, R77.1
unnamed: R69.2, R78.1
unnamed: R70.2, R79.1
unnamed: R77.2, R80.1
unnamed: R78.2, R81.1
unnamed: R79.2, R82.2, U17.1 (1OUT)
unnamed: R80.2, R84.2, U18.1 (1OUT)
unnamed: R81.2, R86.2, U19.1 (1OUT)
unnamed: R82.1, R83.2, U17.6 (2IN-)
unnamed: R84.1, R85.2, U18.6 (2IN-)
unnamed: R86.1, R87.2, U19.6 (2IN-)
unnamed: R92.2, R95.1, U23.2 (1IN-)
unnamed: R93.2, R96.1, U24.2 (1IN-)
unnamed: R94.2, R97.1, U31.2 (1IN-)
unnamed: R95.2, R178.1
unnamed: R178.2, R181.1
unnamed: R96.2, R179.1
unnamed: R179.2, R186.1
unnamed: R97.2, R180.1
unnamed: R180.2, R187.1
unnamed: R181.2, R188.2, U23.1 (1OUT)
unnamed: R186.2, R190.2, U24.1 (1OUT)
unnamed: R187.2, R192.2, U31.1 (1OUT)
unnamed: R188.1, R189.2, U23.6 (2IN-)
unnamed: R190.1, R191.2, U24.6 (2IN-)
unnamed: R192.1, R193.2, U31.6 (2IN-)

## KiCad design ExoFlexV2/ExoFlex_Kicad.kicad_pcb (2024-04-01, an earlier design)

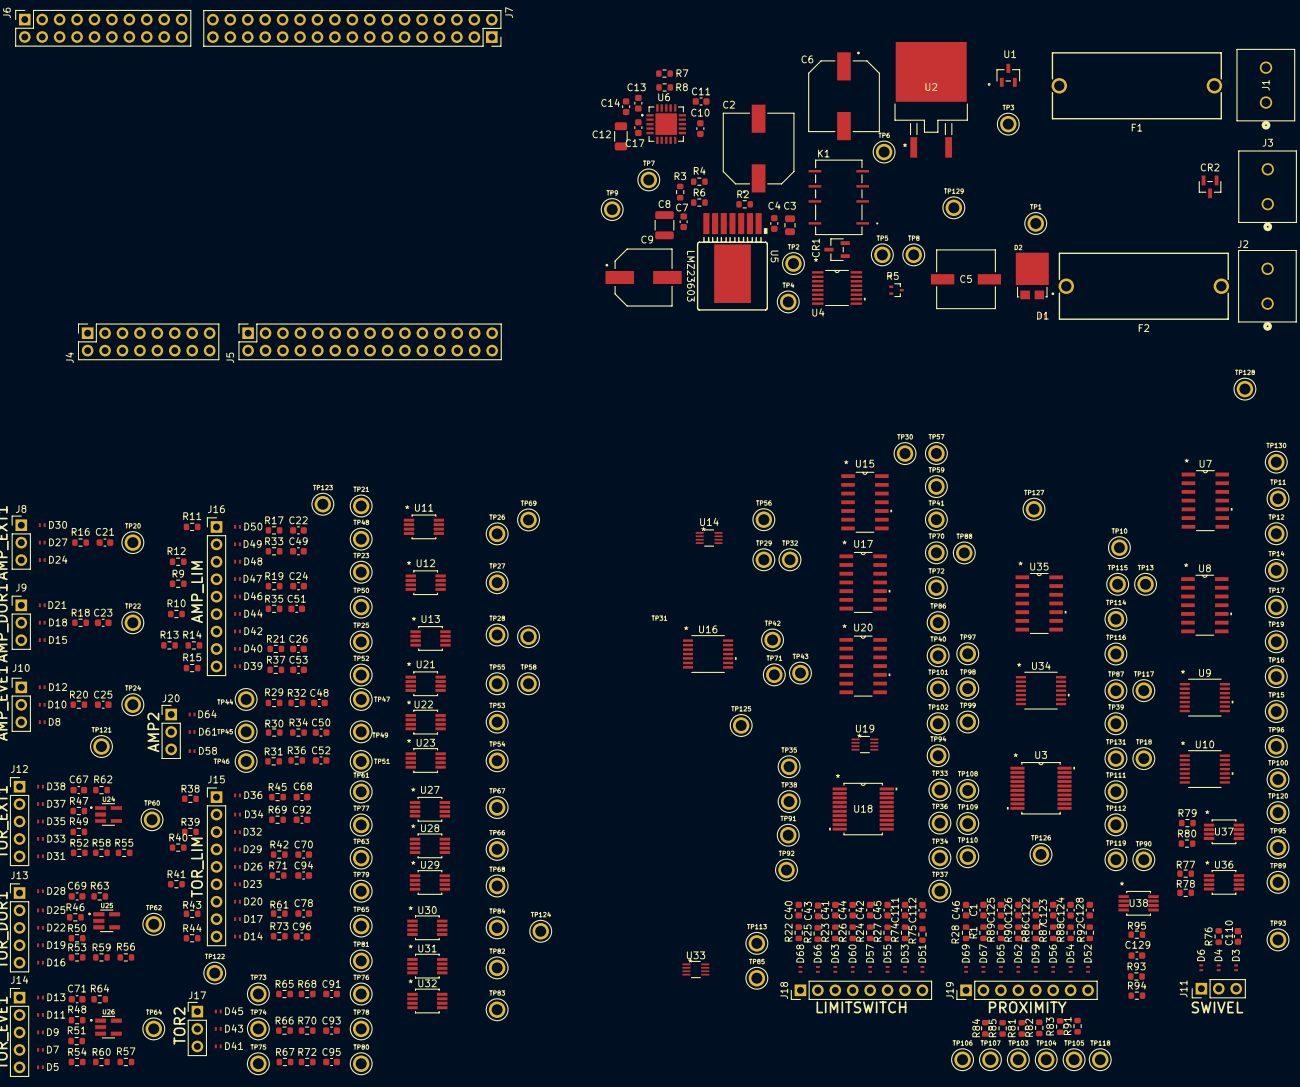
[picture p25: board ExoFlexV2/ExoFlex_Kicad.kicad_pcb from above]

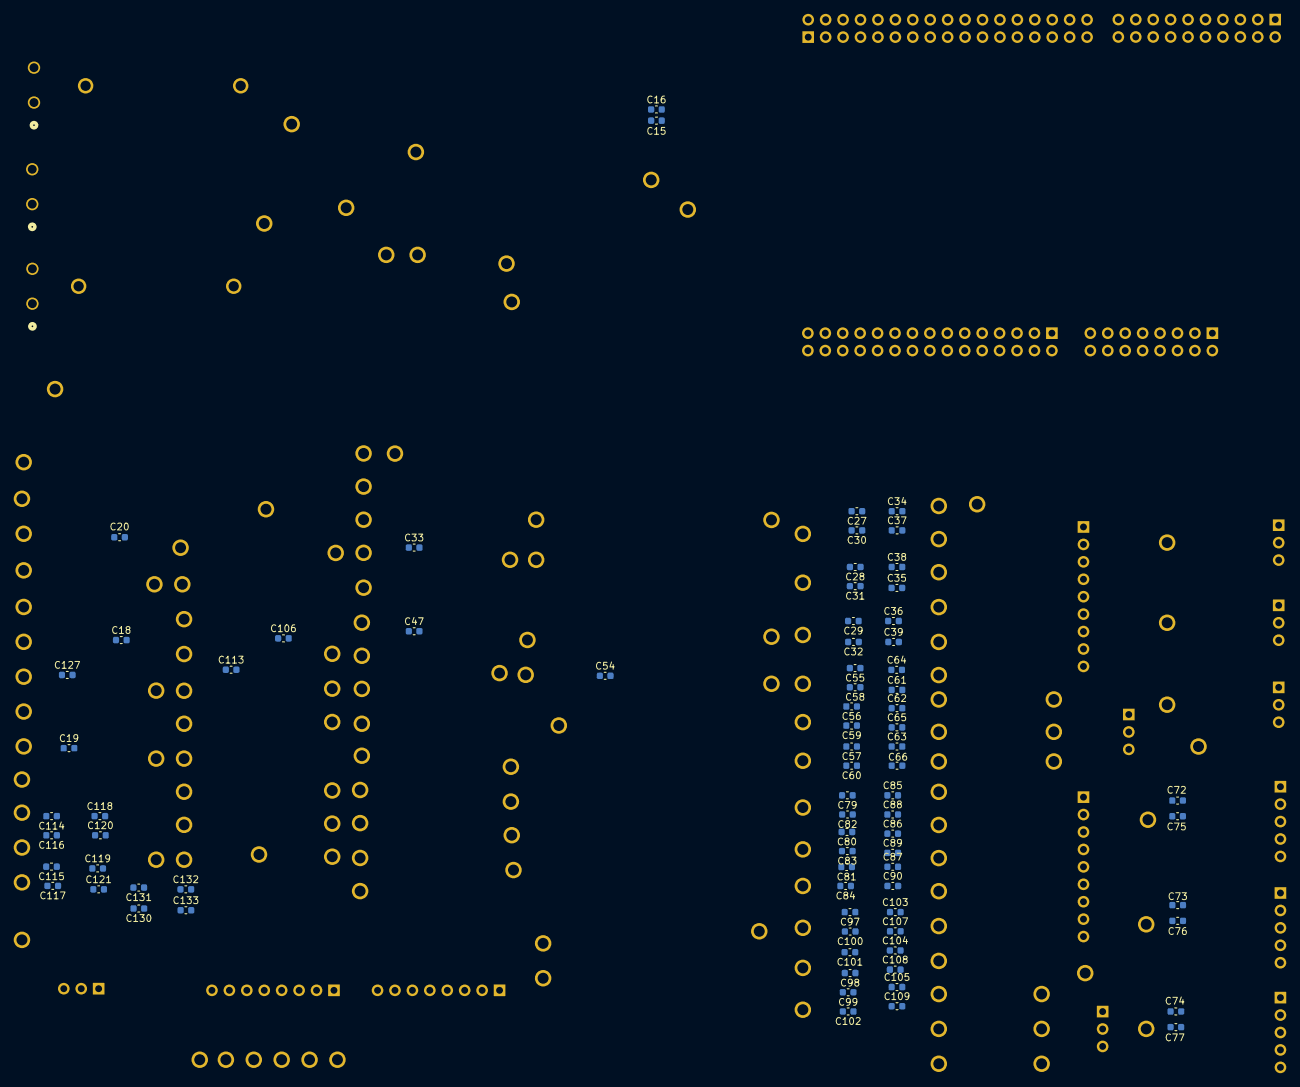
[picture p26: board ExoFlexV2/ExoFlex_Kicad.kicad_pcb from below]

Board: 2 copper layers, 491 parts (77 on the bottom side), 208 nets, no tracks yet.

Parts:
C1, C10, C13, C14, C15, C16, C17, C40, C41, C42, C43, C44, C45, C46, C111, C112, C122, C123, C124, C125, C126: 10uF; C_0603_1608Metric
C2: 150uF 50V; CAP_EEHZS1H151P
C3: 10 uF; C_0805_2012Metric
C4, C7: 0,047uF; C_0603_1608Metric
C5: 100uF 20V; CAP_PC_8X7_NCH
C6: 220uF 50V; CAP_EEHZS1H221P
C8: 100uF; C_1210_3225Metric
C9: 220uF 20V; CAP_20SVPK220M
C11, C18, C19, C20, C75, C76, C77: 1uF; C_0603_1608Metric
C12: 47uF; C_1206_3216Metric
C21, C22, C23, C24, C25, C26, C48, C49, C50, C51, C52, C53, C67, C68, C69, C70, C71, C78, C91, C92, C93, C94, C95, C96, C110, C128, C129: 1nF; C_0603_1608Metric
C27, C28, C29, C30, C31, C32, C34, C35, C36, C37, C38, C39, C55, C56, C57, C58, C59, C60, C61, C62, C63, C64, C65, C66, C79, C80, C81, C82, C83, C84, C85, C86, C87, C88, C89, C90, C97, C98, C99, C100, C101, C102, C103, C104, C105, C107, C108, C109, C114, C115, C116, C117, C118, C119, C120, C121, C130, C131, C132, C133: 0,01uF; C_0603_1608Metric
C33, C47, C54, C72, C73, C74, C106, C113, C127: 0,1uF; C_0603_1608Metric
CR1: 1SS321_LF
CR2: TBAT54_LM
D1, D3, D4, D5, D6, D7, D8, D9, D10, D11, D12, D13, D14, D15, D16, D17, D18, D19, D20, D21, D22, D23, D24, D25, D26, D27, D28, D29, D30, D31, D32, D33, D34, D35, D36, D37, D38, D39, D40, D41, D42, D43, D44, D45, D46, D47, D48, D49, D50, D51, D52, D53, D54, D55, D56, D57, D58, D59, D60, D61, D62, D63, D64, D65, D66, D67, D68, D69: TPD1E; DPY2_TEX
D2: SS12P2L-M3_86A; DIO_SS12P2L-M3_86A
F1: FSF5X20 200mA; 696108003002
F2: FSF5X20 500mA; 696108003002
J1, J3: 24V; TerminalBlock14AWG
J2: 5V; TerminalBlock14AWG
J4: CN8; PinSocket_2x08_P2.54mm_Vertical
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

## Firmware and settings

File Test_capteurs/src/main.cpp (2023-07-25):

#include <Arduino.h>
#include <Wire.h>

#define PIN_POTENTIO A0

// Constants and variables
const int MPU = 0x68;  // MPU6050 I2C address
float     AccX, AccY, AccZ;
float     GyroX, GyroY, GyroZ;
float     accAngleX, accAngleY, gyroAngleX, gyroAngleY, gyroAngleZ;
float     roll, pitch, yaw;
float     AccErrorX, AccErrorY, GyroErrorX, GyroErrorY, GyroErrorZ;
float     elapsedTime, currentTime, previousTime;
int       c = 0;

// Function prototypes here
void calculateImuError();
void setupImu();
void readAcc();
void readGyro();
void readBoth();
int  rawValueToDegree();

void setup()
{
    Serial.begin(9600);
    // Setup for IMU
    pinMode(PIN_POTENTIO, INPUT);
    setupImu();
}

void loop()
{
    // === Read acceleromter data === //
    Wire.beginTransmission(MPU);
    Wire.write(0x3B);  // Start with register 0x3B (ACCEL_XOUT_H)
    Wire.endTransmission(false);
    Wire.requestFrom(MPU, 6, true);  // Read 6 registers total, each axis value
                                     // is stored in 2 registers
    // For a range of +-2g, we need to divide the raw values by 16384, according
    // to the datasheet
    AccX = (Wire.read() << 8 | Wire.read()) / 16384.0;  // X-axis value
    AccY = (Wire.read() << 8 | Wire.read()) / 16384.0;  // Y-axis value
    AccZ = (Wire.read() << 8 | Wire.read()) / 16384.0;  // Z-axis value
    // Calculating Roll and Pitch from the accelerometer data
    accAngleX = (atan(AccY / sqrt(pow(AccX, 2) + pow(AccZ, 2))) * 180 / PI) -
                0.58;  // AccErrorX ~(0.58) See the calculate_IMU_error()custom
                       // function for more details
    accAngleY =
        (atan(-1 * AccX / sqrt(pow(AccY, 2) + pow(AccZ, 2))) * 180 / PI) +
        1.58;  // AccErrorY ~(-1.58)
    // === Read gyroscope data === //
    previousTime =
        currentTime;  // Previous time is stored before the actual time read
    currentTime = millis();  // Current time actual time read
    elapsedTime =
        (currentTime - previousTime) / 1000;  // Divide by 1000 to get seconds
    Wire.beginTransmission(MPU);
    Wire.write(0x43);  // Gyro data first register address 0x43
    Wire.endTransmission(false);
    Wire.requestFrom(MPU, 6, true);  // Read 4 registers total, each axis value
                                     // is stored in 2 registers
    GyroX = (Wire.read() << 8 | Wire.read()) /
            131.0;  // For a 250deg/s range we have to divide first the raw
                    // value by 131.0, according to the datasheet
    GyroY = (Wire.read() << 8 | Wire.read()) / 131.0;
    GyroZ = (Wire.read() << 8 | Wire.read()) / 131.0;
    // Correct the outputs with the calculated error values
    GyroX = GyroX + 0.56;  // GyroErrorX ~(-0.56)
    GyroY = GyroY - 2;  // GyroErrorY ~(2)
    GyroZ = GyroZ + 0.79;  // GyroErrorZ ~ (-0.8)
    // Currently the raw values are in degrees per seconds, deg/s, so we need to
    // multiply by sendonds (s) to get the angle in degrees
    gyroAngleX = gyroAngleX + GyroX * elapsedTime;  // deg/s * s = deg
    gyroAngleY = gyroAngleY + GyroY * elapsedTime;
    yaw        = yaw + GyroZ * elapsedTime;
    // Complementary filter - combine acceleromter and gyro angle values
    roll  = 0.96 * gyroAngleX + 0.04 * accAngleX;
    pitch = 0.96 * gyroAngleY + 0.04 * accAngleY;

    gyroAngleX = roll;
    gyroAngleY = pitch;

    // Print the values on the serial monitor
    Serial.print(roll);
    Serial.print("/");
    Serial.print(pitch);
    Serial.print("/");
    Serial.println(yaw);

    Serial.println(rawValueToDegree());

    delay(100);
}

void calculateImuError()
{
    // We can call this funtion in the setup section to calculate the
    // accelerometer and gyro data error. From here we will get the error values
    // used in the above equations printed on the Serial Monitor. Note that we
    // should place the IMU flat in order to get the proper values, so that we
    // then can the correct values Read accelerometer values 200 times
    while (c < 200)
    {
        Wire.beginTransmission(MPU);
        Wire.write(0x3B);
        Wire.endTransmission(false);
        Wire.requestFrom(MPU, 6, true);
        AccX = (Wire.read() << 8 | Wire.read()) / 16384.0;
        AccY = (Wire.read() << 8 | Wire.read()) / 16384.0;
        AccZ = (Wire.read() << 8 | Wire.read()) / 16384.0;
        // Sum all readings
        AccErrorX =
            AccErrorX +
            ((atan((AccY) / sqrt(pow((AccX), 2) + pow((AccZ), 2))) * 180 / PI));
        AccErrorY =
            AccErrorY +
            ((atan(-1 * (AccX) / sqrt(pow((AccY), 2) + pow((AccZ), 2))) * 180 /
              PI));
        c++;
    }
    // Divide the sum by 200 to get the error value
    AccErrorX = AccErrorX / 200;
    AccErrorY = AccErrorY / 200;
    c         = 0;
    // Read gyro values 200 times
    while (c < 200)
    {
        Wire.beginTransmission(MPU);
        Wire.write(0x43);
        Wire.endTransmission(false);
        Wire.requestFrom(MPU, 6, true);
        GyroX = Wire.read() << 8 | Wire.read();
        GyroY = Wire.read() << 8 | Wire.read();
        GyroZ = Wire.read() << 8 | Wire.read();
        // Sum all readings
        GyroErrorX = GyroErrorX + (GyroX / 131.0);
        GyroErrorY = GyroErrorY + (GyroY / 131.0);
        GyroErrorZ = GyroErrorZ + (GyroZ / 131.0);
        c++;
    }
    // Divide the sum by 200 to get the error value
    GyroErrorX = GyroErrorX / 200;
    GyroErrorY = GyroErrorY / 200;
    GyroErrorZ = GyroErrorZ / 200;
    // Print the error values on the Serial Monitor
    Serial.print("AccErrorX: ");
    Serial.println(AccErrorX);
    Serial.print("AccErrorY: ");
    Serial.println(AccErrorY);
    Serial.print("GyroErrorX: ");
    Serial.println(GyroErrorX);
    Serial.print("GyroErrorY: ");
    Serial.println(GyroErrorY);
    Serial.print("GyroErrorZ: ");
    Serial.println(GyroErrorZ);
}

void setupImu()
{
    Wire.begin();  // Initialize comunication
    Wire.beginTransmission(
        MPU);  // Start communication with MPU6050 // MPU=0x68
    Wire.write(0x6B);  // Talk to the register 6B
    Wire.write(0x00);  // Make reset - place a 0 into the 6B register
    Wire.endTransmission(true);  // end the transmission

    calculateImuError();
    delay(20);
}

int rawValueToDegree()
{
    int rawValue = analogRead(PIN_POTENTIO);
    int degree   = map(rawValue, 0, 1023, 0, 255);
    return degree;
}

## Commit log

2023-07-25 push elec folders
    [ExoFlex_Kicad.kicad_pcb, ExoFlex_Kicad.kicad_sch]
2023-07-27 push code elec
    [DIOM6859X262N.step, ExoFlex_Kicad.kicad_pcb, ExoFlex_Kicad.kicad_sch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]
2023-10-16 Ajout des capteurs de courant, loadcell et potentiomètre et remplacement du stm32 par Raspberry Pi 4
    [ACS712.step, ExoFlex_Kicad.kicad_sch, sensors.kicad_sch]
2023-10-21 Backup du stm32
    [ExoFlex_Kicad.kicad_sch]
2024-02-05 Plein de modification
    Beaucoup trop pour que le commit soit intéressant
    [ExoFlex_Kicad.kicad_sch, blockdiagram.kicad_sch, currentsensors.kicad_sch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]
2024-02-07 Schematic structure
    Ajout des Encodeur magnétique et load cells, début de circuit de comparateurs
    [ExoFlex_Kicad.kicad_sch, loadcells.kicad_sch, magneticencoder.kicad_sch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]
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2024-03-21 Many changes
    Debouncing, power protection, potentiometer limits, etc.
    [5005.step, ExoFlex_Kicad.kicad_pcb, ExoFlex_Kicad.kicad_sch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]
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2024-03-31 Placement
    Début du placement et modification d'après dernier review
    [ExoFlex_Kicad.kicad_pcb, ExoFlex_Kicad.kicad_sch, connectors.kicad_sch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]
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2024-06-27 Mise à jour mi-stage
    - Torque et Amplitude testé et vérifié
    - Capteur de présence et de proximité testé
    - Système de détection de coupure de fils
    - Polyvalence pour plusieurs capteurs
    [1751099.step, 1751109.step, 1751112.step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]
2024-06-27 Mise à jour signaux STM
    - Condo de découplage
    - Signaux supplémentaire pour le STM
    - Page GND sera pour Multiplexeur
    [ExoFlex_Kicad.kicad_sch, conn_others.kicad_sch, conn_positioning.kicad_sch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]
2024-06-28 Gestion de multiple signaux
    - Ajout de multiplexeur 8:1 pour les signaux analogique supplémentaire
    - Ajout de multiplexeur 8:1 arranger sous forme d'un 32:1
    - Ajout du footprint pour le mux choisis
    [ExoFlex_Kicad.kicad_sch, SN74F251BDR.step, SOT403-1_NXP.step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]
2024-07-10 Finalisation 1
    - Ajout de pages pour la gestion des signaux négatif
    - Modification des pages de torque et amplitude
    [CAPC220145_88N_KEM.step, CAP_PC_10X12P7_NCH.step, DCY0004A.stp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]
2024-07-10 Finalisation 2
    -Ajout des nouveaux comparateurs
    - Ajout d'une page découplage
    - Retrait des condensateur dans les autres pages
    - Ajout de trimmer pour les résistance importante mais incertaines
    [1751099.step, 1751109.step, 1751112.step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]
2024-07-11 Chokes et RC
    - Ajout des RF chokes
    - Changement des résistance pour 0805
    [ExoFlex_Kicad.kicad_sch, LBR2012T100K.step, blockdiagram.kicad_sch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]
2024-07-11 Trimmer et jumper
    -Changement de symbole de jumper
    -Ajout des des trimmer aux endroits nécessaires
    [ExoFlex_Kicad.kicad_sch, conn_positioning.kicad_sch, conn_proximity.kicad_sch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]
2024-07-12 Test points et notes
    - Ajout de tous les tests point nécessaires
    - Ajoute des sections de notes dans chaque page
    [ExoFlex_Kicad.kicad_sch, conn_others.kicad_sch, conn_positioning.kicad_sch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]
2024-07-17 Schématisation terminée
    - Schéma terminé
    - Passage vers le PCB
    [ExoFlex_Kicad.kicad_sch, LQH2HPN4R7MDRL.step, PTN78060WAH.step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]
2024-07-18 Bug NetList
    - Ajout de net-tie pour les GND et et les +5V
    [ExoFlex_Kicad.kicad_sch, TEST.kicad_sch, conn_others.kicad_sch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]
2024-07-18 PLACEMENT 1
    - Placement des connnecteurs
    [ExoFlex_Kicad.kicad_pcb, ExoFlex_Kicad.kicad_sch, PTN78020WAD.step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]
2024-07-29 Finalisation 3
    - Changement des régulateur de tension
    - Retrait de test point inutile
    - Changement de jumper mal positionner
    - Ajout de Mounting holes et fiducial
    [1054500101.step, 1755532.step, 1755736.step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]
2024-08-03 Finalisation schéma FIN
    - Changement des uméro pour les inverseurs
    - Changement des connecteur et début de placement
    [0039281083.step, 039281023.stp, 039301039.stp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]
2024-08-05 Placement 1
    - Placement de tous les connecteur
    - Placement de tous les test point
    [ExoFlex_Kicad.kicad_pcb, position_sensor2.kicad_sch, positionning_sensors3.kicad_sch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]
2024-08-06 PLacement 2
    - Puissance
    - signaux
    -
    [ExoFlex_Kicad.kicad_sch, decoupling.kicad_sch, powersecurity.kicad_sch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]
2024-08-08 Modification Schéma + Layout
    - Ajout de RC potentiel entre les capteur de torque et l'ampli d'instru
    [ExoFlex_Kicad.kicad_sch, decoupling.kicad_sch, loadcells.kicad_sch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]
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2024-08-09 Routage 3
    - Routage des connecteurs terminé
    - Routage des signaux terminé
    [ExoFlex_Kicad.kicad_sch, conn_proximity.kicad_sch, stmsignal.kicad_sch]
2024-08-09 Routage Fin
    - Alimentation router
    - Urg Sec dans le OR gate vers Alim Sec
    - Changement d'un condo
    [ExoFlex_Kicad.kicad_sch, powertree.kicad_sch, security_manager.kicad_sch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]
2024-08-12 Routage pour Review 1
    - Replacement des test point pour faciliter le rework
    - Correction des erreurs dans le BOM
    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
    [ExoFlex_Kicad.kicad_sch, conn_others.kicad_sch, limit_switch_amplitude.kicad_sch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]
2024-08-14 Layout Review 1
    - Routing fone Alimentation et ADC
    [ExoFlex_Kicad.kicad_sch, conn_proximity.kicad_sch, powertree.kicad_sch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]
2024-08-14 Routing final 3
    - Some stuff
    [loadcells.kicad_sch]
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2025-02-27 Analyse Post-PMC
    -Modification du footprint du régulateur de tension
    - Inversion des condos et diode sur les tensions négative
    [magnetic_encoder_amplitude.kicad_sch, magneticencoderadc.kicad_sch, powertree.kicad_sch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]
